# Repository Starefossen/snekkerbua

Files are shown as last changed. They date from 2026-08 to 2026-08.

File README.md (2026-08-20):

# snekkerbua



*der Hans gjør ting han (ennå) ikke kan*

Et verkstedrepo, én katalog per prosjekt. Alle prosjektene her er bygd på samme
måte: modellen er parametrisk og er den eneste kilden, manualen genereres ut av
solidene i stedet for å skrives ved siden av dem, og ingenting får finnes før
maskinen har sjekket det.

## Prosjekter

| | | |
|---|---|---|
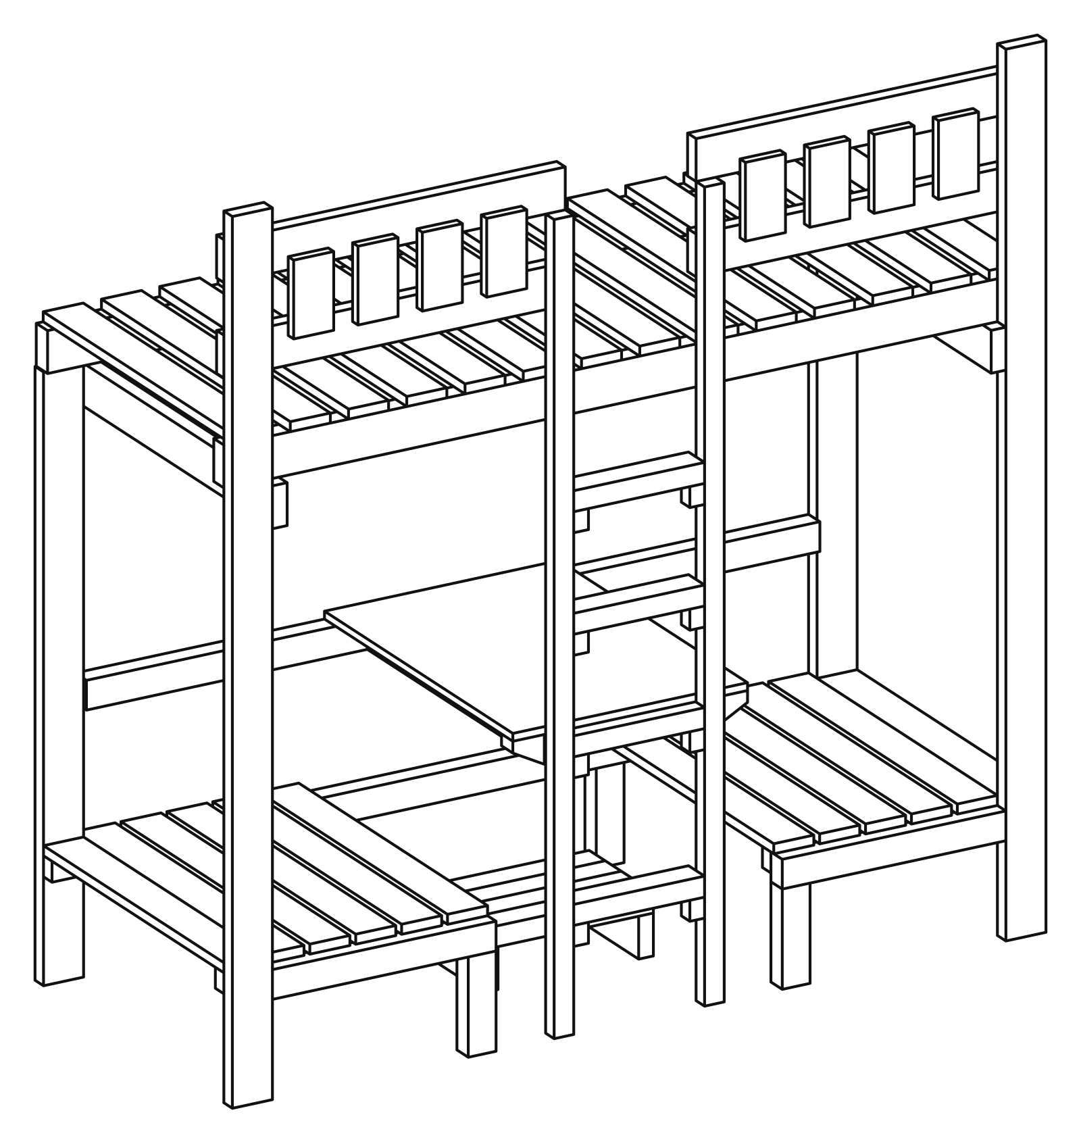
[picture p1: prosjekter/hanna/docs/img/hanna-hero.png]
HANNA
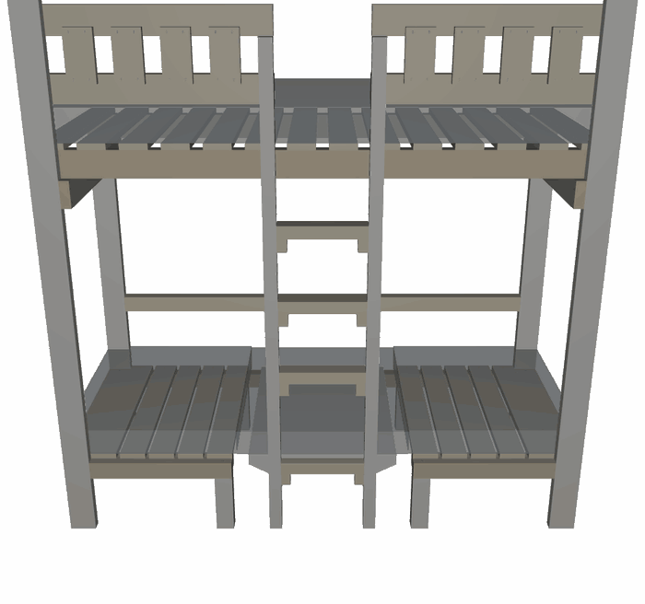
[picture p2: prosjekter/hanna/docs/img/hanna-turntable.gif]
Én omdreining
|  | **[HANNA](prosjekter/hanna/)** — en loftseng med sofa, bord og ekstraseng under, bygd for én nisje på 199 cm. 72 trestykker, 172 festemidler modellert som solider, og en trykkeklar monteringsmanual kompilert av modellen. |  |

## Felles

* **[PRAKSIS.md](PRAKSIS.md)** — reglene som gjelder på tvers av prosjektene.
* **[UTSTYR.md](UTSTYR.md)** — verktøyparken og innkjøpsplanen. Ett verksted, én
  beholdning, uansett hvor mange prosjekter som står i det.

Kortversjonen av PRAKSIS:

* **Én kilde.** Hvert tall i dokumentasjonen *kommer fra* modellen — ikke «er
  kopiert fra». Må to filer være enige om et tall, er tallet på feil sted.
* **En assert er et forhold**, utledet av fysikk eller en standard, aldri en
  gjentakelse av en konstant — og den sier hvor man retter det når den ryker.
* **Regler, ikke tilfeller.** Hvordan en ting behandles er en egenskap ved
  tingen, definert ett sted. Ingen `if` på et navn, ingen bryter noen må huske å
  skru på.
* **Et tegnet valg måles, det argumenteres ikke.** Prøven klippes ut av den
  ferdige siden, og en snubletråd-assert måler blekket etterpå.
* **Alt utledet er sjekket inn**, så `git diff --stat` etter et bygg *er*
  konsekvensanalysen.
* **Determinismen er en assert, ikke en forventning.** `mise run check` kjører
  hele kjeden to ganger og krever byte-identisk resultat.

## Kom i gang

Krever [`mise`](https://mise.jdx.dev/). Det er én oppgavefil, `mise.toml`, her på
rota, og hver oppgave kjører med sitt eget prosjekt som arbeidskatalog — så en
kommando er den samme kommandoen uansett hvor i treet du skriver den:

```bash
mise run build      # modellen + hver generert tabell og dokument
mise run montering  # tegn strektegningene på nytt
mise run check      # kjør hele kjeden to ganger, krev byte-identisk resultat
mise run pdf        # den trykkeklare manualen
```

Hele runden for HANNA er `mise run build && montering && check && pdf && usdz &&
film-check`. Forutsetningene for hvert prosjekt og resten av oppgavene står i
prosjektets egen README.

## Sjekk selv

Ikke ta badgen på ordet — tre kommandoer, fra ingenting:

```bash
git clone https://github.com/Starefossen/snekkerbua.git && cd snekkerbua
mise trust && mise run install   # python 3.11 + requirements.txt
mise run build && mise run montering && mise run check
```

`check` bygger hele kjeden to ganger og sammenligner SHA-256 av hver innsjekket,
utledet fil — tabellene, `docs/MONTERING.md`, hver eneste tegning, `parts.tsv`.
*Byte-identisk* betyr nøyaktig det: ikke «ser like ut», ikke «samme tall», de
samme bytene. Kan en kjøring gi to svar på det samme spørsmålet, er en diff på
tegningene ikke bevis på noe som helst, og resten av dette repoet er en
fortelling i stedet for et bevis. Den samme porten kjører på hver push —
[`.github/workflows/check.yml`](.github/workflows/check.yml). Å pushe en
`<prosjekt>-v*`-tag kjører i tillegg
[`release.yml`](.github/workflows/release.yml), som bygger
manualen og 3D-modellene på macOS (`.usdz`-kjeden går bare med Xcode) og legger
dem ved releasen.

Du trenger også `rsvg-convert` til PNG-ene (`brew install librsvg`, eller
`apt install librsvg2-bin`); workflow-fila er den nøyaktige lista. `mise run
pdf` vil ha to til: en Chrome å skrive ut med og poppler til å lese resultatet
tilbake med.

`git log --oneline` er designdagboka — hver commit er én beslutning, med
begrunnelsen i brødteksten.

## In English

**snekkerbua** is a workshop repo — one directory per project, each of them a
piece of furniture built from a parametric model. The model is the only source
of truth: every drawing, every table and every page of the printed assembly
manual is generated from the solids and machine-checked before it is allowed to
exist. The documentation is written in Norwegian, because that is the language
of whoever is standing at the saw. The proofs, on the other hand, run in CI:
`mise run check` builds the whole chain twice and demands byte-identical output,
and the badge at the top of this page is that gate.

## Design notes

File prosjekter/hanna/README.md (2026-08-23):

# HANNA — loftsengen der manualen kompileres, ikke skrives



*Det første prosjektet i [snekkerbua](../../README.md). Felles praksis:
[PRAKSIS.md](../../PRAKSIS.md) · verkstedets utstyr:
[UTSTYR.md](../../UTSTYR.md).*

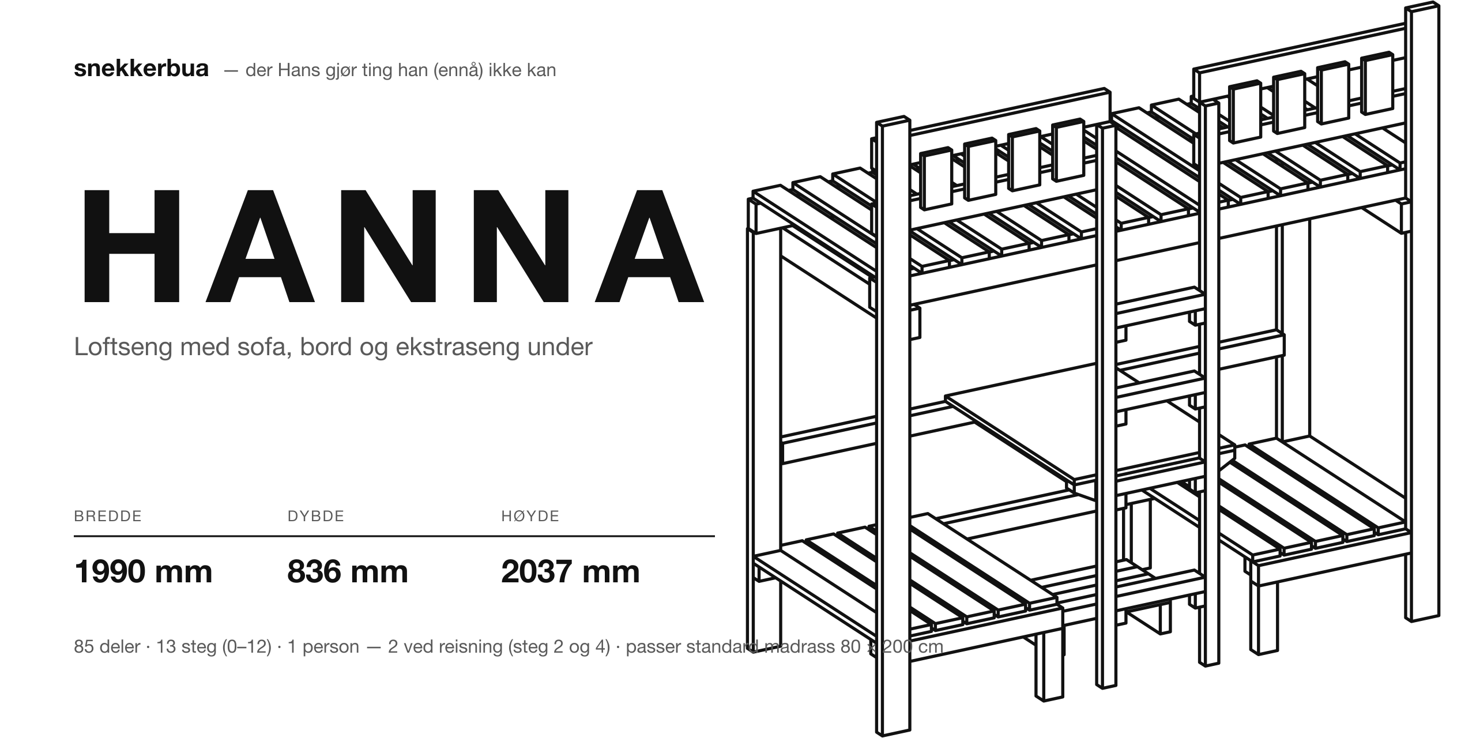
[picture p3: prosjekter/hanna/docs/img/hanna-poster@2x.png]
HANNA — loftseng med sofa, bord og ekstraseng under


Den ferdige sengen, én omdreining

*48 rammer av solidene, tatt opp med `usdrecord` og satt sammen av
`tools/render_animasjon.py`. Deterministisk: rammenummeret driver kameraet, så
samme modell gir samme bytes.*

En parametrisk loftseng i [build123d](https://github.com/gumyr/build123d) /
OpenCascade, bygd for én nisje på 199 cm mellom to vegger. Modellen er den
eneste kilden: **hver tegning, hver tabell og alle 32 sidene i byggeheftet og
alle 62 i referanseheftet genereres av solidene og maskinsjekkes før de får
finnes.** Ikke ett mål er skrevet av. Unntaket er fire skjemaark i `docs/schematics/`,
som er tegnet for hånd — der et tall på et slikt ark er i strid med en
generert tabell, er det tabellen som gjelder.

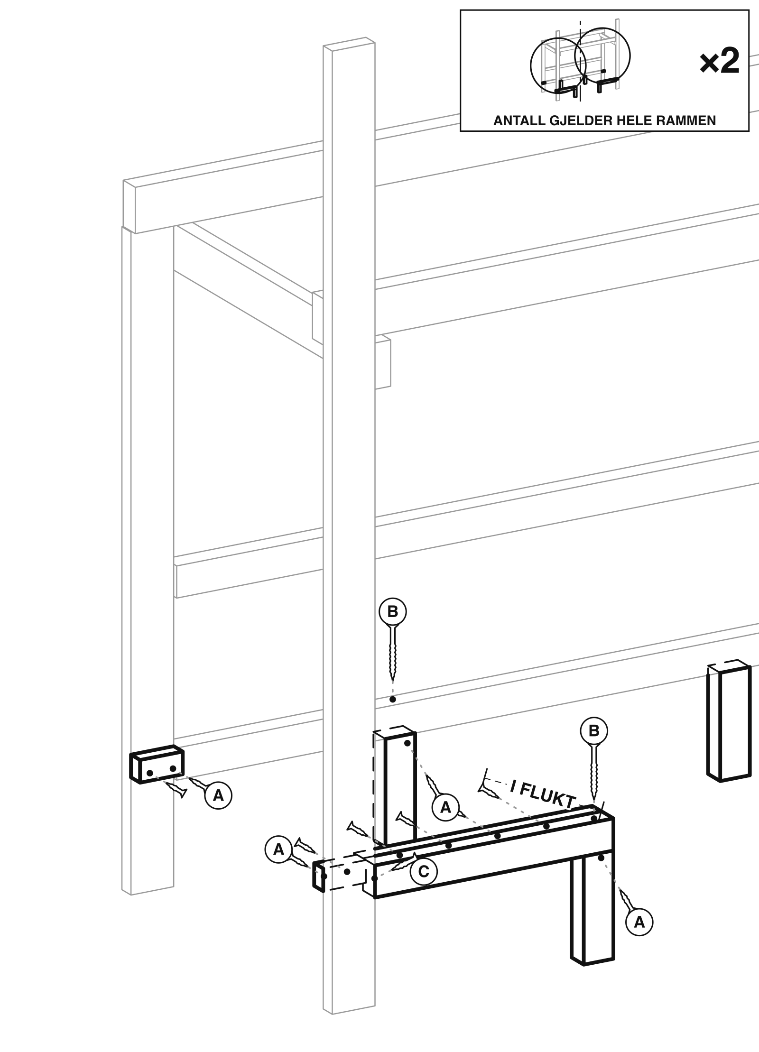
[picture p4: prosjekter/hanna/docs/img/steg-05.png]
Steg 5 i den genererte monteringsmanualen


*Steg 5, tegnet av `tools/render_lineart.py`. Sengen er en
skjult-linje-projeksjon av de virkelige B-rep-solidene. Hver skrue er en
modellert kropp, eksplodert langs sin egen drivakse, i sin sanne lengde.
Bokstavene, fyllkoden, antallene i beslaglegenden under bildet og halvsnittet
er alle utledet — og en assert som feller bygget måler det ferdige blekket og beviser at
hvert merke står på det festemiddelet det navngir.*

---

## Nøkkeltall

| | |
|---|---|
| **Ytre mål** | 1990 × 836 × 2037 mm — fyller nisjen fra vegg til vegg på 1990 mm, i et rom med 2450 mm takhøyde, og gir 1500 mm fri høyde under køya. Gjennomgående deler kappes 1984 mm, for et bord på 1990 mm lar seg ikke svinge inn i en åpning på 1990 mm |
| **Trevirke** | **85 stykker** i **5 dimensjoner** pluss én 18 mm kryssfinerplate — 55,07 løpemeter. Fordelingen: 23×98 34 stk. · 48×68 20 stk. · 36×48 16 stk. · 36×98 12 stk. · 48×98 2 stk. · plata 1 stk. 24 av de 85 stykkene er ett og samme stykke: spilen, 23×98 × 800 mm, kappet i én innstilling. Tallene telles av modellen og står nederst i [kapplista](docs/generated/kappliste.md) — `TOTAL 85 pcs 55.07 m in 5 timber profiles + 1 sheet` er det modellen skriver ut mens den bygger |
| **Stål** | **203 festemidler fordelt på 26 ledd**, **194 av dem modellert som solide kropper** — hode, forsenking, skaft og spiss, hver med sin egen drivvektor. De 9 som mangler er de to veggfestene, J14 og J12-V: de går rett inn i veggen og har ingen andre del å ende i, så de er plassert, men ikke modellert. **Ikke ett eneste hode står i en romvendt flate**, og det er en assert. Begge tallene skriver modellen ut selv — `203 festemidler plassert i 26 ledd` og `194 festemidler modellert som kropper` |
| **Kontroller** | **520 asserter i modellen** og 237 til i verktøyene, alle sammen stopper bygget — tallene er talt, ikke anslått, og de telles som `ast.Assert`-noder i syntakstreet, ikke med grep: en grep på linjer som begynner med ordet «assert» tar med brødtekst som gjør det samme, og gir 527 her. Metoden er `python -c "import ast,sys;print(sum(isinstance(n,ast.Assert) for n in ast.walk(ast.parse(open(sys.argv[1]).read()))))" generate_loftbed.py`, og den samme summen over `tools/*.py` (24 filer) — men ingen runde arver dem lenger: `tools/check_tall.py` teller dem på nytt i porten og feller bygget hvis denne tabellen sier noe annet enn det den finner. Skrueretningene er utledet av fysikk (7 av de 24 radene i [skrueretningene](docs/generated/skrueretninger.md) er tvunget av tykkelsene alene), og hver av dem har en plasseringslinje som sier hvor på delen hullet står — 25 linjer over 24 skrueretninger og alle 194 festemidlene, en bijeksjon som asserteres på det ferdige blekket. De to siste radene er veggfestene: de får hver sin egen plasseringslinje over 9 fester, satt etter stender og ikke etter mål, og telles derfor for seg; antall skruer må få plass på flaten de står på; hver del må røre resten av sengen og kollidere med ingenting |
| **Determinisme** | `mise run check` kjører hele kjeden to ganger og krever **142 byte-identiske artefakter** — de tre filmene inkludert, pluss et hash-stempel som feller porten hvis en film er eldre enn modellen den viser. 142 er ikke et anslag: det er `git ls-files` over nøyaktig de stiene `snap()` i `mise.toml` hasjer. Determinismen er en assert, ikke en forventning |
| **Ut av det** | **To trykkeklare PDF-er** med én kommando — et byggehefte på **32 sider** og et referansehefte på **62**, `pdfinfo docs/hanna.pdf` og `pdfinfo docs/hanna-referanse.pdf` sier hvor mange det ble. Byggeheftet er det som tas med til benken; referanseheftet blir stående i hylla. Pluss en ren billedmanual, en skrevet byggeveiledning, sju skjemategninger, to boresjablonger i 1:1, to bruksark og eksport til STEP / STL / GLB / USDZ |
| **Standarder** | Klaringer, rekkverkshøyder og vinduet for madrasstykkelse kommer av EN 747; kantavstander og skrueavstander av Eurokode 5 |
| **Menneskene** | **Fire referansekropper** — et barn på **1200 mm** bygget av 14 primitiver etter [AnthroKids](https://math.nist.gov/~SRessler/anthrokids/), to som sover og to som sitter, som ekte solider i modellen. De kappes ikke og bærer ingenting, men de **måler**: 426 mm over hodet på den som sitter rett opp, 902 mm over ansiktet til den som ligger nede — og de er grunnen til at bordplaten ble en pult: på 542 gikk et lår under den, men ikke et kne, og på 682 sitter begge barna med knærne inn under |

Sengens *funksjon* — en loftplate over en benk/bord/ekstraseng som stilles om
ved å flytte én plate mellom to høyder — er hentet fra en omstillbar loftseng
fra Hoppekids. Konstruksjonen, målene, hvert eneste ledd og all dokumentasjonen
her er egen.

---

## Sånn henger det sammen

```
generate_loftbed.py           modellen: mål, deler, festemidler, asserter
  ├─ tools/gen_doc_tables.py  → docs/generated/*.md, docs/MONTERING.md, byggesteg.json
  ├─ tools/render_lineart.py  → docs/img/steg-NN.svg/.png   (+ check_coverage)
  │    ├─ tools/render_cutpage.py   steg 0, kappeplanen
  │    ├─ tools/render_panel.py     steg 10, den løse platen
  │    ├─ tools/render_maalfigur.py forsteget, målefiguren av nisja
  │    └─ tools/render_maaltegning.py side 2, senga med sine seks mål
  ├─ tools/render_setedetalj.py → docs/schematics/setedetalj.svg
  ├─ tools/render_endelevation.py → docs/schematics/end-elevation.svg
  ├─ tools/render_spikerslag.py → docs/schematics/spikerslag.svg
  ├─ tools/render_boresjablong.py → docs/schematics/boresjablong-*.svg (1:1)
  ├─ tools/gen_figurhode.py   → figurikonenes hoder + landemerkene i PRAKSIS §4
  ├─ tools/gen_glyphs.py      → skrueikoner og piktogrammer
  ├─ tools/render_animasjon.py → docs/img/hanna-*.gif  (de tre filmene)
  ├─ tools/check_tall.py      → skriver ingenting: måler README-ens talte tall
  │                             og sveiper håndprosaens tall mot modellen
  ├─ tools/falsifiser.py      → skriver ingenting: feilinjiserer vokterne og
  │                             krever at hver enkelt feller
  └─ tools/build_pdf.py       → docs/hanna.pdf
       └─ tools/render_pdf_matrix.py → docs/img/hanna-manual-sider.png
```

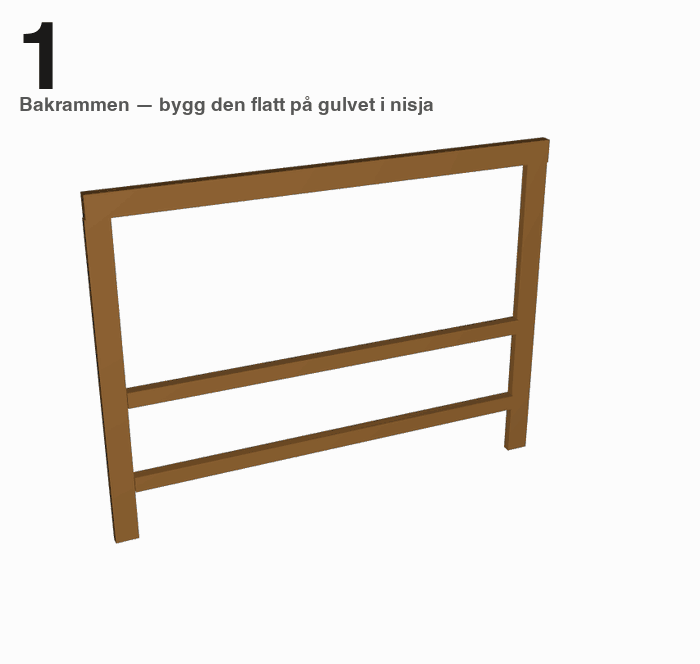
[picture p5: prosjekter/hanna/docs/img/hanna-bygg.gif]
Sengen bygger seg selv, steg 1–12


*De samme byggestegene manualen er paginert av, lest rett ut av
`docs/generated/byggesteg.json`: delene i hvert steg flyr inn langs den
retningen stegteksten sier du skal føre dem, skruene kommer når treet har
landet, og tallet i hjørnet er nummeret på den trykte siden. Ingenting her er en
andre beskrivelse av byggingen — det er byggebeskrivelsen, animert.*

**Én kilde.** Ethvert tall som står i dokumentasjonen *kommer fra* modellen —
ikke «er kopiert fra». Verktøyene importerer `generate_loftbed.py`, leser
modulglobalene og skriver ut. Ingen av dem definerer geometri, og ingen av dem
utleder noe modellen allerede vet. Den ene håndskrevne teksten,
`docs/ASSEMBLY.md`, har lov til å navngi deler og sitere leddnumre, men den skal
aldri gjenta et mål som et generert fragment allerede bærer — den lenker til
fragmentet i stedet. Regelen bak det: **hvis to filer må være enige om et tall,
er tallet på feil sted.**

**Tegningene er projeksjoner, ikke illustrasjoner.** `render_lineart.py` kjører
de virkelige solidene gjennom OpenCascades skjult-linje-fjerning — ingen nett —
og setter sammen én side per byggesteg: det som allerede står, i tynt grått, det
du fester nå, i tykk svart, og den skjulte strekningen av en ny del stiplet. Det
er konvensjonen en ren billedmanual bruker, den slags som ligger i flatpakken,
og den brukes her fordi modellen kan innfri den helt.

**En layoutmotor på regler, ikke på innstilte koordinater.** `tools/layout.py`
vet ingenting om senger. Den svarer på de to spørsmålene enhver påskrift stiller
— *hvor stor* og *hvor er det plass* — av regler, ikke av tall noen syntes så
bra ut. Hver strekbredde, radius, marg og punktstørrelse på en stegside er et
multiplum av ett mål, `penn = bbox-diagonalen / 400`, så hele pennsettet følger
det som tegnes. Hvor et merke havner er et poengsatt søk i et opptattfelt, der
kontakt med kroppen merket navngir er priset over hvilken som helst mengde hvitt
papir.

**Manualen kan ikke lyve.** Assertene sier nesten aldri at et tall er det
tallet — de er forhold, utledet av noe utenfor tegningen, og de sier hvor man
retter det når de ryker. Seks familier:

* **Skruelengde.** En gjennomgående skrue må gå klar av delen den drives fra og
  ende inne i den andre: `t(fra) < lengde < t(fra) + t(inn i)`. Der bare én
  retning holder målene, er retningen *utledet*, og leddtabellen får bare være
  enig.
* **Passer på flaten.** En rad med `n` skruer trenger `(n-1)·4d + 2·3d` mm
  virkelig kontaktflate. Da denne ble slått på, strøk den fire skruetall som
  hadde stått uimotsagt.
* **Kompletthet.** Hver del i nøyaktig ett steg; hvert ledd til stede så mange
  ganger som tabellen sier; handlelista lik de festemidlene som faktisk er
  plassert; og hver stegside må *tegne* minst ett feste av hver type den lister
  opp, med tegnet antall lik trykt antall. Den siste fanger tause tegninger — en
  del som står i tabellen og aldri blir vist festet.
* **Plasseringsmålene på stegarkene.** Hvert steg skylder de få målene som
  plasserer treet det legger til — avstanden fra noe som allerede står til
  kanten av delen, utledet av kroppene og leddene og aldri satt for hånd. Hver
  pil måles tilbake ut av det ferdige `<path>`-et, gjennom kameraet, mot
  modellens eget tall; og en bijeksjon holder «tegnet på arket» mot «skyldt av
  steget», så et mål ikke kan forsvinne stille. Høyder måles nedover, aldri fra
  en fot og aldri fra gulvet — X6 regel 2, denne gangen på tegningen.
* **Orientering.** Et beslag som er skrudd fast i tre er ikke nødvendigvis
  riktig vei. Et beslag som *bærer* noe må ha den vannrette fliken skrudd rett
  opp, i undersiden av det den bærer.
* **Avstiving.** Hva holder kroppen et steg nettopp laget, i det byggmesteren
  slipper den? Målt på festene: tre fester som *ikke* ligger på én linje låser
  en stiv kropp; ligger de på én, kan kroppen dreie om den, og om det betyr
  noe er en arm mot festenes egen rekkevidde. En kropp som ennå er et hengsel
  får et avstivingspunkt i steget sitt — enten «monter denne permanente delen
  straks» (utledet: en senere del som allerede kan skrus både til kroppen og
  til noe som står) eller «sett en midlertidig lekt hit». Regelen kom av
  byggherrens rapport etter at senga var bygget, og en assert holder den til
  de to kroppene han navnga.

**Og assertene prøves selv.** En assert som aldri har feilet er ikke en bevist
assert, den er en uprøvd en. `tools/falsifiser.py` tar de asserene som VOKTER —
de som måler ferdig blekk eller plasserte kropper på tvers av filer, der
«bestått» og «hadde ingenting å si» ser like ut — kjører dem først rene på
dagens innhold, og perturberer så én ting om gangen i minnet: bærer bakrammen
inn gjennom en åpning like bred som seg selv, tar et ledd ut av steg 0s
utsettelsesliste, gir et veggfeste et X-mål som fasit, lar et stegark slutte
stille å tegne et plasseringsmål det skylder, gir en løs kropp et feste ute i
sitt eget frie hjørne så avstivingsregelen slutter å fyre, lar README
gjenfortelle et tall som har flyttet seg. Hver eneste feilinjisering må felle sin assert.
Ingen av dem rører en fil på disk, og porten kjører dem.

Og siden alt utledet er sjekket inn — nettopp for at `git diff --stat` etter et
bygg *skal være* konsekvensanalysen — må kjeden selv være reproduserbar.
`mise run check` kjører den to ganger og sammenligner sjekksummer. Ryker den, er
det aldri en modellendring: det er en usortert `dict`, et tidsstempel, en
`id()`-sortering eller en flyttallssum som avhenger av rekkefølgen.

Den samme porten kjører på hver push til `main` — badgen øverst er
[`.github/workflows/check.yml`](../../.github/workflows/check.yml), som er
`build`, `montering` og `check` på en maskin som starter med ingenting. Vil du
kjøre den selv: **[Sjekk selv](../../README.md#sjekk-selv)**.

---

## Kom i gang

Krever [`mise`](https://mise.jdx.dev/). Resten er
`pip install -r requirements.txt` (build123d, markdown) pluss `rsvg-convert` til
PNG-ene. PDF-en vil i tillegg ha en headless Chrome å skrive ut med og poppler
til å lese resultatet tilbake med — sidetallene i innholdsfortegnelsen slås opp
i den ferdige PDF-en, de gjettes ikke: `brew install librsvg poppler` (eller
`apt install librsvg2-bin poppler-utils`).

Oppgavefila er `mise.toml` på rota av repoet, og hver oppgave kjører allerede i
denne katalogen, så disse virker uendret uansett hvor i treet du står:

```bash
mise run build      # modellen + alle genererte tabeller + docs/MONTERING.md
mise run montering  # tegn strektegningene i docs/img/ på nytt
mise run check      # kjør hele kjeden to ganger, krev byte-identisk resultat
mise run pdf        # docs/hanna.pdf, 32 sider + docs/hanna-referanse.pdf, 62 sider
```

| Oppgave | Hva den gjør |
|---|---|
| `build` | Bygger og validerer modellen, eksporterer den, skriver hvert fragment i `docs/generated/` og `docs/MONTERING.md` |
| `build-full` | Det samme pluss det tunge: `.glb` og skjult-linje-projeksjonene av hele modellen |
| `montering` | Tegner forsiden og én strektegning per byggesteg til `docs/img/` |
| `setedetalj` | Tegner detaljarket for skråskruesetene til `docs/schematics/setedetalj.svg` |
| `endelevation` | Tegner kortsnittet (sengen sett fra enden) til `docs/schematics/end-elevation.svg` |
| `spikerslag` | Tegner bakveggen som oppriss med sonene som skal ha spikerslag til `docs/schematics/spikerslag.svg` |
| `boresjablong` | Tegner de to 1:1-boresjablongene til `docs/schematics/boresjablong-*.svg` — arkene som skrives ut i full størrelse, klippes fra hverandre og legges på treet |
| `figurhode` | Regner hodet på konturfiguren inn i de fire figurikonene og skriver landemerketabellene i PRAKSIS §4 |
| `check` | Determinismeasserten: to fulle kjøringer, 142 artefakter, byte-identisk eller feil — og etterpå `check_tall` (README-ens talte tall + tallsveipet over håndprosaen) og `falsifiser` (feilinjisering av vokterne) |
| `pdf` | Setter sammen `docs/hanna.pdf` (byggeheftet) og `docs/hanna-referanse.pdf` av de innsjekkede dokumentene (trenger ikke build123d) |
| `schematics` | Rendrer `docs/schematics/*.svg` til PNG for korrektur |
| `usdz` | Konverterer nettene til `.usdz` for Quick Look / Xcode / AR, ett materiale per fargegruppe |
| `render`, `render-validate` | Skyggelagte forhåndsvisninger og de fem designvalideringsbildene (macOS `usdrecord`) |
| `montering-skyggelagt` | Skyggelagte referansebilder av de samme byggestegene |
| `view`, `view-usdz` | Åpner modellen i FreeCAD / Quick Look |

---

## Kart over prosjektet

Alt under ligger i `prosjekter/hanna/`, og alle stier er relative til den.

| Sti | |
|---|---|
| `generate_loftbed.py` | Modellen. Mål, leddtabellen, festemidlene som solider, og assertene |
| `tools/` | Alt som leser modellen: dokumenttabeller, strektegninger, kappeside, plateside, ikoner, PDF, USD-hjelpere |
| `docs/generated/` | Maskinskrevet, aldri redigert for hånd: kappliste, innkjøpsliste, nøkkelmål, beslagliste, skrueretninger, stegtekst, `byggesteg.json` |
| `docs/img/`, `docs/schematics/` | De innsjekkede tegningene — så manualen kan leses og skrives ut på en maskin uten noe av denne verktøykjeden |
| `docs/hanna.pdf` | Byggeheftet på 32 sider — stegsidene og det som trengs ved benken. Bevisst utenfor git; verktøyet ligger i repoet, og fila er én `mise run pdf` unna |
| `docs/hanna-referanse.pdf` | Referanseheftet på 62 sider — begrunnelsene, tallene og de øvrige tegningene. Samme sak: bygges, ikke sjekkes inn |
| `parts.tsv` | Innsjekket regresjonsavtrykk: navn, fargegruppe og omskrevet boks for hver del, i begge stillinger. En diff på den er diffen på modellen |
| `v1/` | Den første køyesengrammen for nisjen, beholdt som historikk |

---

## Byggedokumentene

Dette er det den som står ved sagen faktisk leser.

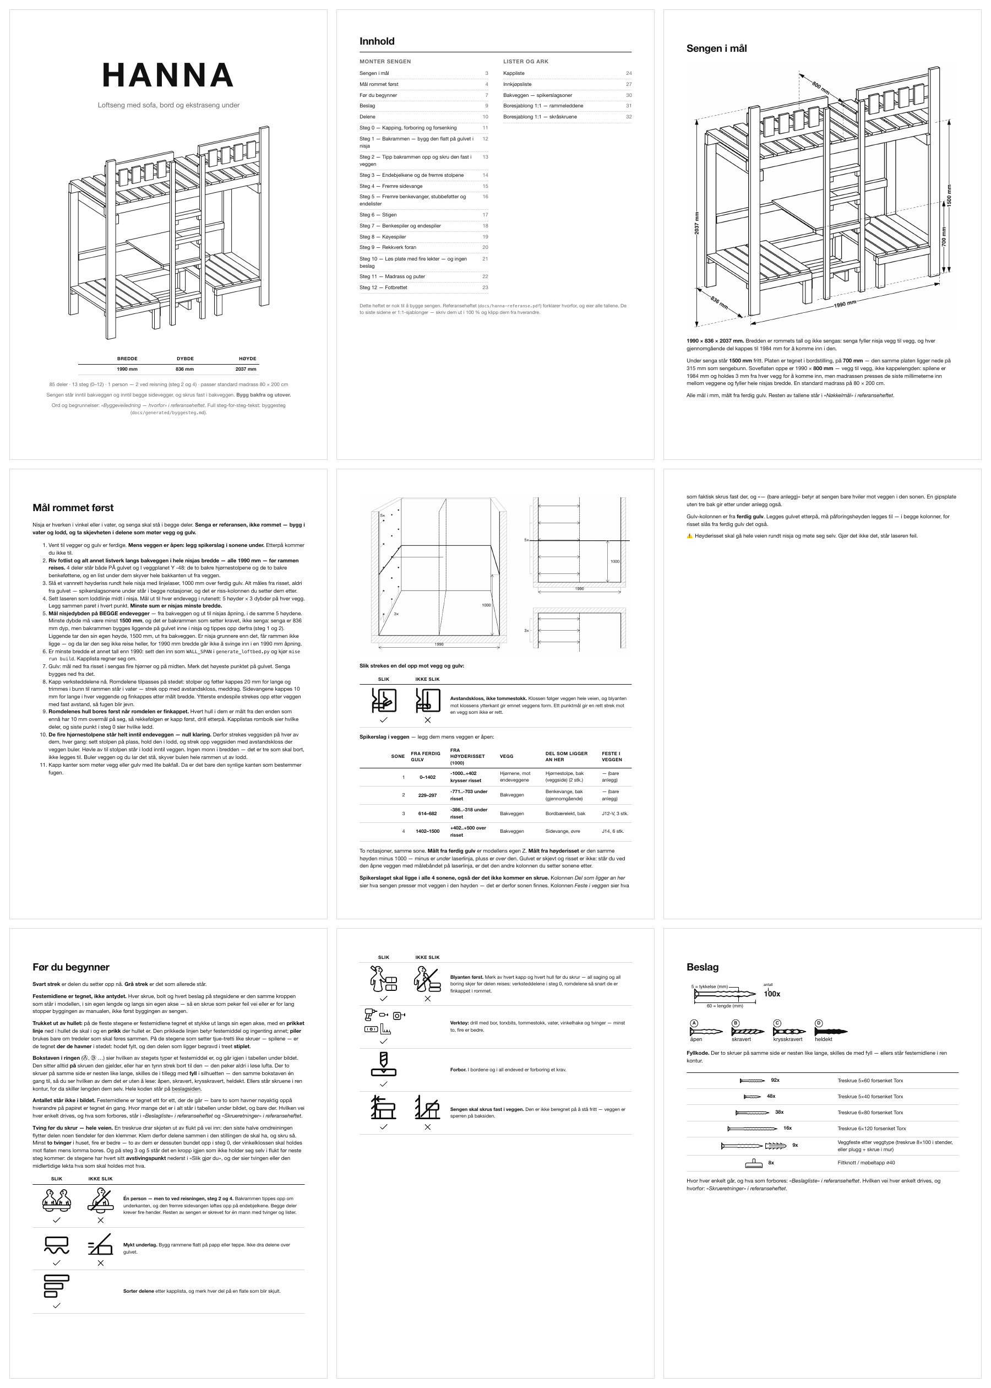
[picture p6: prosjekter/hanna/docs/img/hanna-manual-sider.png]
De ni første sidene i byggeheftet, tre og tre


*De ni første av byggeheftets 32 sider, lest rett tilbake ut av `docs/hanna.pdf`
av `tools/render_pdf_matrix.py`: forsiden, innholdet, senga med sine seks mål,
de tre sidene om å måle rommet, de to sidene med konvensjoner og sikkerhet, og
beslagsiden. Hver eneste side på det arket er kompilert —
ingenting på det er satt opp for hånd. Den ferdige PDF-en henger ved
[releasen `hanna-v1.0`](https://github.com/Starefossen/snekkerbua/releases/tag/hanna-v1.0)
om du heller vil lese den enn å bygge den.*

* **[docs/MONTERING.md](docs/MONTERING.md)** — billedmanualen. Tretten steg (0–12),
  én tegning per steg, nesten ingen ord. Generert.
* **[docs/ASSEMBLY.md](docs/ASSEMBLY.md)** — begrunnelsene: verktøy, trevirke,
  hvert ledd J1…J18, byggerekkefølgen og hvorfor den må være slik, madrass og
  puter, sikkerhet, og tillegget om lastveiene. Den ene håndskrevne fila.
* **[docs/generated/](docs/generated/)** — kappliste, innkjøpsliste med
  kappeplan bord for bord, nøkkelmål, beslagliste og skrueretninger.
* `docs/hanna.pdf` — stegsidene og resten av byggeheftet, satt opp for trykk,
  og `docs/hanna-referanse.pdf` — begrunnelsene og tallene. Ikke innsjekket;
  kjør `mise run pdf`, så kommer de, identiske, ut av de innsjekkede
  dokumentene.

## For den som skal endre modellen

To filer, ingen av dem en del av den trykte manualen.

* **[../../PRAKSIS.md](../../PRAKSIS.md)** — verkstedets felles praksis:
  én-kilde-regelen, hva som gjør en assert verdt å skrive, regler framfor
  tilfeller, tegnekonvensjonene som holder på tvers av prosjektene, og hvorfor
  determinismen er en assert.
* **[docs/PRAKSIS.md](docs/PRAKSIS.md)** — HANNAs egen: kjeden ut av
  `generate_loftbed.py`, de fem assertfamiliene og standardene de kommer av,
  boksinvarianten og dens ene kileformede unntak, hvor grensen mellom stål og
  tre går, og hver eneste konvensjon i billedspråket i denne manualen —
  fyllkoder, merkeregler, kjeden i et beslaghjørne, ikonspesifikasjonen — med
  grunnen bak hver av dem.

## Grenser

Dette er ett produkt, ikke et møbelrammeverk. Alt er akseparallelle bokser med
ett unntak: alle kutt er 90° «på to nær», som [kapplista](docs/generated/kappliste.md)
sier det — de to kilelektene under platens forkant sages i ett rett snitt på
langs, fra full 68 mm ved roten ned til 27 mm ved tuppen, altså 28,0°. Ellers
finnes verken gjæring eller kurve i sengen, og tegnemotoren går ut fra
rektangulære solider i en ortografisk projeksjon. Modellen er parametrisk
i den forstand at målene er konstanter som holdes sammen av asserter — endrer du
nisjebredden eller hoveddimensjonen på virket, sier kjeden tydelig fra om hva
som ikke lenger går opp — men den er ingen konfigurator, og sengen er laget for
én bestemt veggside og lar seg ikke snu.

## In English

**HANNA** is a parametric loft bed — a bed platform over a bench, table and
spare bed, built for one 199 cm alcove between two walls — modelled in build123d
/ OpenCascade. The model is the only source of truth: every drawing, every
table, all 32 pages of the printed build booklet and all 62 of its reference
companion are generated from the solids and machine-checked before they are
allowed to exist, and no number is hand-transcribed. Four schematic sheets in `docs/schematics/` are the one
exception: they are drawn by hand, and where one of them disagrees with a
generated table, the table wins. The documentation is in Norwegian, because
that is what someone standing at the saw actually reads. The proofs run in CI:
`mise run check` builds the whole chain twice and demands 142 byte-identical
artefacts, and the badge at the top of this page is that gate.

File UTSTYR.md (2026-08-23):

# Utstyr — verktøypark og kjøpsplan

Levende oversikt over hva verkstedet har og hva som står for tur. Verktøyparken
er én, uansett hvor mange prosjekter som står i bua, så denne fila ligger på
rota og er felles for alle. Oppdateres ved kjøp.

## Batterisystem

**Ryobi ONE+ 18V** — batterier og lader i hus.

**Kjøpsstrategi (besluttet aug. 2026):** hold deg til ONE+ så langt det er
mulig, og velg **børsteløs motor (HP-serien)** der den finnes. Unntak
aksepteres kun der (a) klassen ikke finnes som HP og lasten er lett/
intermitterende (multiverktøy-logikken), eller (b) ONE+ mangler verktøyklassen
helt. Verifiser alltid at modellnummeret faktisk er HP/børsteløs ved kjøp —
Ryobi selger ofte begge varianter side om side.

## Eid utstyr

### Kapp-/gjærsag — Ryobi R18MS216-0 (ONE+)

| Egenskap | Verdi | Betyr i praksis |
|---|---|---|
| Blad | 216 mm, 48 tenner karbid | Fine snitt i høvlet virke |
| Snittdybde 90°/45° | 70 / 48 mm | Dekker alle HANNA-profilene (36×98, 48×98 osv.) på høykant/flask |
| Glideskinne | Teleskopisk | Brede emner — **maks snittbredde er udokumentert: mål og før inn her** |
| Gjæring/vinkel | H/V 50°/47°, laser, LED | HANNA er 90° på alt unntatt to navngitte kutt: bladet vippes **25°** (vinkelkloss J8-B) og **30°** (vinkelkloss J10) når sålen kappes av under det ferdigborede ⌀18-hullet. Det tredje ikke-90°-kuttet i senga — kilelektenes **28,0°** skråkapp, 68 → 27 mm over 77 mm — er *ikke* en kappsagjobb: håndsag eller båndsag, med limflaten urørt |
| Ekstra | Sponpose, tvinge, sideforlengere, bærbar | |

**Dekker:** all kapping av konstruksjonsvirke og lister. **Dekker ikke:**
platekutt, kløyving/langsgående kutt (→ se kjøpsplan).

### Bor-/skrutrekker med slag — Ryobi ONE+ HP RPD18C1-0

| Egenskap | Verdi | Betyr i praksis |
|---|---|---|
| Dreiemoment | 60 Nm, 24-trinns kobling | Driver 6 mm skruer i heltre uten å mukke (HANNAs rammeskruer) |
| Chuck | 13 mm metall | Tar forstnerbor og store trebor (maks 38 mm i tre) |
| Slagfunksjon | 0–27 200 slag/min, 13 mm i mur | **Veggfeste i mur/betong dekket** — plugg + skrue (HANNA J14 og J12-V) |
| Motor | Børsteløs, 2 gir (450/1700 o/min) | Lavt gir til store bor og skruing med følelse |
| Bor HANNA krever | ⌀12 kontrabor · ⌀8 · brad-point ⌀6 og ⌀3,5 · forboring ⌀3 / ⌀3,5 / ⌀4 / ⌀6 · forstner ⌀18 / ⌀40 | **⌀12** tar de 16 kontraborene under platen: 12 rette à 41 mm i de to avstivningslektene (J13a), 4 i de skråkappede kilene (J13b) som grunner ut mot tuppen. **⌀8** er gjennomgangshullet for veggfestene, forsenket for hodet — to ledd i to høyder: J14 gjennom den bakre sidevangen og J12-V gjennom bordbærelekta. **Brad-point ⌀6** (J8-B) og **⌀3,5** (J10) settes i den flate bunnen av vinkelklossens ⌀18-lomme og retter seg selv inn i skruens vinkel — en vanlig spiralbor med senterspiss vandrer der |

**Dekker:** boring tre/stål/mur, all skruing, forboring/forsenking.

### Overfres — Ryobi ONE+ HP RTR18C-0 (kjøpt aug. 2026)

| Egenskap | Verdi | Betyr i praksis |
|---|---|---|
| Klasse | Kantfres (trimfres), uten innstikk | Kant-entré-jobber: avrunding, flush-trim, noter fra kanten |
| Tange | 6 / 6,35 mm | Suppler med **8–10 mm rettfres på 6 mm skaft** ved behov — 12 mm på 6 mm skaft er mangelvare |
| Motor | Børsteløs (HP) | |

**Dekker:** avrundede kanter (barnesikkert + pent), flush-lommer for beslag,
flush-trim. **Dekker ikke:** innstikk midt på flaten (ingen dykk-funksjon) —
runde sete-forsenkninger tas fortsatt med **forstnerbor i drillen**, og
skråskruene bores NED I hullet i de to hjemmelagde vinkelklossene
(se kapplista) — én kloss per vinkel, og hver av dem trenger to tvinger
(som er ett av mange bruk: se håndverktøylista under).

### Skinnesag — Ryobi ONE+ HP RPLS18X-0 (kjøpt aug. 2026)

| Egenskap | Verdi | Betyr i praksis |
|---|---|---|
| Klasse | Dykksag med skinne, børsteløs (HP) | Platekutt (HANNA-platen!) og kløyving/langsgående kutt |
| Skinner | 2 × 70 cm inkludert | Skjøtes for lange kutt; rette snitt uten oppflising |

**Dekker:** kapasitetsgapet kappsaga ikke tok — plater og langsgående kutt.
⚠️ Husk: RAK03SR-«skinnen» er en klemlist for andre sager, ikke til denne.

### Multiverktøy — Ryobi ONE+ HP RMT18X-0 (kjøpt aug. 2026)

**Dekker:** flush-kutt av lister (HANNA står i nisje med gulvlister),
justering på plass, detaljsliping i kroker.

### Fresestål — Ryobi 5-pakk (6,35 mm skaft)

Til overfresen. **Før inn innholdet ved anledning** (typisk rettfres,
flush-trim, avrunding, fas). Avrundingsstålet tar kantbrytningen på HANNA;
merknaden om **8–10 mm rettfres på 6 mm skaft** som suppleringskjøp står
til innholdet er verifisert mot behovet.

### Håndverktøy (fra HANNA-byggelista, antatt i hus)

Vater, vinkelhake, tommestokk/målebånd, **skrutvinger — minst 2, helst 4**,
sag (hånd), Torx-bits, blyant/syl, skrustikke.

⚠️ **Tvingene er standardverktøy, ikke jiggutstyr.** De stod her lenge som «×2»
fordi vinkelklossen til skråskruene trenger to av dem. Det er ett bruk av
mange: en treskrue drar skjøten ut av flukt på vei inn, så delene klemmes
sammen i riktig stilling *før* skruen går i — hver gang, ikke bare i jiggen.
Og før sengen har fått forankring holder ikke alt seg selv i flukt: HANNA har
byggesteg der en kropp henger i ett feste til neste steg binder den, og der er
tvingen eller den midlertidige lekta det som holder fluktet (se
`prosjekter/hanna/docs/PRAKSIS.md` §2, «Avstiving»). To tvinger er minimum; med fire slipper du
å velge mellom å holde og å skru.

## Kjøpsplan — prioritert

Rangert etter hva som låser opp mest per krone, gitt eksisterende park:

| # | Verktøy | Hvorfor / hva det låser opp | Merknad (ONE+/HP-status) |
|---|---|---|---|
| 1 | **Eksentersliper — ONE+ HP-variant** | Finish-kvalitet på alt; HANNA: 72 deler skal slipes før maling | Kjøp før malejobben. HP børsteløs-utgave finnes i sortimentet — verifiser modellnr. (ikke ta brushed R18ROS hvis HP står ved siden av) |
| 2 | **Linjelaser, selvnivellerende — 360° horisontal + vertikal** | Høyderiss rundt nisja og loddlinje midt i den. Uten den kan ikke romdelene i HANNA kappes: nisjas minste bredde og gulvets høyeste punkt måles fra risset, ikke fra gulvet | **Lånt eksemplar dekker behovet inntil videre — ikke kjøpt.** Anbefaling når den skal kjøpes: **Bosch UniversalLevel 360 Premium Set**, ~1 730 kr, ±0,4 mm/m, 360° horisontal linje **og** vertikal linje, stativ inkludert. Budsjett: **Jula Meec 360°**, 999 kr. ⚠️ **Unngå Bosch PLL 360-1** — den mangler vertikal linje, og loddlinja midt i nisja er halve jobben. Batteriuavhengig. **Trengs FØR kapp av romdelene** |
| 3 | **Flere tvinger** (4+ F-tvinger, 2 hurtigtvinger) | Ikke «tredje hånd» ved anledning, men standardverktøy ved **hver** skruing: skruen flytter delen ut av flukt på vei inn. I tillegg holder de kroppene som ennå ikke har forankring — se avstivingspunktene i byggeheftet | Batteriuavhengig; billigst per nytte på lista |
| 4 | **Forstnerbor-sett** | Flatbunnede hull: HANNA trenger ⌀18 (skråskrue-setene) og ⌀40 (filtknottene) | Drives av drillen (13 mm chuck ✓). **Trengs til HANNA-byggingen** |
| 5 | **Japansk sag (ryoba) + stemjern-sett** | Rene hakk og presisjon for hånd; billigste vei til skjult treskjøt | Batteriuavhengig, ~200–400 kr |
| 6 | Blokkhøvel | Finjustering av skribede føtter og kanter som møter vegg — de siste millimeterne etter finkapp | Valgfri: båndsliper eller pussekloss duger. Batteriuavhengig |
| 7 | Dyvel-jig, lommehullsjig | Skjulte skjøter i fremtidige synlige møbler | Ved behov |

**Avmeldt etter strategivalget:** R18CS-0 (brushed sirkelsag, skinneinkompatibel),
RCK183G-0-pakken (inneholder brushed sirkelsag + stikksag vi ikke trenger ennå),
stikksag generelt (venter på et prosjekt med kurver — velg da HP-variant om den finnes).

**Avmeldt bevisst — laseravstandsmåler.** Den måler punkt til punkt og lyver
gjerne en centimeter på en skjev endevegg. Jobben i HANNA er ikke å lese ett
tall, men å legge et **plan**: høyderisset rundt hele nisja og loddlinja midt
i den. Laserplan + tommestokk måler denne jobben bedre enn en avstandsmåler
gjør, og nisjebredden leses uansett som en sum av to mål ut fra loddlinja.

## Forbruk/småting å ha liggende

Treskruer forsenket Torx i spennet 5×40–6×120 (HANNA-lista gir startlager),
forborings-/forsenkerbits, slipepapir K80–K180, trelim, neodymmagneter ⌀10–15
(anti-skrangle), filtknotter.

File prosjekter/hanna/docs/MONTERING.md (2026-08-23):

<!-- GENERERT AV tools/gen_doc_tables.py under `mise run build`.
     IKKE REDIGER FOR HÅND. Strektegningene lages av
     `mise run montering` (tools/render_lineart.py). -->

# HANNA

## Loftseng med sofa, bord og ekstraseng under

HANNA

| Bredde | Dybde | Høyde |
|---:|---:|---:|
| **1990 mm** | **836 mm** | **2037 mm** |

85 deler · 13 steg (0–12) · 1 person — 2 ved reisning (steg 2 og 4) · passer standard madrass 80 × 200 cm

Sengen står inntil bakveggen og inntil begge sidevegger, og skrus fast i bakveggen. **Bygg bakfra og utover.**

Ord og begrunnelser: [ASSEMBLY.md](ASSEMBLY.md). Full steg-for-steg-tekst: [byggesteg](generated/byggesteg.md).

---

# Sengen i mål

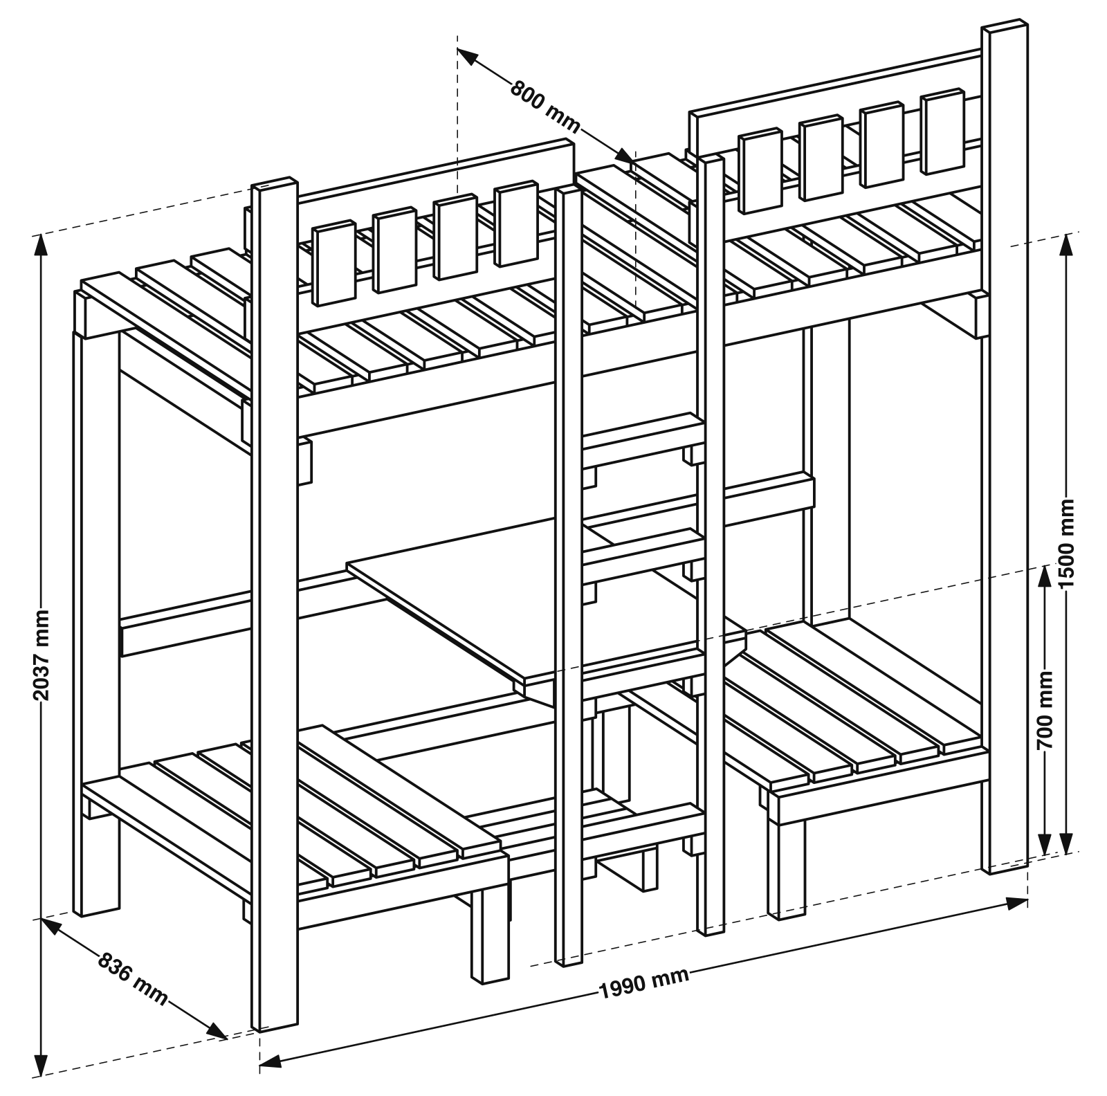
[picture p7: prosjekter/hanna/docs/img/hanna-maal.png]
Senga i bordstilling, sett på skrå, med seks mål: 1990 mm bredde, 836 mm dybde, 2037 mm høyde, 1500 mm fri høyde under, 700 mm pulthøyde og 800 mm soveflate på tvers


**1990 × 836 × 2037 mm.** Bredden er rommets tall og ikke sengas: senga fyller nisja vegg til vegg, og hver gjennomgående del kappes til 1984 mm for å komme inn i den.

Under senga står **1500 mm** fritt. Platen er tegnet i bordstilling, på **700 mm** — den samme platen ligger nede på 315 mm som sengebunn. Soveflaten oppe er 1990 × **800 mm** — vegg til vegg, ikke kappelengden: spilene er 1984 mm og holdes 3 mm fra hver vegg for å komme inn, men madrassen presses de siste millimeterne inn mellom veggene og fyller hele nisjas bredde. En standard madrass på 80 × 200 cm.

Alle mål i mm, målt fra ferdig gulv. Resten av tallene står i [nøkkelmål](generated/nokkelmal.md).

---

# Mål rommet først

Nisja er hverken i vinkel eller i vater, og senga skal stå i begge deler. **Senga er referansen, ikke rommet — bygg i vater og lodd, og ta skjevheten i delene som møter vegg og gulv.**

1. Vent til vegger og gulv er ferdige. **Mens veggen er åpen: legg spikerslag i sonene under.** Etterpå kommer du ikke til.
2. **Riv fotlist og alt annet listverk langs bakveggen i hele nisjas bredde — alle 1990 mm — før rammen reises.** 4 deler står både PÅ gulvet og I veggplanet Y -48: de to bakre hjørnestolpene og de to bakre benkeføttene, og en list under dem skyver hele bakkanten ut fra veggen.
3. Slå et vannrett høyderiss rundt hele nisja med linjelaser, 1000 mm over ferdig gulv. Alt måles fra risset, aldri fra gulvet — spikerslagsonene under står i begge notasjoner, og det er riss-kolonnen du setter dem etter.
4. Sett laseren som loddlinje midt i nisja. Mål ut til hver endevegg i rutenett: 5 høyder × 3 dybder på hver vegg. Legg sammen paret i hvert punkt. **Minste sum er nisjas minste bredde.**
5. **Mål nisjedybden på BEGGE endevegger** — fra bakveggen og ut til nisjas åpning, i de samme 5 høydene. Minste dybde må være minst **1500 mm**, og det er bakrammen som setter kravet, ikke senga: senga er 836 mm dyp, men bakrammen bygges liggende på gulvet inne i nisja og tippes opp derfra (steg 1 og 2). Liggende tar den sin egen høyde, 1500 mm, ut fra bakveggen. Er nisja grunnere enn det, får rammen ikke ligge — og da lar den seg ikke reise heller, for 1990 mm bredde går ikke å svinge inn i en 1990 mm åpning.
6. Er minste bredde et annet tall enn 1990: sett den inn som `WALL_SPAN` i `generate_loftbed.py` og kjør `mise run build`. Kapplista regner seg om.
7. Gulv: mål ned fra risset i sengas fire hjørner og på midten. Merk det høyeste punktet på gulvet. Senga bygges ned fra det.
8. Kapp verksteddelene nå. Romdelene tilpasses på stedet: stolper og føtter kappes 20 mm for lange og trimmes i bunn til rammen står i vater — strek opp med avstandskloss, meddrag. Sidevangene kappes 10 mm for lange i hver veggende og finkappes etter målt bredde. Ytterste endespile strekes opp etter veggen med fast avstand, så fugen blir jevn.
9. **Romdelenes hull bores først når romdelen er finkappet.** Hvert hull i dem er målt fra den enden som ennå har 10 mm overmål på seg, så rekkefølgen er kapp først, drill etterpå. Kapplistas rombolk sier hvilke deler, og siste punkt i steg 0 sier hvilke ledd.
10. **De fire hjørnestolpene står helt inntil endeveggen — null klaring.** Derfor strekes veggsiden på hver av dem, hver gang: sett stolpen på plass, hold den i lodd, og strek opp veggsiden med avstandskloss der veggen buler. Høvle av til stolpen står i lodd inntil veggen. Ingen monn i bredden — det er tre som skal bort, ikke legges til. Buler veggen og du lar det stå, skyver bulen hele rammen ut av lodd.
11. Kapp kanter som møter vegg eller gulv med lite bakfall. Da er det bare den synlige kanten som bestemmer fugen.

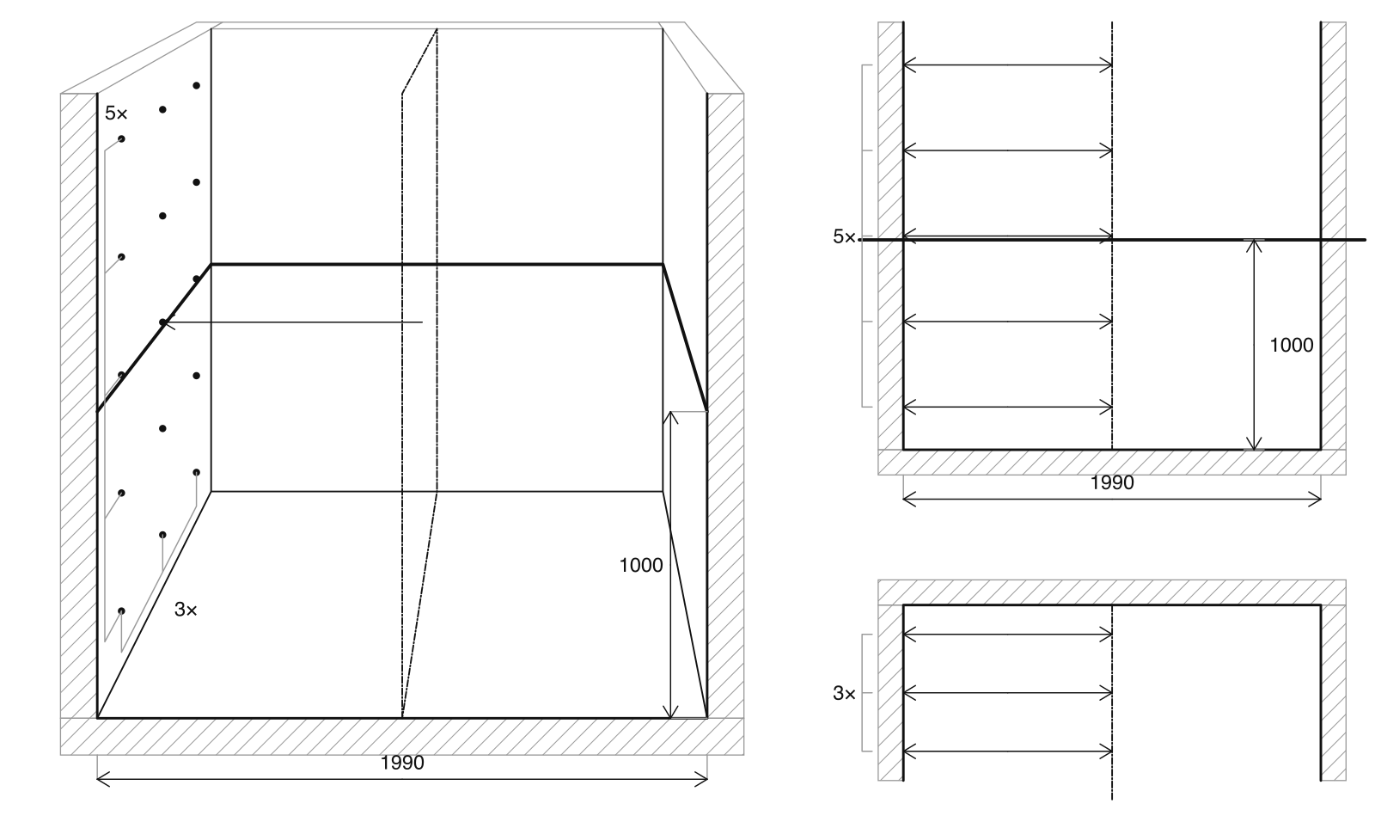
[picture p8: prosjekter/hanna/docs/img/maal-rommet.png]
Nisja som rom, med oppriss og plan ved siden av: høyderisset 1000 mm over ferdig gulv går som en ring rundt alle tre veggene, loddplanet står midt i nisja, og hver endevegg måles i 5 høyder × 3 dybder


**Slik strekes en del opp mot vegg og gulv:**

| Slik | Ikke slik | |
|:---:|:---:|---|
| meddrag-ja ja | punktmaal-nei nei | **Avstandskloss, ikke tommestokk.** Klossen følger veggen hele veien, og blyanten mot klossens ytterkant gir emnet veggens form. Ett punktmål gir en rett strek mot en vegg som ikke er rett. |

**Spikerslag i veggen** — legg dem mens veggen er åpen:

| Sone | Fra ferdig gulv | Fra høyderisset (1000) | Vegg | Del som ligger an her | Feste i veggen |
|---:|---|---|---|---|---|
| 1 | **0–1402** | **-1000..+402 krysser risset** | Hjørnene, mot endeveggene | Hjørnestolpe, bak (veggside) (2 stk.) | — (bare anlegg) |
| 2 | **229–297** | **-771..-703 under risset** | Bakveggen | Benkevange, bak (gjennomgående) | — (bare anlegg) |
| 3 | **614–682** | **-386..-318 under risset** | Bakveggen | Bordbærelekt, bak | J12-V, 3 stk. |
| 4 | **1402–1500** | **+402..+500 over risset** | Bakveggen | Sidevange, øvre | J14, 6 stk. |

To notasjoner, samme sone. **Målt fra ferdig gulv** er modellens egen Z. **Målt fra høyderisset** er den samme høyden minus 1000 — minus er *under* laserlinja, pluss er *over* den. Gulvet er skjevt og risset er ikke: står du ved den åpne veggen med målebåndet på laserlinja, er det den andre kolonnen du setter sonene etter.

**Spikerslaget skal ligge i alle 4 sonene, også der det ikke kommer en skrue.** Kolonnen *Del som ligger an her* sier hva sengen presser mot veggen i den høyden — det er derfor sonen finnes. Kolonnen *Feste i veggen* sier hva som faktisk skrus fast der, og «— (bare anlegg)» betyr at sengen bare hviler mot veggen i den sonen. En gipsplate uten tre bak gir etter under anlegg også.

Gulv-kolonnen er fra **ferdig gulv**. Legges gulvet etterpå, må påforingshøyden legges til — i begge kolonner, for risset slås fra ferdig gulv det også.

⚠️ Høyderisset skal gå hele veien rundt nisja og møte seg selv. Gjør det ikke det, står laseren feil.

---

# Før du begynner

**Svart strek** er delen du setter opp nå. **Grå strek** er det som allerede står.

**Festemidlene er tegnet, ikke antydet.** Hver skrue, bolt og hvert beslag på stegsidene er den samme kroppen som står i modellen, i sin egen lengde og langs sin egen akse — så en skrue som peker feil vei eller er for lang stopper byggingen av manualen, ikke først byggingen av sengen.

**Trukket ut av hullet:** på de fleste stegene er festemidlene tegnet et stykke ut langs sin egen akse, med en **prikket linje** ned i hullet de skal i og en **prikk** der hullet er. Den prikkede linjen betyr festemiddel og ingenting annet; **piler** brukes bare om tredeler som skal føres sammen. På de stegene som setter tjue-tretti like skruer — spilene — er de tegnet **der de havner** i stedet: hodet fylt, og den delen som ligger begravd i treet **stiplet**.

**Bokstaven i ringen** (Ⓐ, Ⓑ …) sier hvilken av stegets typer et festemiddel er, og går igjen i tabellen under bildet. Den sitter alltid **på** skruen den gjelder, eller har en tynn strek bort til den — den peker aldri i løse lufta. Der to skruer på samme side er nesten like lange, skilles de i tillegg med **fyll** i silhuetten — den samme bokstaven én gang til, så du ser hvilken av dem det er uten å lese: åpen, skravert, krysskravert, heldekt. Ellers står skruene i ren kontur, for da skiller lengden dem selv. Hele koden står på [beslagsiden](#beslag).

**Antallet står ikke i bildet.** Festemidlene er tegnet ett for ett, der de går — bare to som havner nøyaktig oppå hverandre på papiret er tegnet én gang. Hvor mange det er i alt står i tabellen under bildet, og bare der. Hvilken vei hver enkelt drives, og hva som forbores, står i [beslaglista](generated/beslagliste.md) og [skrueretningene](generated/skrueretninger.md).

**Tving før du skrur — hele veien.** En treskrue drar skjøten ut av flukt på vei inn: den siste halve omdreiningen flytter delen noen tiendeler før den klemmer. Klem derfor delene sammen i den stillingen de skal ha, og skru så. Minst **to tvinger** i huset, fire er bedre — to av dem er dessuten bundet opp i steg 0, der vinkelklossen skal holdes mot flaten mens lomma bores. Og på steg 3 og 5 står det en kropp igjen som ikke holder seg selv i flukt før neste steg kommer: de stegene har hvert sitt **avstivingspunkt** nederst i «Slik gjør du», og der sier tvingen eller den midlertidige lekta hva som skal holdes mot hva.

| Slik | Ikke slik | |
|:---:|:---:|---|
| to-personer ja | en-person-nei nei | **Én person — men to ved reisningen, steg 2 og 4.** Bakrammen tippes opp om underkanten, og den fremre sidevangen løftes opp på endebjelkene. Begge deler krever fire hender. Resten av sengen er skrevet for én mann med tvinger og lister. |
| underlag ja | dra-nei nei | **Mykt underlag.** Bygg rammene flatt på papp eller teppe. Ikke dra delene over gulvet. |
| sorter ja |  | **Sorter delene** etter kapplista, og merk hver del på en flate som blir skjult. |
| blyant-foerst ja | skrutrekker-foerst-nei nei | **Blyanten først.** Merk av hvert kapp og hvert hull før du skrur — all saging og all boring skjer før delen reises: verksteddelene i steg 0, romdelene så snart de er finkappet i rommet. |
| verktoy ja |  | **Verktøy:** drill med bor, torxbits, tommestokk, vater, vinkelhake og tvinger — minst to, fire er bedre. |
| forbor ja |  | **Forbor.** I bordene og i all endeved er forboring et krav. |
| veggfeste-ja ja | fritt-staaende-nei nei | **Sengen skal skrus fast i veggen.** Den er ikke beregnet på å stå fritt — veggen er sperren på baksiden. |

---

# Beslag

5 = tykkelse i mm, 60 = lengde i mm, 100x = antall

Fyllkoden: A åpen, B skravert, C krysskravert, D heldekt

**Fyllkode.** Der to skruer på samme side er nesten like lange, skilles de med fyll — ellers står festemidlene i ren kontur.

| | |
|:---:|---|
| Treskrue 5×60 forsenket Torx **92x** | Treskrue 5×60 forsenket Torx |
| Treskrue 5×40 forsenket Torx **48x** | Treskrue 5×40 forsenket Torx |
| Treskrue 6×80 forsenket Torx **38x** | Treskrue 6×80 forsenket Torx |
| Treskrue 6×120 forsenket Torx **16x** | Treskrue 6×120 forsenket Torx |
| Veggfeste etter veggtype (treskrue 8×100 i stender, eller plugg + skrue i mur) **9x** | Veggfeste etter veggtype (treskrue 8×100 i stender, eller plugg + skrue i mur) |
| Filtknott / møbeltapp ⌀40 **8x** | Filtknott / møbeltapp ⌀40 |

Hvor hver enkelt går, og hva som forbores: [beslagliste](generated/beslagliste.md). Hvilken vei hver enkelt drives, og hvorfor: [skrueretninger](generated/skrueretninger.md).

---

# Delene

| Del | Dim. | Lengde | Ant. | Kapp |
|---|---|---:|---:|---|
| Løs plate | 18 mm plate, 574 bred | 798 | **1** | nå |
| Benkespile | 23×98 | 800 | **10** | nå |
| Køyespile | 23×98 | 800 | **14** | nå |
| Endespile | 23×98 | 764 | **2** | på stedet |
| Rekkverksavstiver | 23×98 | 180 | **8** | nå |
| Stigevange | 36×48 | 1871 | **2** | på stedet |
| Benkespileledd | 36×48 | 547 | **2** | nå |
| Endelist | 36×48 | 98 | **2** | på stedet |
| Endelist, fremre | 36×48 | 98 | **2** | på stedet |
| Stigekloss | 36×48 | 36 | **8** | nå |
| Hjørnestolpe, front | 36×98 | 2037 | **2** | på stedet |
| Hjørnestolpe, bak (veggside) | 36×98 | 1402 | **2** | på stedet |
| Endebjelke | 36×98 | 836 | **2** | nå |
| Rekkverksbord, front | 36×98 | 832 | **4** | på stedet |
| Fotbrettgavl | 36×98 | 272 | **2** | nå |
| Benkevange, bak (gjennomgående) | 48×68 | 1794 | **1** | nå |
| Bordbærelekt, bak | 48×68 | 1794 | **1** | nå |
| Avstivningslekt under plate | 48×68 | 750 | **2** | nå |
| Benkevange, front (bit) | 48×68 | 547 | **2** | nå |
| Fotbrettbord | 48×68 | 416 | **4** | nå |
| Rungetrinn | 48×68 | 320 | **4** | nå |
| Stubbefot | 48×68 | 229 | **4** | på stedet |
| Kilelekt under platens forkant (skråkappet) | 48×68 | 77 | **2** | nå |
| Sidevange, øvre | 48×98 | 1984 | **2** | på stedet |

**85 deler.** **Ant.** er antallet — det samme tallet som står som `4×` på stegsidene. **Dim.** og **Lengde** er i millimeter.

**Kapp:** «nå» er delene verkstedet gjør ferdig. «på stedet» er de 22 delene som møter en endevegg eller gulvet — de kappes med overmål og finkappes i rommet. Overmålet står i [kapplista](generated/kappliste.md).

Posisjoner: [kappliste](generated/kappliste.md). Hva du skal kjøpe: [innkjøpsliste](generated/innkjopsliste.md).

---

# 0

## Kapping, forboring og forsenking

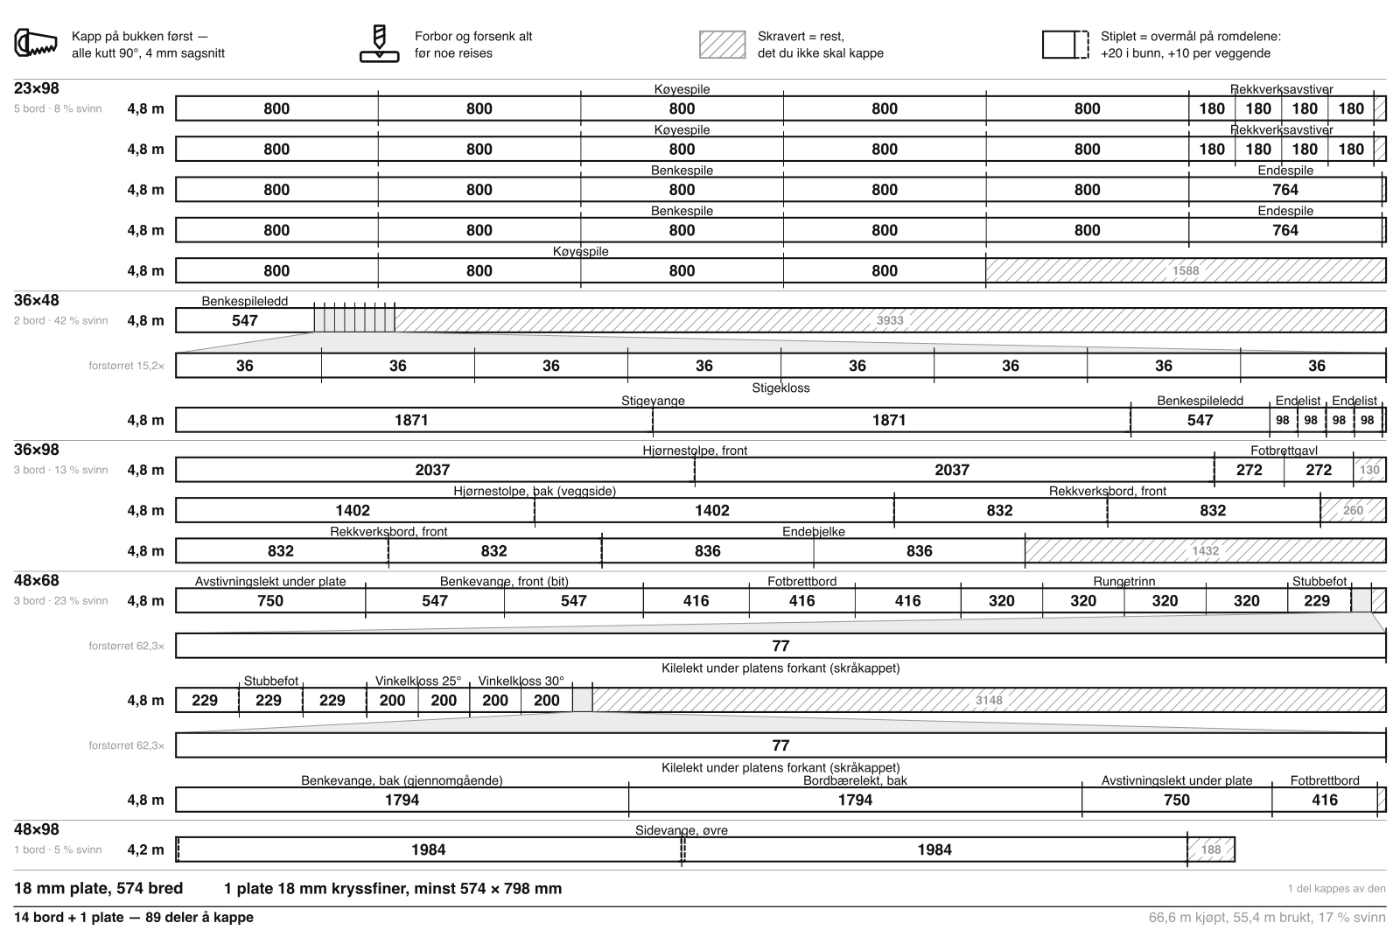
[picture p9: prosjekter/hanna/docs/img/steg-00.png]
Steg 0


| | |
|:---:|---|
| Filtknott / møbeltapp ⌀40 **8x** | Filtknott ⌀40 |

Ledd **J15** → [beslagliste](generated/beslagliste.md)

⚠️ Romdelene skal IKKE kappes ferdig nå, og hullene i dem skal ikke bores nå. Kapplista sier hvilke — de kappes med overmål, finkappes i rommet, og bores der.

[Steg 0 i ord](generated/byggesteg.md#steg-0--kapping-forboring-og-forsenking)

---

# 1

## Bakrammen — bygg den flatt på gulvet i nisja

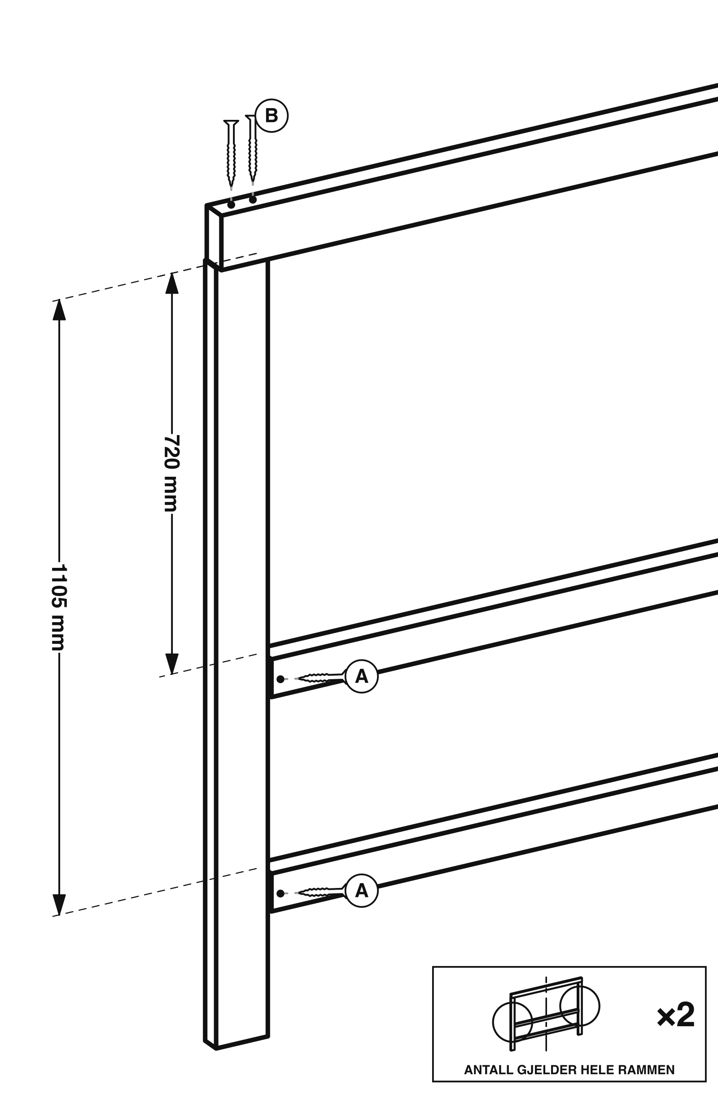
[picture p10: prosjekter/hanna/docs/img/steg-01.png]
Steg 1


| Ant. | Del | Dim. | Lengde |
|---:|---|---|---:|
| **1×** | Benkevange, bak (gjennomgående) | 48×68 | 1794 |
| **1×** | Bordbærelekt, bak | 48×68 | 1794 |
| **2×** | Hjørnestolpe, bak (veggside) | 36×98 | 1402 |
| **1×** | Sidevange, øvre | 48×98 | 1984 |

| | | |
|:---:|:---:|---|
| A | Treskrue 6×80 forsenket Torx **8x** | Treskrue 6×80 |
| B | Treskrue 6×120 forsenket Torx **4x** | Treskrue 6×120 |

Bokstavene viser hvor på tegningen hver type går.

Ledd **J2-B**, **J8-B**, **J12** → [beslagliste](generated/beslagliste.md)

⚠️ Mål diagonalene i rammen — de skal være like.

[Steg 1 i ord](generated/byggesteg.md#steg-1--bakrammen--bygg-den-flatt-på-gulvet-i-nisja)

---

# 2

## Tipp bakrammen opp og skru den fast i veggen

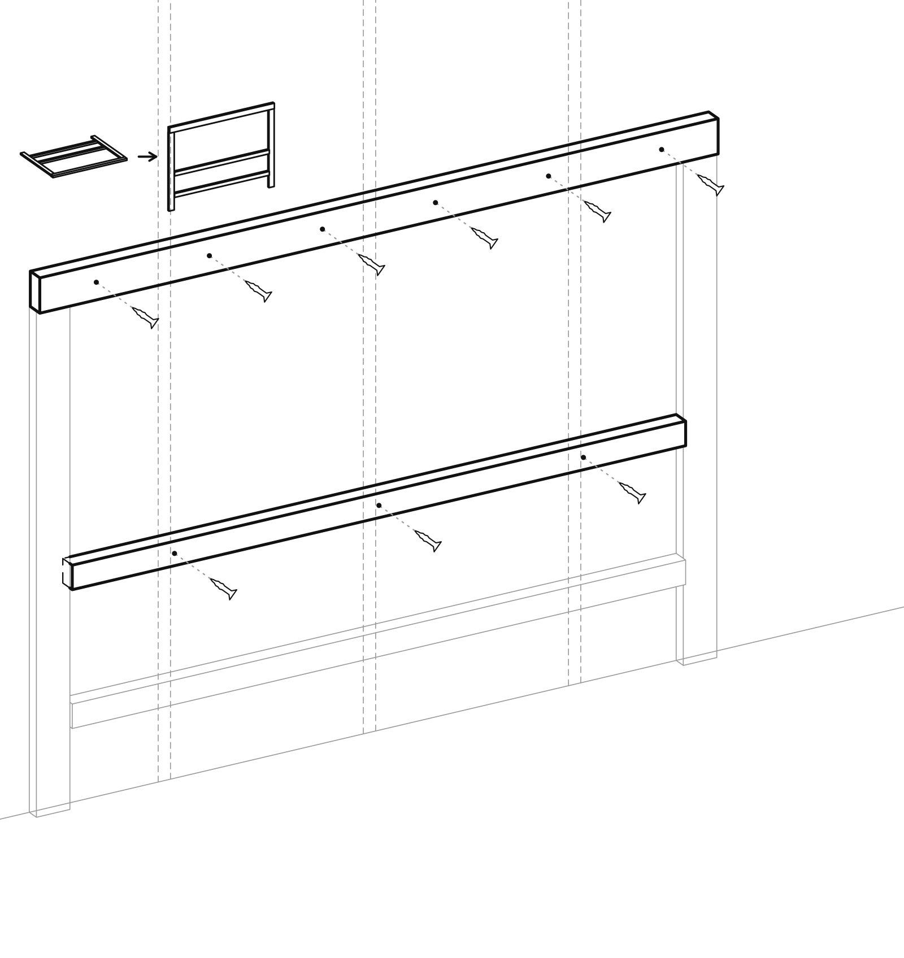
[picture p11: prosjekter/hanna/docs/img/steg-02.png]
Steg 2


| | |
|:---:|---|
| Veggfeste etter veggtype (treskrue 8×100 i stender, eller plugg + skrue i mur) **9x** | Veggfeste |

Ledd **J12-V**, **J14** → [beslagliste](generated/beslagliste.md)

⚠️ Vater langs sidevangen, og lodd på begge stolper.

[Steg 2 i ord](generated/byggesteg.md#steg-2--tipp-bakrammen-opp-og-skru-den-fast-i-veggen)

---

# 3

## Endebjelkene og de fremre stolpene

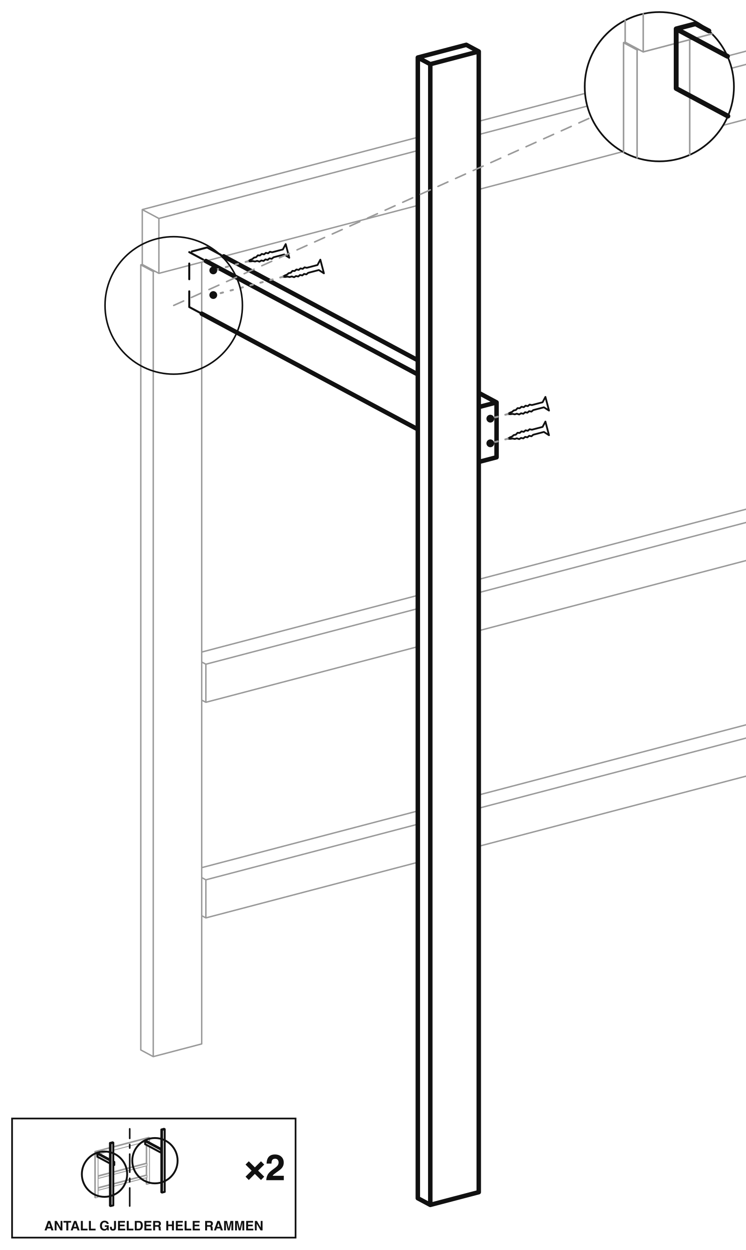
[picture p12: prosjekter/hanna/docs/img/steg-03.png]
Steg 3


| Ant. | Del | Dim. | Lengde |
|---:|---|---|---:|
| **2×** | Endebjelke | 36×98 | 836 |
| **2×** | Hjørnestolpe, front | 36×98 | 2037 |

| | |
|:---:|---|
| Treskrue 6×80 forsenket Torx **8x** | Treskrue 6×80 |

Ledd **J1** → [beslagliste](generated/beslagliste.md)

⚠️ Vater på begge endebjelker, og kontroller at de ligger i nøyaktig samme høyde.

🗜️ **Avstiving.** Endebjelke og hjørnestolpe, front henger i ett feste og kan dreie langs veggen, inn mot endeveggen og ut igjen — sett en midlertidig lekt fra det frie hjørnet bort til hjørnestolpe, bak (veggside), og bruk tvinger mens du skrur.

[Steg 3 i ord](generated/byggesteg.md#steg-3--endebjelkene-og-de-fremre-stolpene)

---

# 4

## Fremre sidevange

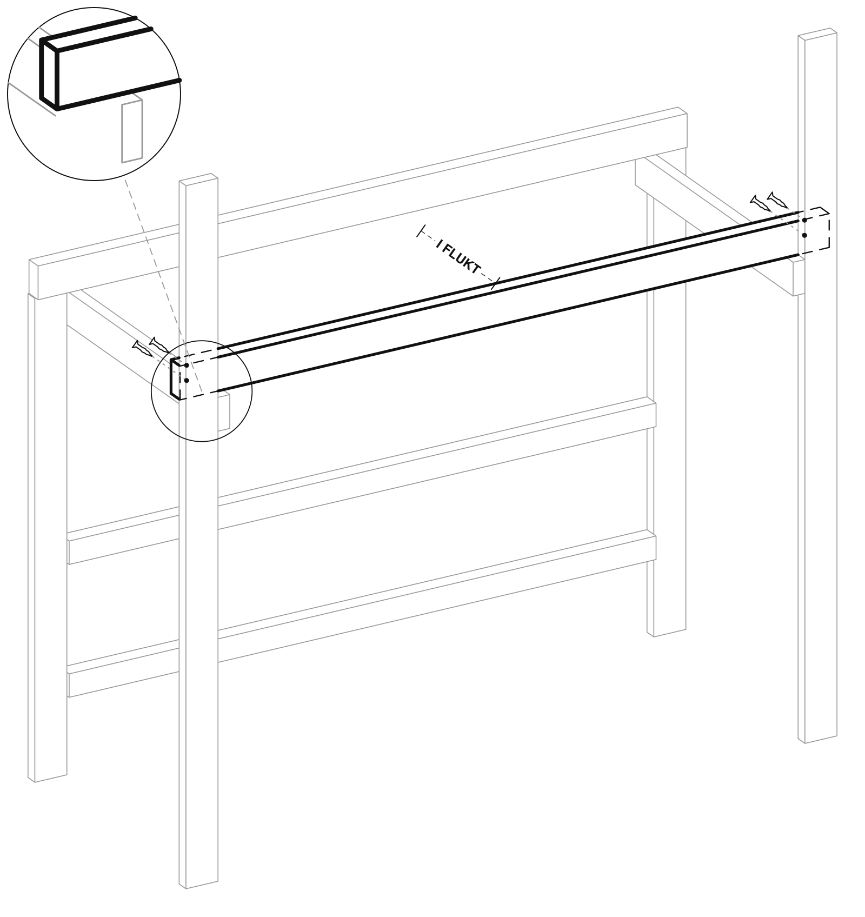
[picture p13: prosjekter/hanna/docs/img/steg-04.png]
Steg 4


| Ant. | Del | Dim. | Lengde |
|---:|---|---|---:|
| **1×** | Sidevange, øvre | 48×98 | 1984 |

| | |
|:---:|---|
| Treskrue 6×80 forsenket Torx **4x** | Treskrue 6×80 |

Ledd **J2** → [beslagliste](generated/beslagliste.md)

⚠️ Mål avstanden mellom de to sidevangene i begge ender og på midten. Den skal være lik overalt — det er madrassbredden, og madrassen er kappet nøyaktig etter den.

[Steg 4 i ord](generated/byggesteg.md#steg-4--fremre-sidevange)

---

# 5

## Fremre benkevanger, stubbeføtter og endelister

Steg 5

| Ant. | Del | Dim. | Lengde |
|---:|---|---|---:|
| **2×** | Benkespileledd | 36×48 | 547 |
| **2×** | Benkevange, front (bit) | 48×68 | 547 |
| **2×** | Endelist | 36×48 | 98 |
| **2×** | Endelist, fremre | 36×48 | 98 |
| **4×** | Stubbefot | 48×68 | 229 |

| | | |
|:---:|:---:|---|
| A | Treskrue 5×60 forsenket Torx **20x** | Treskrue 5×60 |
| B | Treskrue 6×120 forsenket Torx **4x** | Treskrue 6×120 |
| C | Treskrue 6×80 forsenket Torx **4x** | Treskrue 6×80 |

Bokstavene viser hvor på tegningen hver type går.

Ledd **J8**, **J10**, **J19**, **J20**, **J17** → [beslagliste](generated/beslagliste.md)

⚠️ Ingenting skal krysse gulvet mellom de to benkene.

🗜️ **Avstiving.** Benkespileledd, benkevange, front (bit) og stubbefot henger i ett feste og kan dreie inn mot bakveggen og ut i rommet — monter én benkespile med det samme, og bruk tvinger mens du skrur.

🗜️ **Avstiving.** Stubbefot henger i ett feste og kan dreie inn mot bakveggen og ut i rommet — sett en midlertidig lekt fra det frie hjørnet bort til benkevange, bak (gjennomgående), og bruk tvinger mens du skrur.

[Steg 5 i ord](generated/byggesteg.md#steg-5--fremre-benkevanger-stubbeføtter-og-endelister)

---

# 6

## Stigen

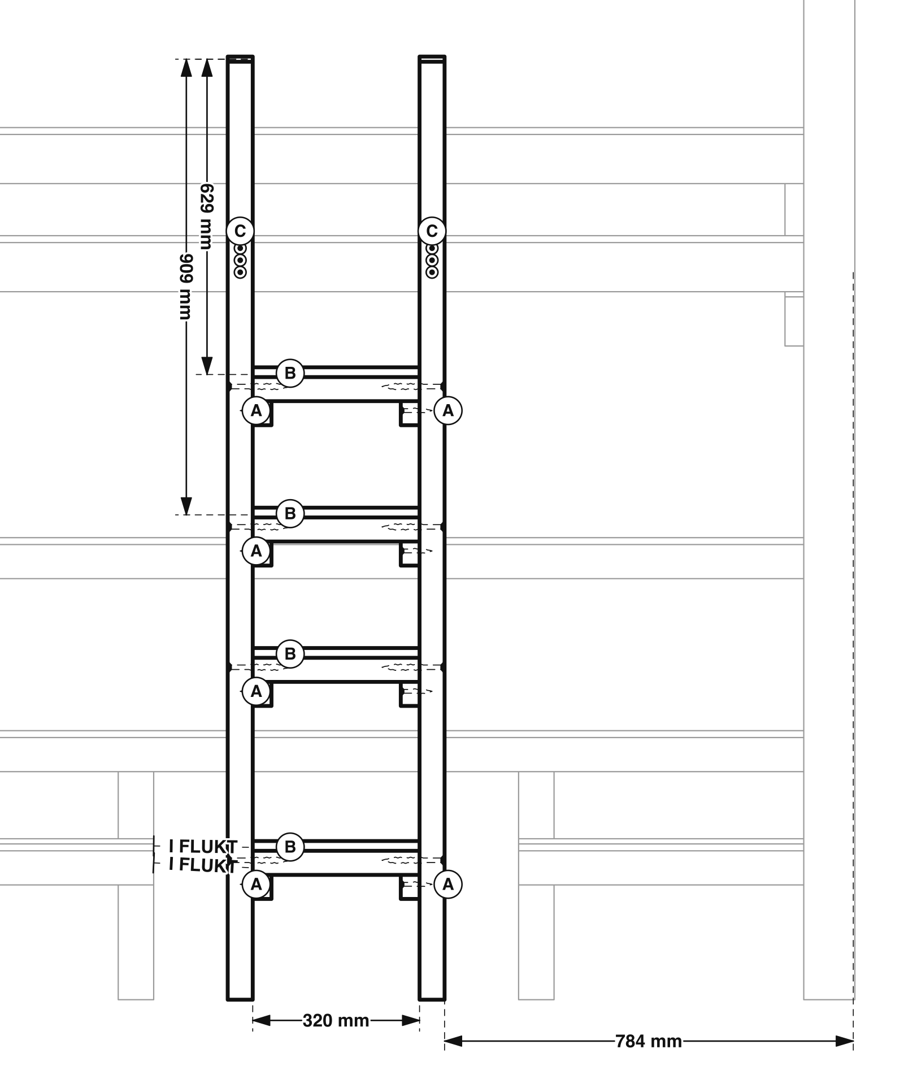
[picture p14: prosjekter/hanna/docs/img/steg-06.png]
Steg 6


| Ant. | Del | Dim. | Lengde |
|---:|---|---|---:|
| **4×** | Rungetrinn | 48×68 | 320 |
| **8×** | Stigekloss | 36×48 | 36 |
| **2×** | Stigevange | 36×48 | 1871 |

| | | |
|:---:|:---:|---|
| A | Treskrue 5×60 forsenket Torx **8x** | Treskrue 5×60 |
| B | Treskrue 6×120 forsenket Torx **8x** | Treskrue 6×120 |
| C | Treskrue 6×80 forsenket Torx **6x** | Treskrue 6×80 |

Bokstavene viser hvor på tegningen hver type går.

Ledd **J3**, **J4**, **J5** → [beslagliste](generated/beslagliste.md)

⚠️ Mål lysåpningen mellom stigevangene øverst og nederst — den skal være lik.

[Steg 6 i ord](generated/byggesteg.md#steg-6--stigen)

---

# 7

## Benkespiler og endespiler

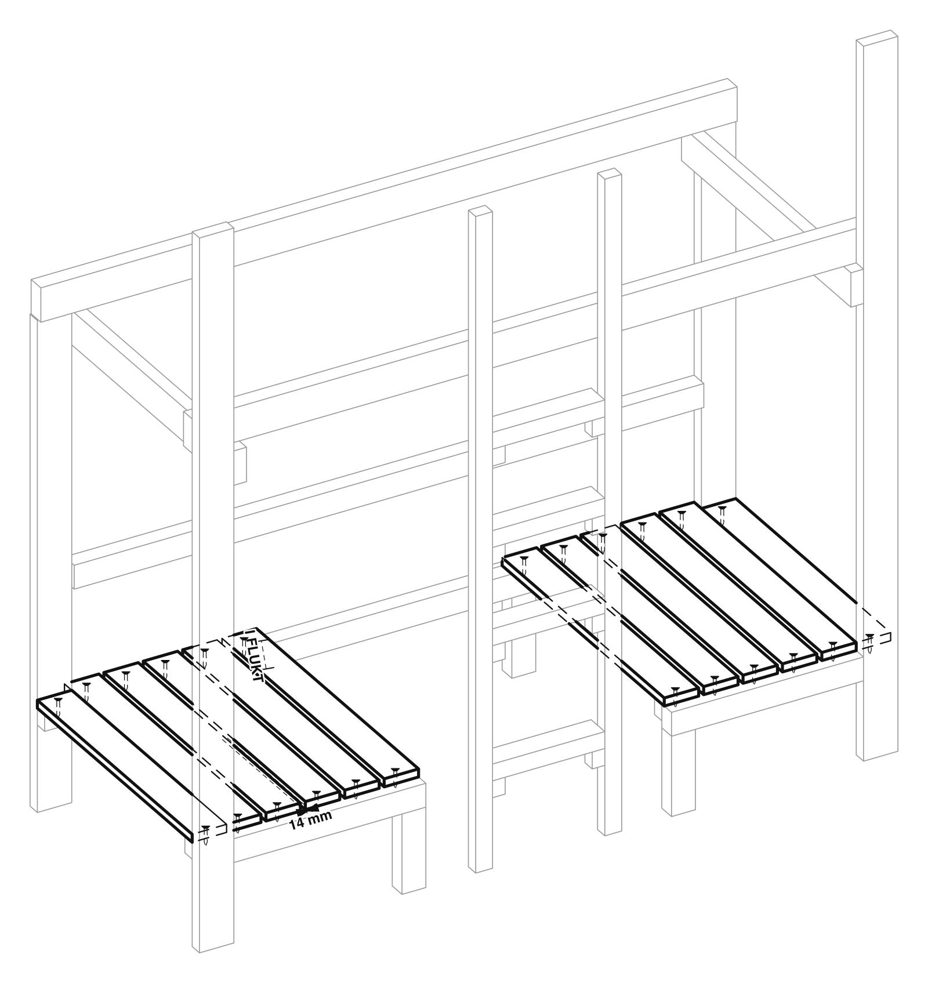
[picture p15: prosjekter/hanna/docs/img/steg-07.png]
Steg 7


| Ant. | Del | Dim. | Lengde |
|---:|---|---|---:|
| **10×** | Benkespile | 23×98 | 800 |
| **2×** | Endespile | 23×98 | 764 |

| | |
|:---:|---|
| Treskrue 5×60 forsenket Torx **24x** | Treskrue 5×60 |

Ledd **J11**, **J11-F**, **J11-E**, **J16** → [beslagliste](generated/beslagliste.md)

⚠️ Kjenn over hele benken med håndflaten: ingen skruehoder skal stikke opp.

[Steg 7 i ord](generated/byggesteg.md#steg-7--benkespiler-og-endespiler)

---

# 8

## Køyespiler

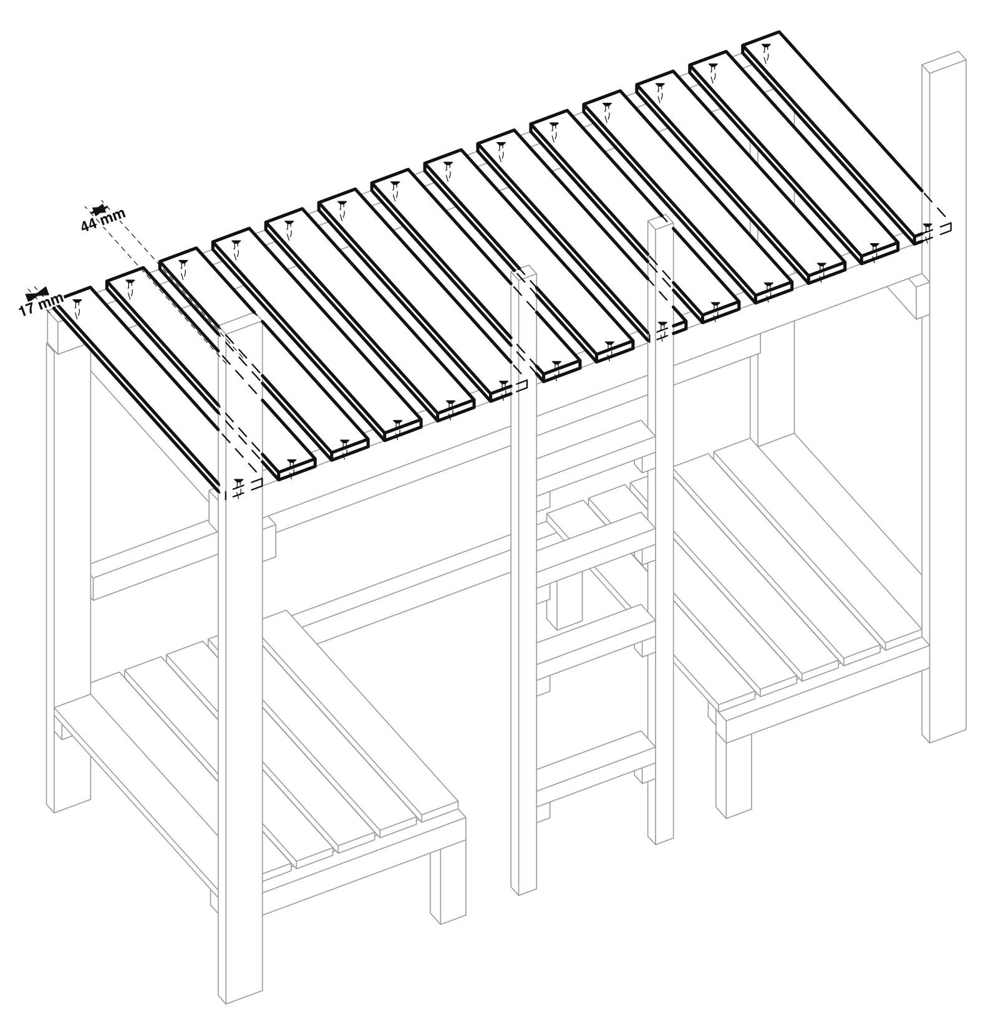
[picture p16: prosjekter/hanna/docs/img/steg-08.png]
Steg 8


| Ant. | Del | Dim. | Lengde |
|---:|---|---|---:|
| **14×** | Køyespile | 23×98 | 800 |

| | |
|:---:|---|
| Treskrue 5×60 forsenket Torx **28x** | Treskrue 5×60 |

Ledd **J6** → [beslagliste](generated/beslagliste.md)

⚠️ Alle spiler skal dekke hele bredden av begge vanger. Ligger en spile bare halvveis på vangen, flytt den.

[Steg 8 i ord](generated/byggesteg.md#steg-8--køyespiler)

---

# 9

## Rekkverk foran

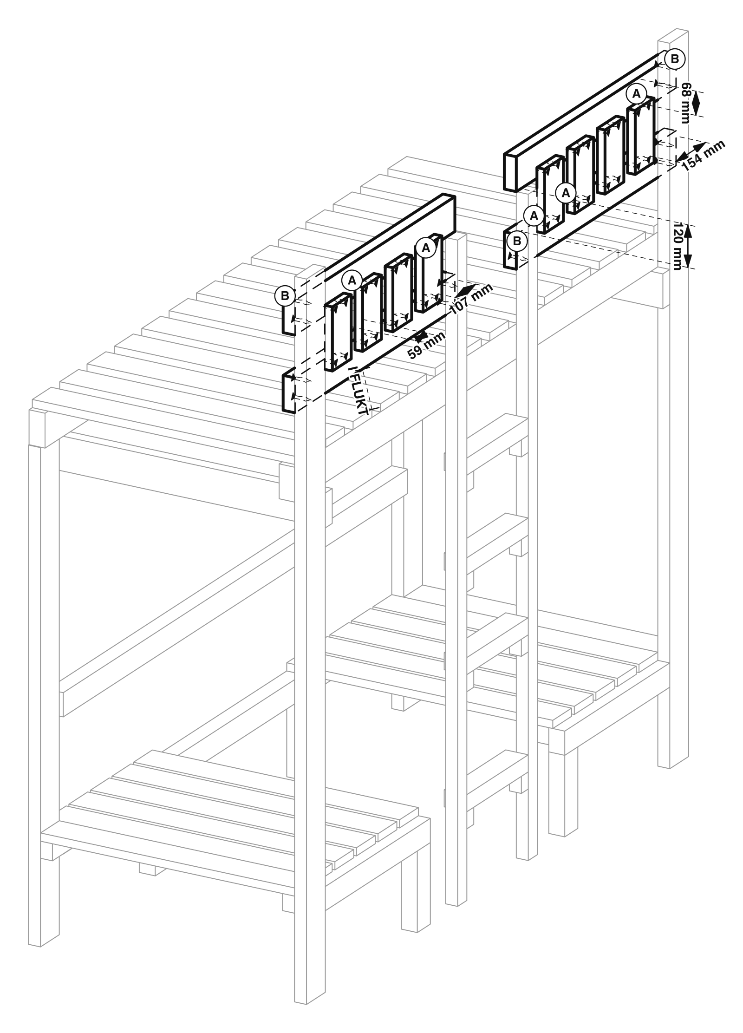
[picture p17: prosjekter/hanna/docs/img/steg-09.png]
Steg 9


| Ant. | Del | Dim. | Lengde |
|---:|---|---|---:|
| **8×** | Rekkverksavstiver | 23×98 | 180 |
| **4×** | Rekkverksbord, front | 36×98 | 832 |

| | | |
|:---:|:---:|---|
| A | Treskrue 5×40 forsenket Torx **32x** | Treskrue 5×40 |
| B | Treskrue 5×60 forsenket Torx **12x** | Treskrue 5×60 |

Bokstavene viser hvor på tegningen hver type går.

Ledd **J7**, **J21** → [beslagliste](generated/beslagliste.md)

⚠️ Mål åpningene over madrassoverflaten mot tallene i nøkkelmålene. De er sikkerhetskravet i denne sengen.

[Steg 9 i ord](generated/byggesteg.md#steg-9--rekkverk-foran)

---

# 10

## Løs plate med fire lekter — og ingen beslag

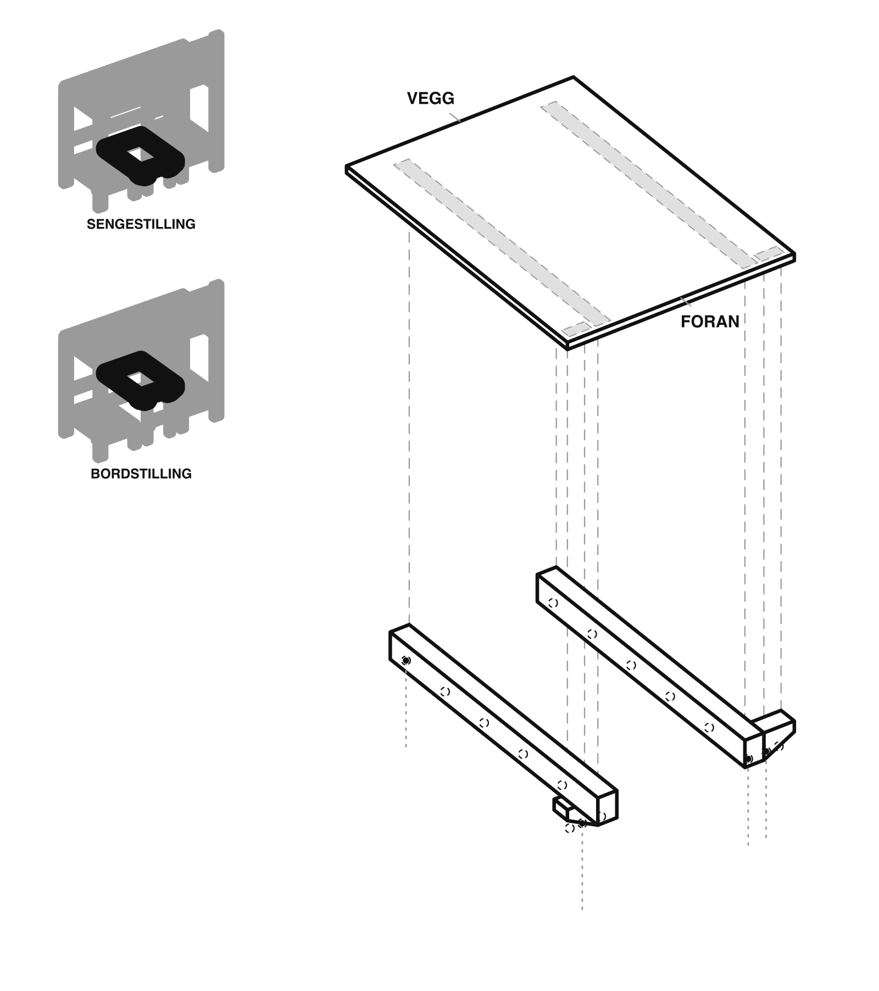
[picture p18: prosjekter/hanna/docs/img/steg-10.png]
Steg 10


| Ant. | Del | Dim. | Lengde |
|---:|---|---|---:|
| **2×** | Avstivningslekt under plate | 48×68 | 750 |
| **2×** | Kilelekt under platens forkant (skråkappet) | 48×68 | 77 |
| **1×** | Løs plate | 18 mm plate, 574 bred | 798 |

| | |
|:---:|---|
| Treskrue 5×40 forsenket Torx **16x** | Treskrue 5×40 |

Ledd **J13a**, **J13b** → [beslagliste](generated/beslagliste.md)

⚠️ Skyv platen sidelengs. Den skal bevege seg et par millimeter og så stoppe mot trinnenden — begge veier, i begge stillinger.

[Steg 10 i ord](generated/byggesteg.md#steg-10--løs-plate-med-fire-lekter--og-ingen-beslag)

---

# 11

## Madrass og puter

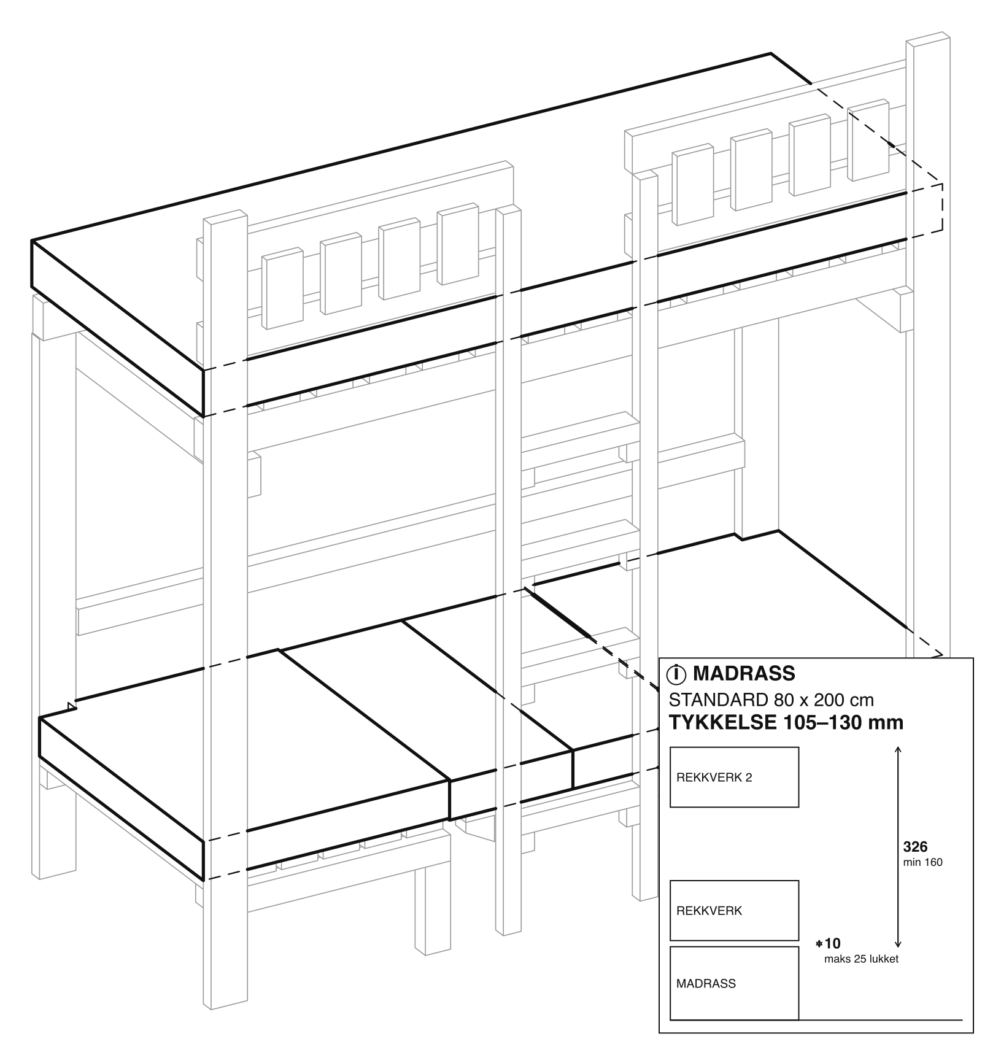
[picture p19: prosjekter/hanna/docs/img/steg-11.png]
Steg 11


| Ant. | Del | Dim. | Lengde |
|---:|---|---|---:|
| **2×** | Benkepute, skum **100 mm** (663 × 800 mm, hakk 98 × 36 i veggkanten) |  |  |
| **1×** | Madrass 80 × 200 cm, **120 mm tykk** (vindu 105–130 mm) |  |  |
| **2×** | Ryggpute, skum **100 mm** (332 × 800 mm) |  |  |

⚠️ Ettertrekk alle festemidler som kan ettertrekkes.

[Steg 11 i ord](generated/byggesteg.md#steg-11--madrass-og-puter)

---

# 12

## Fotbrettet

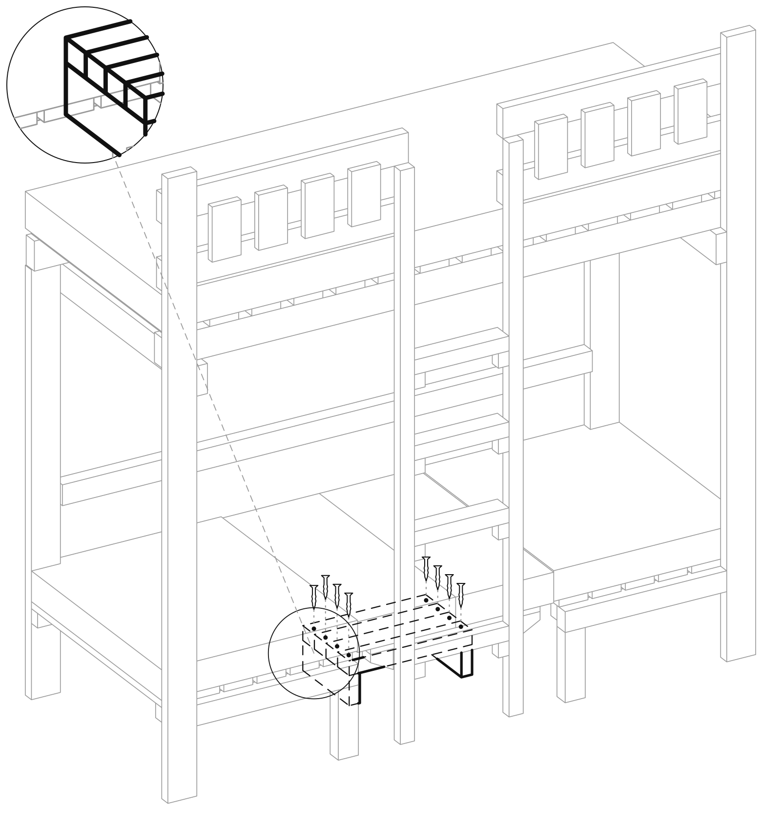
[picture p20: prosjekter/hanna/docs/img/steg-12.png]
Steg 12


| Ant. | Del | Dim. | Lengde |
|---:|---|---|---:|
| **4×** | Fotbrettbord | 48×68 | 416 |
| **2×** | Fotbrettgavl | 36×98 | 272 |

| | |
|:---:|---|
| Treskrue 6×80 forsenket Torx **8x** | Treskrue 6×80 |

Ledd **J18** → [beslagliste](generated/beslagliste.md)

⚠️ Mål dekkets overkant: 146 mm over gulvet.

[Steg 12 i ord](generated/byggesteg.md#steg-12--fotbrettet)

---

Tegningene i `docs/img/` er projisert ut av modellen og sjekket inn i git. De lages på nytt med `mise run montering`.

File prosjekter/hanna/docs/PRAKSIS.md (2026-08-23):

# PRAKSIS — hvordan HANNA er bygd

Dette er ikke en del av manualen. De to heftene — `docs/hanna.pdf` og
`docs/hanna-referanse.pdf` — settes sammen av en eksplisitt liste i
`tools/build_pdf.py` (`TARGETS`), og denne filen står ikke i noen av dem. Den er skrevet for den som skal endre modellen eller tegningene, og den
sier hvilke regler som gjelder og hvorfor de er som de er.

De **felles** reglene i snekkerbua — én kilde, assertfilosofien, regler framfor
tilfeller, de allmenne tegnekonvensjonene, filmene og determinismen — står i
[PRAKSIS.md](../../../PRAKSIS.md) på rota. Her står bare det som er HANNAs
eget: delene, leddene, invariantene denne modellen hviler på, og billedspråket
i denne manualen.

---

## 1. Kjeden

Fellesregelen står i [PRAKSIS §1](../../../PRAKSIS.md#1-én-kilde-og-bare-én).
Kilden her er `generate_loftbed.py`, og dette er veien ut av den:

    generate_loftbed.py          modellen: mål, deler, festemidler, asserter
      ├─ tools/gen_doc_tables.py leser modellen → docs/generated/*.md,
      │                          docs/MONTERING.md, byggesteg.json
      ├─ tools/render_lineart.py leser modellen → docs/img/steg-NN.svg/.png
      │    ├─ tools/render_cutpage.py   steg 0 (kappeplanen)
      │    ├─ tools/render_panel.py     steg 10 (den løse platen)
      │    ├─ tools/render_maalfigur.py forsteget (målefiguren av nisja)
      │    └─ tools/render_maaltegning.py side 2 (senga i mål)
      ├─ tools/render_setedetalj.py  → docs/schematics/setedetalj.svg
      ├─ tools/render_endelevation.py → docs/schematics/end-elevation.svg
      ├─ tools/render_spikerslag.py  → docs/schematics/spikerslag.svg
      ├─ tools/render_boresjablong.py → docs/schematics/boresjablong-*.svg
      ├─ tools/gen_figurhode.py  landemerkene → figurikonenes hoder og §4
      ├─ tools/gen_glyphs.py     ikoner og piktogrammer
      └─ tools/build_pdf.py      setter sammen docs/hanna.pdf (byggeheftet)
                                 og docs/hanna-referanse.pdf av det ferdige

`docs/ASSEMBLY.md` er den ene håndskrevne teksten. Den har lov til å navngi
deler og sitere J-numre, men den skal aldri gjenta et mål som et generert
fragment allerede bærer — den lenker til fragmentet i stedet.

**Hva som gikk galt før.** Leddtabellen fantes to steder: handelsnavn, antall
og forboring i `gen_doc_tables.py`, retning og medlemspar i
`render_lineart.py`. Ingenting bandt dem sammen bortsett fra en setning i hver.
Nå ligger hele `JOINTS` i modellen med maskinfelter, og begge verktøyene leser
den. Det er felles-PRAKSIS §1, funnet på den harde måten: **hvis to filer må
være enige om et tall, er tallet på feil sted.**

---

## 2. De fem assertfamiliene

Hva som gjør en assert verdt å skrive står i
[PRAKSIS §2](../../../PRAKSIS.md#2-assertfilosofien). Modellen har over hundre
av dem, og de faller i fem familier som følger av hva sengen er laget av: tre,
stål, en flate å skru i — og en rekkefølge de settes sammen i.

Inndataene er standardene. EC5 gir 3d kantavstand og 4d avstand mellom skruer;
EN 747 gir 75 mm åpning og 160 mm rekkverk over madrassen. Alt som følger av
dem er utregnet.

**Skruelengderegelen.** En gjennomgående treskrue må gå klar gjennom delen den
drives fra og ende inne i den andre:

    tykkelse(fra) < lengde < tykkelse(fra) + tykkelse(inn i)

For de fleste leddene i denne sengen er bare én av de to retningene mulig, og
da er retningen ikke en mening — den er utledet, og tabellen får bare være enig.
Der begge retninger holder målene, bestemmer tabellen, og
`docs/generated/skrueretninger.md` sier hvilke som er hvilke. Der ingen av dem
holder, er det ikke en rett gjennomskrue i det hele tatt, og `drive(...)` må si
det med `exempt=` og en grunn på norsk.

**Passer-på-flaten.** En rad med `n` skruer må ha
`(n-1) × 4d + 2 × 3d` millimeter av kontaktflaten å stå på. Dette er den mest
produktive asserten i filen, fordi antallet skruer i et ledd er akkurat den
typen tall som blir skrevet ned én gang og aldri kontrollert mot treet. Da den
ble slått på, strøk den fire tall som hadde stått uimotsagt: bæreklossene
(36 × 36 mm flate tar én 6 mm skrue, ikke to), stigeklossen, stigevangens
omlegg og beslagflikene. Bæreklossene er siden tatt helt ut av sengen — se
`ASSEMBLY.md` avsnitt 2 — men det var denne asserten som først målte flaten
deres, og det var det ene tallet, 1 skrue og ikke 2, som til slutt gjorde det
tydelig at klossen halverte stålet i stedet for å ta det bort.

Når et antall må ned, er svaret **ikke** å myke opp regelen. Svaret er å
skrive ned den reelle lastveien og regne på den — se den kombinerte
skjærveien i `ASSEMBLY.md` avsnitt 2.

**Kompletthet.** Ingen del får falle mellom to stoler:

* hver eneste tredel må stå i nøyaktig ett byggesteg (`resolve_steps`)
* hvert ledd må finnes så mange ganger i modellen som leddtabellen sier
* handlelista må være summen av de festemidlene som faktisk er plassert
* hver stegside må tegne minst ett feste av hver deletype den lister opp, og
  antallene på tegningen må stemme med antallene i tabellen (`check_coverage`)

Den siste er verdt å merke seg: den fanger ikke feil geometri, den fanger
**tause tegninger** — en kloss som står i deletabellen og aldri blir vist
festet noe sted.

**Orientering.** Et beslag som er skrudd fast i tre er ikke nødvendigvis
riktig vei. Vinkelbeslaget under bordbærelekta kan snus opp ned og fortsatt
treffe tre med begge flikene — det treffer bare oversiden av lekta i stedet for
undersiden, og lekta henger plutselig i to skruer i uttrekk i stedet for å stå
på stål. Derfor to asserter, ikke én:

* hver flik må ha tre bak seg i sin egen skrueretning, og
* et beslag som **bærer** noe (`bears=`) må ha den vannrette fliken skrudd rett
  opp, i undersiden av delen det bærer.

**Avstiving (X17).** De fire over spør om den ferdige sengen. Denne spør om
sengen *underveis*: hva holder kroppen et steg nettopp har laget, i det
byggmesteren slipper den? Kilden er byggherrens egen rapport etter at senga var
bygget (august 2026): «når bygget ikke har noen forankring ennå, trengs
midlertidige stivere for at nedre del av rammen skal holde seg i flukt».

Målt på den samme grafen X12 bygger — `step_units` sine kropper — og på
festene, ikke på et skjønn. Forankringsskyen er de festene *dette* steget
driver mellom kroppen og noe som allerede står (eller inn i veggen). Tre
fester som ikke ligger på én linje låser en stiv kropp; tre punkter à tre
translasjoner er ni bindinger mot seks frihetsgrader. Ligger de på **én**
linje, står det igjen én frihet, og om den betyr noe er en **arm**, målt mot
festenes egen rekkevidde:

> **ustabil ⟺ festene ligger på én linje, og kroppens ytterste hjørne står
> lenger fra den linjen enn festene står fra hverandre.**

Derfor går en benkespile fri — den er skrudd i hver sin ende, og ingen del av
den stikker nevneverdig utenfor linjen mellom de to skruene — mens en fremre
stolpe med endebjelke ikke gjør det: to skruer 44 mm fra hverandre, og et
hjørne 829 mm ute.
Gulvet regnes ikke som feste; det er ikke i vater, og det er derfor føttene
kappes til slutt (samme grunn som at et plasseringsmål ikke måles fra gulvet,
§ X15).

Det steget så *får* er utledet, ikke skrevet: finnes det en senere del som
allerede kan skrus både til kroppen og til noe som står, sier punktet at den
delen monteres straks — byggherrens eget steg 5-grep, «ett toppbord
umiddelbart» — og ellers at det må en midlertidig lekt til, med hvilken
stående del den skal nå bort til og hvor langt det er. To asserter holder det
på plass: en bijeksjon mellom «steg med ustabil kropp» og «steg med
avstivingspunkt», lest av det ferdige blekket, og en fasit-assert som krever
at regelen fortsatt fyrer på de to kroppene rapporten navngir. Blir kriteriet
løsere, er det den siste som sier fra.

### Unntaket: delen som ikke er en boks

Modellen har hatt én invariant siden første linje: **hver tredel er en
akseparallell boks.** Det er den som gjør `.extents` til hele sannheten om en
del, og det er den «alt treverk er bokser» i §3 hviler på. V4 bryter den
nøyaktig én gang: de to fremre kilelektene under platen — vingene, M5 — er
skråkappet, 68 mm dype ved roten og 27 ved spissen.

Det er trygt, og grunnen er at **paringsflatene fortsatt er rektangler**. Vingen
møter platen over hele sin 77 × 48 mm toppflate, og den møter ingenting annet.
Flaten som ble kappet, er undersiden, og den berører ingen del i noen av de to
stillingene. `contacts()`, `patch_window()` og `bearing_area()` ser derfor
nøyaktig det de så før.

Delens `.extents` er med vilje fortsatt hele den omskrevne boksen. Da er hver
eneste klarings-, sveip- og overlappassert som leser `extents` fremdeles sann —
og den er nå **konservativ**, fordi den virkelige kroppen ligger strengt
innenfor den boksen assertene rydder plass til.

Det som **ikke** er konservativt, er alt som leser VOLUM eller tegner
SILHUETT. Begge deler leser soliden, ikke boksen, og skal fortsette å gjøre det.

Regelen videre: **en del som ikke er en boks er tillatt bare når paringsflatene
forblir rektangulære og den omskrevne boksen er den konservative konvolutten.**
Alt annet går tilbake til bokser.

### Referansekroppen: den fjerde kategorien

Sengen er laget av **tre** (kappes, står i lista, skrus), av **stål** (kjøpes,
står i lista, drives) og av **skum** (kjøpes, står ikke i kapplista, legges
på). Referansekroppen er den fjerde: **den er grunnen til at de tre andre
finnes.** Madrassen har vært en referansekropp siden begynnelsen; V14 legger
til fire barn — to som ligger i sengestilling, to som sitter i bordstilling.

Kategorien har madrassens regel, ord for ord:

* egen fargegruppe (`figures`), egen farge i STEP/GLB/USDZ;
* **ute** av kapplista, kontaktsjekken, sammenhengssjekken og
  overlappssjekken — den bærer ingenting og røres av ingenting;
* **inne** i `parts.tsv` (en diff på den er diffen på modellen) og i
  eksportene.

Ett tillegg som madrassen ikke trenger: kroppen er heller **ikke** i
`display_parts()`. Den lista er *sengen* — filmene, stegtegningene og
platesveipets kollisjonsprøve er bygd på den, og en kropp i en kollisjonsprøve
som handler om tre, ville felt en film som handler om tre. `scene_parts()` er
`display_parts` + kroppene, og det er dét som eksporteres.

**Boksinvarianten holder, og første halvdel er gratis her.** For kilen måtte
det argumenteres at paringsflatene fortsatt er rektangler; en kropp har
**ingen paringsflate i det hele tatt**. Den skjøtes ikke, så `contacts()`,
`patch_window()` og `bearing_area()` blir aldri spurt om den. Igjen står den
konservative halvdelen: `.extents` er den omskrevne boksen, og alt som leser
den, rydder mer plass enn kroppen tar. Tallene som **publiseres**, måles
likevel på soliden og aldri på boksen — den omskrevne boksen rundt et barn i
skredderstilling er en kube på 700 mm og sier ingenting sant om rommet over
hodet.

**Antropometrien er offentlig:** AnthroKids, de digitaliserte
Snyder-studiene fra 1975/1977
([math.nist.gov/~SRessler/anthrokids/](https://math.nist.gov/~SRessler/anthrokids/)).
Hvert segment er en brøkdel av ståhøyden H = 1200 mm (50-persentil ~6–8 år,
alderen EN 747 åpner overkøya i), og modellen leser de fem nøkkelmålene —
sittehøyde 0,545 H, knehasehøyde 0,28 H, knehøyde sittende 0,30 H,
skulderbredde 0,21 H, hodehøyde H/6 — **tilbake ut av den ferdige soliden** i
en assert. En figur som ikke lenger er 1200 mm høy, er ikke et måleinstrument.

**Klaringene er trykt, ikke assertert.** De harde assertene i denne modellen
handler om tre som må passe. Det ene som *er* assertert om kroppene, er at
ingen av dem ligger inne i noe tre eller stål; skummet er unntatt med vilje —
en pute på 100 mm tar rumpa 12 mm inn og hodet 22 mm ned i soveflaten, og en
figur som svevde oppå skummet i stedet, ville vært tegningen som lyver.

---

## 3. Festemidlene som geometri

### Grensen

Festemidlene er **modellert**, men de er ikke deler. Grensen går her:

| Er med | Er ikke med |
|---|---|
| `FASTENERS` (egen liste) | `parts` |
| `display_parts()` | `mode_parts()` |
| egen fargegruppe i `.usdz` | `CUT_LIST`, `parts.tsv` |
| tegningene | overlapp- og sammenhengssjekken |

Grunnen er enkel: en skrue **overlapper med vilje** de to delene den binder
sammen, så den ville strøket på overlappsjekken øyeblikkelig. Og en skrue er
ikke noe man kapper, så den har ingenting i kapplista å gjøre. `parts.tsv` er
byte-identisk med og uten festemidler, og det er en test i seg selv.

### Formen

En skrue er hode, forsenking, skaft og spiss. **Ingen gjenger i SOLIDEN.** En
modellert gjenge koster tusen trekanter for null lesbarhet i en 3D-visning.
Gjengen finnes bare i strektegningen, som en tegnet bølge langs konturen — se
«Én skrue, ett billedspråk» i §4 — og den er en tegnekonvensjon, ikke geometri.
Beslagene er bøyde plater bygd av bokser.

Et vinkelbeslags **andre** flik er ikke en ny rad med data. Den faller ut av
den første: en rett vinkel gjør `run` om til den andre flikens skrueretning og
drivvektoren om til retningen den fliken går. Det er derfor
orienteringsasserten i det hele tatt lar seg skrive.

### Nettene

En skrue er den eneste krumme kroppen i modellen, og på standard 0,001 mm
avvik trianguleres én skrue til flere trekanter enn hele sengen. Stålgruppen
eksporteres derfor på 0,15 mm.

**Rekkefølgen er ikke likegyldig.** OCC bufrer en triangulering på formen og
bytter den bare ut når det blir bedt om en *finere*. Gruppe-eksporten må derfor
kjøre **før** enkeltmesh-eksporten, ellers blir toleransen stilltiende ignorert.
Alt treverk er bokser — med det ene unntaket i §2, de to kilene, som ikke er
bokser, men som er like plane — og en plan flate trianguleres til de samme to
trekantene uansett avvik, så treet blir byte-identisk uansett.

---

## 4. Billedspråket i denne manualen

De allmenne konvensjonene — prikket linje mot pil, eksplodert langs
innsettingsaksen, stiplet for skjult, svart mot grått, ett steg per side, og
den ene pennen — står i
[PRAKSIS §4](../../../PRAKSIS.md#4-tegnekonvensjoner-som-holder-på-tvers).
Denne manualen har tatt dem i bruk bevisst. Pennen er `tools/layout.py`
(`RATIOS`), `Theme` deler den ut, og tallet er sengens egen bbox-diagonal delt
på 400, så alle tolv sidene følger den.

Ett tillegg til eksplosjonsregelen er HANNAs eget: **et beslag har ingen egen
akse og følger sine egne skruer ut**, med samme sprang som dem — «Kjeden i et
beslaghjørne» nedenfor.

### Skala

Én frihet er tatt utover pennen, og det er den samme enhver beslagtegning tar:
**diameteren er overdrevet**, med faktor `SCREW_FATTEN` — som står i
`tools/layout.py` sammen med pennen, fordi det er én knapp for hvor stort et
festemiddel tegnes. En 6 mm skrue på en to meter bred side er tynnere enn
streken sengen selv er tegnet med. **Lengden er sann**, med et gulv på
`FORESHORTEN_FLOOR` mot ren forkortning: en skrue drevet inn i papiret skal se
kort ut, men den skal fortsatt se ut som en skrue.

**Burde gulvet vært høyere for KORTE skruer?** Det er den nærliggende
innvendingen — en brøk behandler en 5×40 og en 6×120 likt, og det som gjør en
silhuett til en SKRUE er ikke lengden i millimeter, men hvor mye lengre den er
enn hodet er bredt. Hodet krymper ikke når lengden gjør det. Så sidene ble
målt, hver tegnet kropp mot sitt eget tegnede hode:

| Hoder lang | Hvem |
|---|---|
| 1,81–1,82 | 5×40, J10 (steg 5) og J12 (steg 1) — de korteste i boka |
| 2,22 | 5×60, J7 (steg 9) — den korteste GULVET selv lager |
| 2,3–5,1 | alt annet |

Svaret er nei, og målingen er hvorfor. De stubbete kroppene er ikke gulvet i
det hele tatt: en 5×40 projiseres i denne vinkelen til 35,6 av sine 40 mm, godt
klar av 28,8, så gulvet rører den aldri og et høyere gulv når den ikke. Og det
ville ikke nådd langt om det gjorde: et gulv får aldri tegne en skrue LENGRE
enn den er, så alt en kort skrue kan hente er de 12 % opp til sine sanne 40 mm
— 1,81 hoder blir 2,05, og det er ingen som ser. Det som avgjør hvor stubbet en
40 mm skrue ser ut, er hodet, altså `SCREW_FATTEN`, og det tallet ble avgjort
på sin egen prøve.

Innvendingen fortjener derfor ikke en knapp til, men en **snubletråd**:
`STUB_ASPECT` = 1,75, og `assert_no_stubs()` måler blekket. Ingen tegnet kropp
får komme ut kortere enn 1,75 av sitt eget hode. Verdien ligger like under det
sidene måler i dag, så den dagen et nytt kamera, en kortere skrue eller et
bredere hode lager en ekte pil av en av dem, stopper bygget og et menneske ser
på den — i stedet for at manualen stille skaffer seg en pilspiss der det skulle
stått et festemiddel.

### Én skrue, ett billedspråk

**Silhuetten finnes ett sted: `gen_glyphs.screw_profile()`.** Katalogglyfen i
beslagtabellen, raden i stegets egen beslaglegende og skruen som tegnes inn i
selve stegtegningen er den samme konturen, lagt inn i hvert sitt
koordinatsystem — forsenket hode, kjerne, gjenge, spiss.

Det var ikke slik før, og det er den feilen dette avsnittet finnes for.
Stegsiden tegnet sin egen sju-punkts kapsel: en flens i den ene enden, en pigg
i den andre, ingenting imellom. Blåst opp 3,0 ganger leste den som en **pil** —
og pil er reservert for tredeler som skal føres på plass, så siden brukte
byggerens ene formkode til å si feil ting. Samtidig sto den ekte silhuetten
i legenden ti centimeter unna. To billedspråk for én ting er det en
monteringsanvisning ikke har råd til, for det er formen leseren kjenner delen
igjen på.

Med den ekte konturen bærer formen gjenkjenningen, og faktoren trenger bare
bære størrelsen: **`SCREW_FATTEN` er 2,0** (var 3,0). Hodet er
`HEAD_DIA_RATIO` = 1,95 nominelle diametre og kjernen 0,72, så en 6×120 er
23,4 mm over hodet og 8,6 mm over kjernen der den før var 34 og 18. Siden har
fått en tredjedel av blekket sitt tilbake. `W_SCREW` fulgte med ned, fra 0,60
til 0,40 penn: konturen er streken rundt et ti millimeter bredt objekt, ikke
rundt sengen, og på 0,60 var skruen en svart splint med ingen plass til
fyllkoden inni seg.

**Gjengen er en tekstur, og en tekstur følger rasteret** — nøyaktig samme regel
som fyllkoden har (`gen_glyphs.thread_pitch`). Stigningen er den groveste av

> **formkravet** 1,15 × d, og **oppløsningskravet** at én TANN — en halv
> periode — aldri blir under `THREAD_MIN_PX` = 4,5 piksler der siden faktisk
> rastres.

Blir det da færre enn `THREAD_MIN_PITCHES` = 2,5 hele omdreininger igjen på
den gjengede strekningen, tegnes ingen gjenge: konturen faller tilbake på sin
egen omhyllingskurve — samme hode, samme kjerne, samme spiss, uten bølgen. Det
er én nedgradering, ikke et annet billedspråk.

Beviset ble tegnet, ikke argumentert. De to stedene endringen ble bedømt på er
hjørnet på steg 1 og stubbefotklyngen på steg 5, klippet ut av de ferdige
sidene før og etter (`docs/preview/krop-steg1-*.png`,
`krop-steg5-*.png` — `docs/preview/` er gjennomgangsmateriale og er ikke
sjekket inn, se `.gitignore`). Skal formen endres igjen, klippes de to samme
utsnittene på nytt: det er der en pil ser ut som en pil.

To ting til er verdt å vite. **Stigningen regnes av SANN diameter, ikke tegnet.**
Licensen er bredde; en stigning er et mål langs skruen, og regnes den av den
feite bredden dobles den sammen med bredden mens lengden står — da får en 5×40
to omdreininger på siden der glyfen viser sju. **Og siden må kjenne rasteret
sitt før den tegner**: `Page.px_per_unit` settes i `render_step()` med én gang,
ikke først i `write()`, fordi gjengen velges mens skruen tegnes.

### Kjeden i et beslaghjørne (R9)

**Et beslag og skruene som holder det er én demontering, ikke tre.** R1 sier
hvilken vei et beslag går av — minus resultanten av drivvektorene til skruene
som holder det — og det er en opplysning om leddet, ikke om papiret. Men den
sa ingenting om hvor LANGT, og ingenting i det hele tatt om skruene som går
gjennom beslaget. De to taushetene er det J12-hjørnet på steg 1 var ulesbart
av: beslaget fløt så langt av setet som papiret tillot, skruene bakket ut av
det med hvert sitt sprang som ikke hadde noe med beslagets å gjøre, og de tre
prikkede linjene skar hverandre midt i et hjørne leseren ser på som ett stykke
arbeid.

Regelen er **ett sprang, `d`, for hele klyngen**:

    sete --d--> beslaget --d--> hver av beslagets egne skruer

Beslaget står `d` fra setet langs demonteringsretningen. Hver skrue som sitter
i beslaget fortsetter fra der BESLAGET havnet, langs sin egen drivakse — som
aldri bøyes — til avstanden fra tegnet spiss til hullet i det flyttede
beslaget også er `d`. To like sprang leses som én bevegelse utover; tre ulike
leses som tre uhell som tilfeldigvis peker samme vei.

Det som fortsatt er fritt er `d` selv, og friheten tilhører KLYNGEN. Finnes det
ikke plass, tas et lengre slag — av alle sammen, samtidig. En enslig skrue som
lander oppå en annen kropp køer seg én kroppslengde lenger ut langs sin egen
akse (R2); en skrue i en klynge får ikke, for en køet skrue er en skrue ute av
takt. Stubbefothjørnet på steg 5 — fire 5×40 og en vinkel — trenger det andre
slaget; J12s to greier seg med det første.

To asserter holder den, og begge måler blekket:

* **Takten** (`assert_chain_rhythm`). Hver prikket linje i klyngen leses der
  den landet, og de skal være like lange. Slarken er 2 % av spranget, fordi
  beslagets lenke er flytevektoren nøyaktig mens skruens leses av spissen på
  den tegnede silhuetten — samme tall kommet fram to veier.
* **Nøstingen** (`assert_chain_untangled`). Ingen skrues linje krysser
  beslagets egen lenke tilbake til setet, og ingen linje går tvers gjennom en
  kropp i sin egen klynge. Det første er selve påstanden kjeden gjør; det
  andre er at en prikket linje gjennom en silhuett leses som silhuettens egen
  vei.

**Det som IKKE er asserta, og hvorfor.** To SØSKENLINJER som møtes like ved
beslaget. J12 driver én 5×40 inn i stolpen og én opp i lekta, i rett vinkel,
gjennom to hull som ligger 17 mm fra hverandre på papiret — og dette kameraet
setter lektaskruens hull på andre siden av stolpeskruens egen akse. Da må de to
møtes, og de møtes i et punkt på den aksen som ingen takt kan flytte: kortes
spranget, flytter krysset seg fra den prikkede linjen over på den SOLIDE
kroppen, som er verre. Det er en opplysning om hvor leddet ses fra, ikke et
valg tegningen tok, og reglene her asserter bare det tegningen kan adlyde.

**Merket til et beslag står på randen, ikke oppå.** Et vinkelbeslag 40×40 og et
merke på 49 mm er omtrent like store, så et merke som oppfyller R6 ved å sitte
PÅ beslaget, oppfyller den ved å SKJULE det — og leseren sitter igjen med en
bokstav der delen skulle vært. Halen merket søker ut fra ligger derfor på
beslagets egen utoverkant, den siden som vender fra setet, så det første
kandidatpunktet er et merke som tangerer platen i stedet for et som dekker den.

Beviset ble tegnet, ikke argumentert, i de to samme utsnittene som formvalget
ble avgjort i: `docs/preview/krop-steg1-v3.png` og `krop-steg5-v3.png`.

### Merking og sammenslåing

* **Bokstav i ring** (Ⓐ, Ⓑ …) knytter et festemiddel på tegningen til en rad i
  tabellen under bildet. Rekkefølgen er «flest først, uavgjort brytes på navn»,
  og både `gen_doc_tables.py` og `render_lineart.py` regner den ut av de samme
  radene, så de kan ikke bli uenige.
* **Fyllkoden: bokstaven én gang til, som mønster.** Et hjørne med fire
  festemidler i tvang leseren til å finne og lese et 5 mm tegn for å se hvilken
  skrue som var hvilken. Hver bokstav har derfor sitt eget fyll, og skruens
  silhuett bærer det — på stegtegningen og i stegets egen festetabell under
  bildet:

  | | Fyll | Hvorfor der |
  |---|---|---|
  | Ⓐ | åpen | flest av — sekston heldekte skruer ville sortnet siden |
  | Ⓑ | skravert | |
  | Ⓒ | krysskravert | grovere rute enn Ⓑ, ellers er de to bare to gråtoner |
  | Ⓓ | heldekt | sjeldnest, og oftest et vinkelbeslag, som er heldekt fra før |

  Koden er redundant med vilje: formen skiller 5×40 fra 6×120 med god margin,
  men den skiller dårligere jo nærmere hverandre to skruer ligger — 5×60 mot
  6×80 er ett diametertrinn og 20 mm; bokstaven krever at leseren finner og
  leser et lite tegn; sammen holder de hverandre oppe, og ingen av dem trenger
  farge.

  **Men bare der formen faktisk svikter.** Fyllet er ikke gratis: det legger et
  mønster i hver eneste skrue på siden, og på en side der silhuettene skiller
  seg fra hverandre helt av seg selv gjør det bare siden travlere. Koden ble
  kjøpt for ett problem, og betales bare der problemet finnes. Vilkåret er
  regnet ut, ikke vurdert — to festemidler på samme side er **tvetydige av
  form** når

  > lengdeforskjellen er under **25 %** av den lengste, **og** diameterne er i
  > samme klasse (like) eller skiller seg med høyst **1 mm**.

  Finnes ett slikt par på siden, kodes **hele** sidens sett; finnes det ingen,
  står alle festemidlene i ren kontur, med bokstaver og antall som før. Hele
  settet, ikke bare paret: kodede og ukodede skruer om hverandre på ett ark er
  en tredje opplysning ingen har lært leseren.

  Tallene står ett sted, i `gen_glyphs.ambiguous_pairs()`, og svaret følger
  steget ut i `byggesteg.json` som `fill_code` — utledet av leddataene, ikke
  skrudd på for hånd (se §5). Med dagens ledd slår regelen til på **ingen**
  steg: `fill_code` står `false` på alle tolv, og ikke ett ark i manualen
  tegnes kodet. Nærmest kommer 5×60 mot 6×80 — de møtes på steg 5 og steg 6,
  de er ett diametertrinn fra hverandre, og 60 av 80 er nøyaktig **25 %**.
  Vilkåret sier «under 25 %», så paret faller utenfor på likhetstegnet. Resten
  er ikke i nærheten: 6×80 mot 6×120 er 33 %, og det paret som ligger tettest i
  lengde av alle — 6×120 mot veggfestets 8×100, 17 % — er to diametertrinn fra
  hverandre og deler dessuten ingen side.

  At regelen står uten å fyre er ikke et argument for å ta den bort. Den er
  skrevet for den dagen et ledd bytter lengde, og da skal svaret komme av seg
  selv i stedet for av at noen husker det. En regel som først skrives når den
  trengs, er en regel som ble skrevet én gang for lite.

  **Ett mønster per silhuett (R8).** Gjengen og fyllkoden er to teksturer av
  samme størrelsesorden inne i en kropp som er ti–tolv millimeter bred, og
  legges de oppå hverandre leses ingen av dem — skraveringen og gjengetennene
  går sammen til et tauverk, og Ⓑ og Ⓒ blir like. Prøven ble tegnet begge
  veier før valget: med begge er B og C to teksturerte tau, med én hver er B
  rene parallelle streker og C rene ruter.

  Derfor tar koden kroppen fra gjengen — **men bare der koden faktisk ER et
  mønster**. `open` er fraværet av ett, og den deles ut til den bokstaven siden
  har flest av, så den vanligste skruen på en kodet side beholder gjengen sin
  og ser ut som det samme objektet den er på alle andre sider. Ingenting
  konkurrerer med den der, så ingenting er kjøpt ved å
  ta den bort. Regelen er `render_lineart.thread_cues()`, og
  `fyllkontrast.png` tegnes med den, ellers beviser prøven en tegning manualen
  ikke lager.

  **Retningen er asserta, ikke fyllet.** `render_lineart.assert_fill_code_rule()`
  måler det som ble tegnet: en side med et tvetydig par som likevel kom ut uten
  fyll stopper bygget — der har leseren ingenting igjen å skille de to på. Den
  motsatte feilen, fyll på en side som ikke trengte det, er en rapportlinje og
  ikke en stopp: den koster blekk, ikke anvisning.

  **Settet er bevist, ikke valgt.** `python tools/render_lineart.py
  --fill-contrast` skriver `docs/preview/fyllkontrast.png`: hver kode i den
  størrelsen den minste bokstavsiden faktisk gir en skrue, i tabellglyfens
  størrelse, og i halv størrelse som stresstest. Prøven blir stående selv om
  ingen side i dag bruker koden: den er dokumentasjonen på hvorfor settet ser
  ut som det gjør, og den skal leses igjen den dagen et ledd bytter skrue.
  Prøven avgjorde to ting som
  ikke lot seg resonnere fram — **hodet alene kan ikke bære koden** (et
  forsenket hode er en 5 mm flens, sju piksler på siden, og der er alle
  mønstrene like, så hele silhuetten fylles), og **krysskraveringen må ha
  grovere rute enn skraveringen**. Skal settet endres, endres prøven først.
  Beslagene står utenfor: en vinkel er allerede en heldekt plate, og et mønster
  oppå den ville lest som en tredje slags flate.
* **En stegside med bare én type festemiddel får ingen bokstaver.** Ikonet i
  tabellen er allerede hele svaret — og da er det heller ingen fyllkode, for en
  kode med bare én verdi koder ingenting.
* **Antallet står ikke i bildet.** Hver skrue steget driver tegnes som sin egen
  kropp, så «2×» ved siden av én av dem sier ingenting bildet ikke sier.
  Antallene står i stegets tabell under bildet, og bare der, der tall leses i
  stedet for å telles. De sto en gang begge steder — også i en hvit rute i
  hjørnet av tegningen — og det var én kilde for mye: byggmesteren leste
  tabellen, og ruta dekket strektegning for å si det samme en gang til
  (erfaringsrunde 1). Kontrollen svekkes ikke av det: `check_coverage` teller
  KROPPENE siden har satt av, ikke tallene den har trykt.
* **Ett merke per tegnet kropp (R4), og bare én kropp der to silhuetter faller
  sammen (R2).** Spørsmålet er ikke hvor langt fra hverandre to festemidler er
  — det er om de to SILHUETTENE siden tegner havner på samme papir. To som gjør
  det kan bare tegnes én gang, og det ene merket står da for begge (antallet
  ligger i stegets tabell). To som ikke rører hverandre er to ting leseren kan telle,
  selv 30 mm fra hverandre, og da er de to merker. Blir det trangt, er svaret
  ikke å slå dem sammen, men det ene trekket et eksplodert festemiddel uansett
  har: lenger ut langs sin egen akse. Begge deler er asserter som måler blekket
  (`assert_bodies_apart`).
* **Kontakt eller leder (R6).** Et merke skal enten RØRE en av kroppene det
  navngir — sitte på hodet som et flagg på en stang — eller ha en tynn strek
  inn til den.
  Det finnes ingen tredje plass. Et merke som svever ved siden av en klynge er
  ikke en anvisning, det er en gåte, og på steg 5 sto det tre av dem og gjettet
  samtidig. Regelen er priset inn i `layout.place()` — kontakt er verdt mer enn
  hvilken som helst mengde hvitt papir — og `assert_badges_anchored()` måler
  den etterpå av blekket: rører merket sin egen kropp, ender lederen på den, og
  starter den i merkets egen rand.
* **Ett merke per type per klynge (R7).** Åtte like bokstaver nedover en
  stigevange er ikke åtte opplysninger, det er én, gjentatt til den blir tapet
  — og tapetet er det som trenger bort merket som faktisk sier noe nytt.

  Første versjon av regelen slo sammen et LØP: samme bokstav, samme ledd,
  kroppene i en ubrutt kjede, ingenting fremmed imellom. Den var for forsiktig
  til å hjelpe der det trengtes. Stubbefothjørnet på steg 5 kom ut med elleve
  bokstaver over to ledd, fordi to ledd er to ledd og fordi Ⓓ-beslaget sto midt
  i hvert eneste løp og brøt det. Elleve bokstaver for FIRE slags festemidler,
  i et hjørne leseren ser på som ett stykke arbeid.

  Enheten er derfor ikke løpet, men **stedet**. En klynge er alt som ligger
  innenfor `CLUSTER_R_BADGES` = 16 merkeradier fra en kjerne — uansett ledd,
  uansett type — og inne i én klynge bærer hver TYPE nøyaktig ett merke, det
  første i sidens egen tegnerekkefølge. Merket står for hele familien sin.
  Beslaglegenden under bildet er hele nøkkelen: hver type på siden har sin rad
  der, med bokstav, glyf, antall og handelsnavn, så ingenting av det leseren
  blir fortalt er borte — bare hvor mange ganger.

  Klyngen er en KULE og ikke en kjede, med vilje. Kjeding er transitiv, og på
  en side som spilefeltet ville én kjede slukt hele sengen og latt én bokstav i
  et hjørne stå for tjueåtte skruer en meter unna. En kjerne og en radius kan
  ikke gjøre det: et merke er aldri lenger fra kroppen det står for enn radien
  regelen er skrevet med.

  To asserter holder den ærlig, og begge måler blekket. **Dekning**
  (`assert_badges_cover`): hvert eneste tegnede festemiddel med en bokstav må
  ha den bokstavens merke blant merkene som står for NETTOPP DET — ikke et
  merke et sted på siden, ett hvis egen familie det er i. **Eierskap** (R5, i
  `assert_badges_anchored`): merket må ligge nærmere ETT AV medlemmene i sin
  egen familie enn noen fremmed kropp. Det er den gamle regelen med «min»
  utvidet fra én kropp til familien — som er nøyaktig det merket nå navngir.

  Resultatet, side for side: 5 → 4 merker på steg 1, 7 → 3 på steg 3, 11 → 7 på
  steg 5, 26 → 7 på steg 6, 6 → 6 på steg 9. 55 bokstaver ble 27.

  **Tillegget: en familie må SE UT som én, og den må være innen rekkevidde.**
  Sammenslåingen er kjøpt med et argument om BILDET — leseren ser en rekke av
  det samme og trenger å få det sagt én gang — og argumentet svikter i det
  bildet slutter å gjenta seg selv. Derfor to kutt til gjennom hver type, og de
  spør hver sin ting.

  *Homogenitet.* Spredningen i TEGNET lengde inne i familien,
  (lengste − korteste) / lengste, høyst `HOMOGENEITY_SPREAD` = 25 %. Det er den
  samme fjerdedelen fyllkodens tvetydighetsprøve bruker, og av samme grunn:
  under en fjerdedel er to lengder én lengde for øyet, over den er de to ting.
  Er typen ikke homogen, slås den ikke opp i sine enkeltdeler, den KUTTES i
  gapene: åtte like stigeskruer og én forkortet raring er ni kropper, to
  utseender og to merker. `assert_badges_homogeneous()` måler det på blekket —
  lengdene leses ut av `Page.record`, av de silhuettene som faktisk ble tegnet.

  *Rekkevidde.* Klyngen er en kule om en KJERNE, så to av medlemmene kan ligge
  to radier fra hverandre selv om ingen av dem ligger mer enn én radie fra
  kjernen — og da er regelens eget løfte («et merke er aldri lenger fra kroppen
  det står for enn radien») brutt. Samme grådige kule, kjørt inne i typen,
  holder løftet: den første kroppen i tegnerekkefølgen tar inn alt innenfor
  rekkevidde av seg selv, og resten sår neste merke. Asserten står i
  `assert_badges_anchored()` sammen med de andre målingene av merket.

  Med dagens sider slår **homogenitetskuttet ikke til noe sted**: J12-paret som
  saken begynte i måler 36,5 og 35,6 mm på papiret — 2,5 % fra hverandre, altså
  én ting sett to veier — og deler Ⓑ som før. Rekkeviddekuttet slår til ett
  sted: de to stubbefotbeslagene på steg 5 ligger 437 mm fra hverandre i én og
  samme klynge, og uten kuttet ville det andre hjørnets vinkel stått uten
  bokstav med sin egen Ⓓ en halv side unna.
* **KROPPER slås aldri sammen på tvers av ledd.** Regelen ble skrevet på steg
  3, der endebjelkens to 6×90 og bæreklossens ene møttes i det samme hjørnet
  og «3×» ville sendt byggeren til feil hull. Klossen er borte nå, men
  regelen står: to ledd i samme hjørne er to kropper. Regelen er ett flagg i
  `render_lineart.py` (`MERGE_ACROSS_JOINTS`), så den er en linje å snu og
  ikke en antakelse å lete etter — men den står av, og tegningene er tegnet
  med den av.

  Merk forskjellen fra R7: den regelen slår sammen BOKSTAVER og går gjerne på
  tvers av ledd, fordi en bokstav bare peker på en rad i en tabell. Denne
  regelen slår sammen KROPPER og et antall, og et antall i feil hull er en feil
  anvisning. Hver skrue tegnes fortsatt som sin egen kropp der den er sin egen
  kropp.
* **Et merke ligger nærmere sin egen familie enn noe annet (R5).** Et badge
  ved siden av feil skrue er ikke en trang tegning, det er en feil anvisning.
  Regelen er en assert som måler blekket: merkene leses ut av `Page.record`
  der de LANDET, og hvert av dem må ha en av kroppene det står for som
  nærmeste kropp — målt mot kroppenes egne kapsler, ikke mot punkter i
  nærheten av dem.
* **Ingen lederlinjer ut i tegningen (R3).** Bokstaven knytter allerede merket
  til raden i legenden under bildet, og den gjør det for alle merkene — ikke
  for de fire som tilfeldigvis lå nærmest. Da hjørneruta fantes, trakk den opp
  til fire lange grå streker tvers over strektegningen for å si det samme. Lupen er noe annet og blir stående: den
  bærer virkelig strektegning, og den korte lederen sier hvilket sted som er
  forstørret. R6-lederen er en tredje ting igjen: den er kort, den går fra ett
  merke til den ene kroppen merket navngir, og den finnes bare der merket ikke
  fikk plass oppå den.
* **Ingenting forsvinner.** Et merke som blir trengt bort gir antallet sitt til
  merket som trengte det bort, og `check_coverage` sammenligner totalen med
  stegets egen tabell. Og et merke som ble slått sammen slik at en DEL mistet
  sin eneste visning, får merket sitt tilbake (`restore_orphans`).
* **Over `EXPLODE_MAX` merker på én side** bytter siden til fantomstil.
  Tjueåtte skruer hengende i lufta over en seng er en hekk, ikke en anvisning.
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

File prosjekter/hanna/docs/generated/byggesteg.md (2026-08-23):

<!-- GENERERT AV generate_loftbed.py / tools/gen_doc_tables.py.
     IKKE REDIGER FOR HÅND - kjør `mise run build`. -->

# Steg for steg

Rekkefølgen er ikke fri. Sengen står inntil bakveggen og inntil begge sidevegger, og den bygges på plass. Alt som skal skrus eller boltes fra en flate som ender mot vegg, må gjøres før den flaten kommer inntil veggen. Derfor bygges den bakfra og utover.

Bildeversjonen av de samme stegene, med samme nummer, ligger i [MONTERING.md](../MONTERING.md). Mål slår du opp i [nøkkelmål](nokkelmal.md) og [kappliste](kappliste.md); leddene står i J-oversikten i [ASSEMBLY.md](../ASSEMBLY.md#4-j--leddene), med antall og forboring i [beslaglista](beslagliste.md).

**Hvert steg har en «festeplassering»-tabell**, og den er svaret på hvor langt inn og hvor langt opp på materialet et feste skal stå. Hullet er oppgitt i DELENS egne mål — så mange mm inn fra en navngitt ende, så mange mm inn fra en navngitt kant, og senteravstand mellom hullene i samme rad. Ta tabellene med til steg 0: det er der du merker opp og borer, mens delene ennå ligger løse på bukken — med to unntak, og begge står i punktene under.

* **Romdelene bores ikke på bukken.** De er kappet med overmål i den enden som møter vegg, og alle målene i raden er tatt fra nettopp den enden. De finkappes etter målt nisjebredde først, og bores så. Siste punkt i steg 0 sier hvilke.
* **Veggfestene har ingen X-mål i det hele tatt.** Stenderne bestemmer, og de finnes bare i rommet. Raden gir høyden, diameteren og regelen — og hullene bores på stedet.
* **Ytterenden** er den enden av delen som peker mot nærmeste endevegg, **innerenden** den som peker inn mot sengas midte. Derfor gjelder ett mål begge sider av senga — og modellen måler at de to halvdelene faktisk projiserer til samme tall før det skrives.
* **Stående deler måles ovenfra.** Foten kappes i vater etter at rammen står, så den enden finnes ikke ennå når du borer.
* **«midt på» er senterlinjen.** Riss den opp med senterlinjal eller med to diagonaler — ikke mål fra den ene siden.
* Målene er senter av hullet. Retningen skruen drives, og hvorfor akkurat den veien, står i [skrueretninger](skrueretninger.md).

## Før steg 0 — mål rommet

Nisja er hverken i vinkel eller i vater, og senga skal stå i begge deler. **Senga er referansen, ikke rommet — bygg i vater og lodd, og ta skjevheten i delene som møter vegg og gulv.**

**Slik gjør du:**

1. Vent til vegger og gulv er ferdige. **Mens veggen er åpen: legg spikerslag i sonene under.** Etterpå kommer du ikke til.
1. **Riv fotlist og alt annet listverk langs bakveggen i hele nisjas bredde — alle 1990 mm — før rammen reises.** 4 deler står både PÅ gulvet og I veggplanet Y -48: de to bakre hjørnestolpene og de to bakre benkeføttene, og en list under dem skyver hele bakkanten ut fra veggen.
1. Slå et vannrett høyderiss rundt hele nisja med linjelaser, 1000 mm over ferdig gulv. Alt måles fra risset, aldri fra gulvet — spikerslagsonene under står i begge notasjoner, og det er riss-kolonnen du setter dem etter.
1. Sett laseren som loddlinje midt i nisja. Mål ut til hver endevegg i rutenett: 5 høyder × 3 dybder på hver vegg. Legg sammen paret i hvert punkt. **Minste sum er nisjas minste bredde.**
1. **Mål nisjedybden på BEGGE endevegger** — fra bakveggen og ut til nisjas åpning, i de samme 5 høydene. Minste dybde må være minst **1500 mm**, og det er bakrammen som setter kravet, ikke senga: senga er 836 mm dyp, men bakrammen bygges liggende på gulvet inne i nisja og tippes opp derfra (steg 1 og 2). Liggende tar den sin egen høyde, 1500 mm, ut fra bakveggen. Er nisja grunnere enn det, får rammen ikke ligge — og da lar den seg ikke reise heller, for 1990 mm bredde går ikke å svinge inn i en 1990 mm åpning.
1. Er minste bredde et annet tall enn 1990: sett den inn som `WALL_SPAN` i `generate_loftbed.py` og kjør `mise run build`. Kapplista regner seg om.
1. Gulv: mål ned fra risset i sengas fire hjørner og på midten. Merk det høyeste punktet på gulvet. Senga bygges ned fra det.
1. Kapp verksteddelene nå. Romdelene tilpasses på stedet: stolper og føtter kappes 20 mm for lange og trimmes i bunn til rammen står i vater — strek opp med avstandskloss, meddrag. Sidevangene kappes 10 mm for lange i hver veggende og finkappes etter målt bredde. Ytterste endespile strekes opp etter veggen med fast avstand, så fugen blir jevn.
1. **Romdelenes hull bores først når romdelen er finkappet.** Hvert hull i dem er målt fra den enden som ennå har 10 mm overmål på seg, så rekkefølgen er kapp først, drill etterpå. Kapplistas rombolk sier hvilke deler, og siste punkt i steg 0 sier hvilke ledd.
1. **De fire hjørnestolpene står helt inntil endeveggen — null klaring.** Derfor strekes veggsiden på hver av dem, hver gang: sett stolpen på plass, hold den i lodd, og strek opp veggsiden med avstandskloss der veggen buler. Høvle av til stolpen står i lodd inntil veggen. Ingen monn i bredden — det er tre som skal bort, ikke legges til. Buler veggen og du lar det stå, skyver bulen hele rammen ut av lodd.
1. Kapp kanter som møter vegg eller gulv med lite bakfall. Da er det bare den synlige kanten som bestemmer fugen.

**Spikerslag i veggen:**

| Sone | Fra ferdig gulv | Fra høyderisset (1000) | Vegg | Del som ligger an her | Feste i veggen |
|---:|---|---|---|---|---|
| 1 | **0–1402** | **-1000..+402 krysser risset** | Hjørnene, mot endeveggene | Hjørnestolpe, bak (veggside) (2 stk.) | — (bare anlegg) |
| 2 | **229–297** | **-771..-703 under risset** | Bakveggen | Benkevange, bak (gjennomgående) | — (bare anlegg) |
| 3 | **614–682** | **-386..-318 under risset** | Bakveggen | Bordbærelekt, bak | J12-V, 3 stk. |
| 4 | **1402–1500** | **+402..+500 over risset** | Bakveggen | Sidevange, øvre | J14, 6 stk. |

To notasjoner, samme sone. **Målt fra ferdig gulv** er modellens egen Z. **Målt fra høyderisset** er den samme høyden minus 1000 — minus er *under* laserlinja, pluss er *over* den. Gulvet er skjevt og risset er ikke: står du ved den åpne veggen med målebåndet på laserlinja, er det den andre kolonnen du setter sonene etter.

**Spikerslaget skal ligge i alle 4 sonene, også der det ikke kommer en skrue.** Kolonnen *Del som ligger an her* sier hva sengen presser mot veggen i den høyden — det er derfor sonen finnes. Kolonnen *Feste i veggen* sier hva som faktisk skrus fast der, og «— (bare anlegg)» betyr at sengen bare hviler mot veggen i den sonen. En gipsplate uten tre bak gir etter under anlegg også.

Gulv-kolonnen er fra **ferdig gulv**. Legges gulvet etterpå, må påforingshøyden legges til — i begge kolonner, for risset slås fra ferdig gulv det også.

Hva som kappes nå og hva som kappes på stedet: [kapplista](kappliste.md).

**Sjekk før du går videre:**

* Høyderisset skal gå hele veien rundt nisja og møte seg selv. Gjør det ikke det, står laseren feil.
* Er forskjellen mellom minste og største bredde større enn 10 mm, mål om. Kapp uansett etter den minste.
* Nisjedybden skal være minst 1500 mm i hvert eneste målepunkt på begge endevegger — ikke i snitt. Det grunneste punktet er det rammen tar borti når den ligger. Kommer du under, må rammen bygges på et annet gulv, og da må den bæres inn ferdig reist gjennom en åpning som er nøyaktig like bred som den selv. Det går ikke.
* Sjekk at spikerslagene ligger i sonene før veggen lukkes — målt ned eller opp fra høyderisset, ikke opp fra gulvet.
* Bakveggen skal være bar helt ned til gulvet i alle 1990 mm, ikke bare der de 4 delene i veggplanet lander. Hold en rett list mot veggen nederst: den skal ligge an hele veien.
* Hver hjørnestolpe skal stå i lodd begge veier. Vipper den fordi veggen buler, høvles bulen av — lys i fugen der veggen viker er greit og skal stå.

## Steg 0 — Kapping, forboring og forsenking

Gjør alt sagarbeid og all boring på bukk, før noe reises. Etterpå kommer du ikke til med drillen på de flatene som vender mot vegg.

**Festemidler:** 8× Filtknott / møbeltapp ⌀40

**Ledd:** J15 — se J-oversikten i [ASSEMBLY.md](../ASSEMBLY.md#4-j--leddene) og [beslagliste](beslagliste.md)

**Slik gjør du:**

1. Kapp etter kapplista. **Verksteddelene kappes ferdig; romdelene kappes med overmål** — kapplista sier hvilke og hvor mye, og de finkappes i rommet. Alle kutt er 90°, ingen gjæring — med to navngitte unntak, og begge står i kapplista: de to kilelektene under platens forkant, og de to vinkelklossene.
1. Skråkapp de to kilelektene. De er 48×68 × 77 mm og skal sages ned i ett rett snitt fra full høyde i den ene enden til 27 mm i den andre (28,0°). Håndsag eller båndsag; overkanten — den som skal limes mot plata — skal stå urørt og plan.
1. Lag de to vinkelklossene, borjiggene til skråskruene — én til J8-B og én til J10. Hver kloss er 2 biter 48×68 × 200 mm av restene, skrudd FLATE MOT FLATE. Bor ⌀18 VINKELRETT gjennom begge mens klossen ennå er firkantet — det er hullet som styrer boret siden, ikke en rampe. Kapp så sålen av under hullet på kappsag med bladet vippet 25° (J8-B) hhv. 30° (J10).
1. **Vippen og flaten er komplementvinkler.** 25° vipp gir en såle som står 65° på den borede flaten — og dermed 25° på hullaksen, som er det leddet er regnet på. Kontroller med tommestokken før klossen får røre sengen: hullets munning i sålen skal måle 42,6 × 18 mm på 25°-klossen og 36 × 18 mm på 30°-klossen. Er ellipsen for kort, ble vippen satt på feil vinkel. Klossene bygges ikke inn i sengen — de er verktøy.
1. Merk hver del med blyant på en flate som blir skjult.
1. **Bryt alle kanter et barn kan nå, nå — mens delene er løse.** Kravet er brutt kant, ikke en bestemt metode: 45° fas eller avrunding, du velger. Fres med V-spor eller avrundingsfres om du har fres; ellers gjør en blokkhøvel eller en pussekloss med 120-korn nøyaktig samme nytte. Viktigst: plateenhetens underside — begge styrelektenes nedre kanter og begge kilene — for det er der et kne møter treet når noen sitter ved bordet. Deretter platens fire egne kanter, og så stolper, rekkverksbord, trinn og stigevangenes kanter. Modellen tegner alle deler skarpe; kantbrytningen er en instruks og flytter ingen mål.
1. Bor alle gjennomgående hull i **verksteddelene** — stolper, endebjelker og de delene kapplista sier er ferdig kappet. Diameter etter forboringskolonnen i beslaglista. Bor gjennom begge deler samtidig, med delene tvunget sammen.
1. Forsenk hodene på alle festemidler som ender i en veggvendt flate. Beslaglista sier hvilke ledd det gjelder.
1. Forbor alle treskruer etter beslaglista. I bordene og i all endeved er forboring et krav, ikke et råd.
1. **Bor setene til de åtte skråskruene nå** — mens delene er løse og ligger flatt på benken. Fire i den bakre benkevangens forside (J8-B) og fire i stubbeføttenes innersider (J10). Reist seng kommer du ikke til med hverken kloss eller tvinger. Alt om setene og klossene er tegnet opp på [setedetalj.svg](../schematics/setedetalj.svg).
1. Slik bores et sete: klem vinkelklossen mot flaten med TO tvinger, hullet rett over merket, og legg en offerkloss mot endeveden. Drillen i **gir 1 og slag AV** — et forstnerbor i slagmodus brenner og vandrer. Trekk boret helt ut 2–3 ganger per lomme og børst sponet ut; et fullt forstnerbor skjærer ikke, det gnisser. Dybden er merket du satte på boret da du lagde klossen: 20 mm langs aksen på J8-B, 18 mm på J10.
1. På den bakre benkevangen står to lommer ved siden av hverandre i hver ende, 24 mm fra senter til senter. **Bor den som ligger nærmest kanten først** — da har klossen hel flate å stå på. Når den andre skal bores, hviler klossen delvis over den ferdige lomma; legg en tynn list under den enden så den ikke vipper.
1. Forbor for skruen med det samme, mens delen ligger som den ligger: **lommebunnen er forborets egen jigg.** Bunnen står vinkelrett på skrueaksen, så et brad-point-bor satt i senter av den flate bunnen (⌀6 på J8-B, ⌀3,5 på J10) retter seg selv inn i riktig vinkel. Ikke prøv å sikte den på frihånd.
1. Slå filtknotter under alle fire hjørnestolper og alle fire stubbeføtter.
1. **IKKE PÅ BUKKEN — 10 romdeler skal bores senere.** Delene i 4 kapplinjer under «[Kapp når rommet er ferdig — romdeler](kappliste.md#kapp-når-rommet-er-ferdig--romdeler)» har 10 mm overmål i hver ende som møter vegg, og hullene deres er målt **fra ytterenden** — nettopp den enden. **En ende som ikke er kappet, er ikke et utgangspunkt.** Rekkefølgen er: mål nisja, finkapp veggendene etter målt bredde, og bor først da. Det gjelder J2, J2-B, J3, J7, J20, J17. Legg delene på bukk i rommet når de er finkappet; alt annet i dette steget gjøres ferdig i verkstedet.

**Sjekk før du går videre:**

* Romdelene skal IKKE kappes ferdig nå, og hullene i dem skal ikke bores nå. Kapplista sier hvilke — de kappes med overmål, finkappes i rommet, og bores der.
* Legg de to lengste delene — sidevangene — inn i rommet nå og sjekk at de går fritt forbi begge vegger. De er kappet kortere enn veggavstanden nettopp for dette.
* Legg delene i fire hauger på gulvet, én per steg. Du kommer til å lete mindre.
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

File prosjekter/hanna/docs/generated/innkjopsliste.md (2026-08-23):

<!-- GENERERT AV generate_loftbed.py / tools/gen_doc_tables.py.
     IKKE REDIGER FOR HÅND - kjør `mise run build`. -->

# Innkjøpsliste — trevirke

Høvlet konstruksjonsvirke C24 der ikke annet er nevnt. Kappingen under er regnet med 4 mm sagsnitt mellom hvert kutt, og hvert bord er valgt som den korteste salgslengden som rommer det som skal kappes av det — blant de lengdene dimensjonen faktisk selges i. Se merknadene nederst.

Romdelene kappes for lange og finkappes i rommet — se [kapplista](kappliste.md). Overmålet er regnet inn i kappeplanen under, og står som **+ tall** etter lengden: det er tre som går av bordet. Det koster likevel ikke ett bord mer — det går av resten, og det er en assert.
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

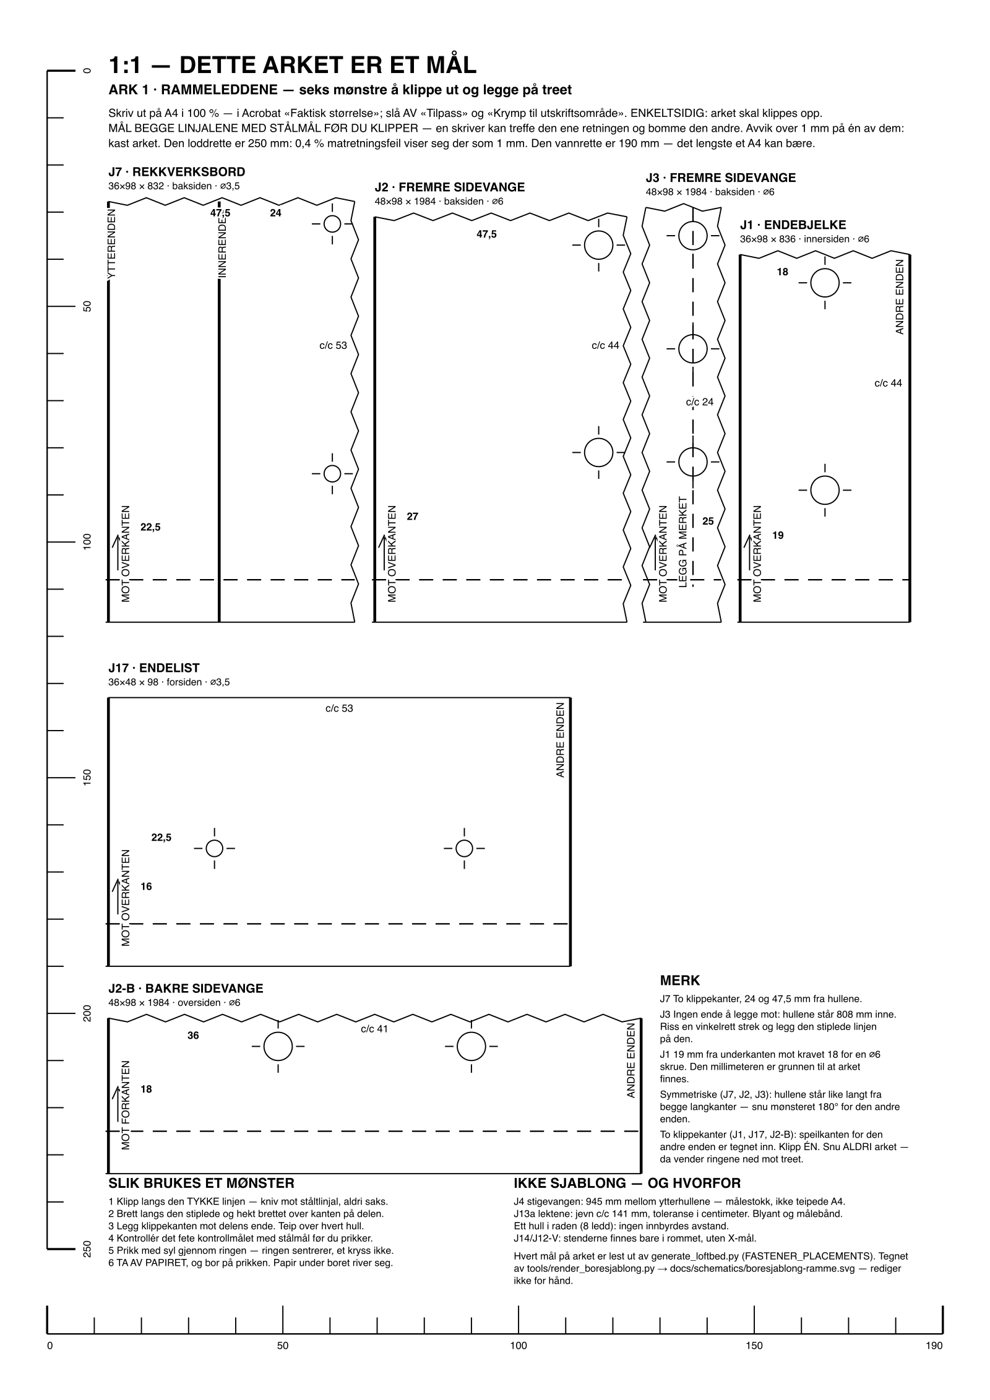
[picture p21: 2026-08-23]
prosjekter/hanna/docs/schematics/boresjablong-ramme.png

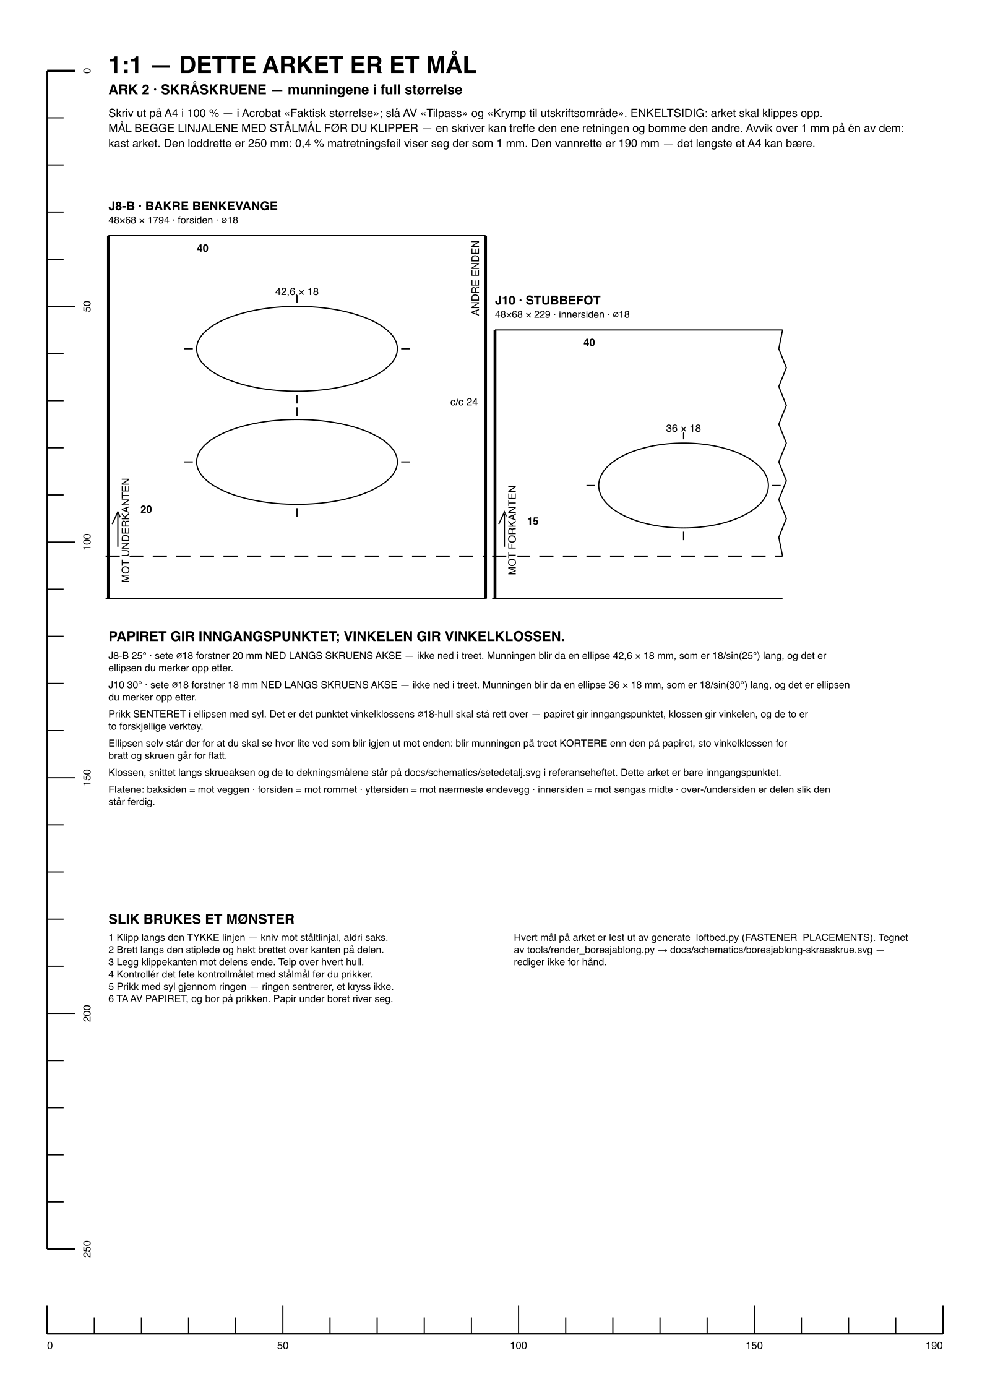
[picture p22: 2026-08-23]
prosjekter/hanna/docs/schematics/boresjablong-skraaskrue.png

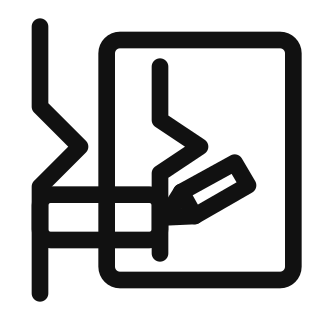
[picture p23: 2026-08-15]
prosjekter/hanna/docs/img/ikon/meddrag-ja.png

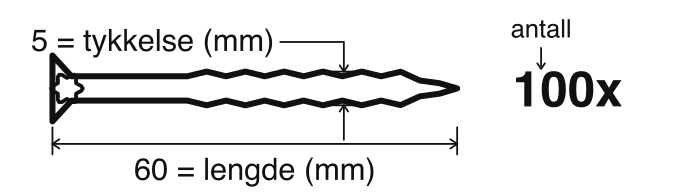
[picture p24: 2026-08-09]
prosjekter/hanna/docs/img/beslag/notasjon.png

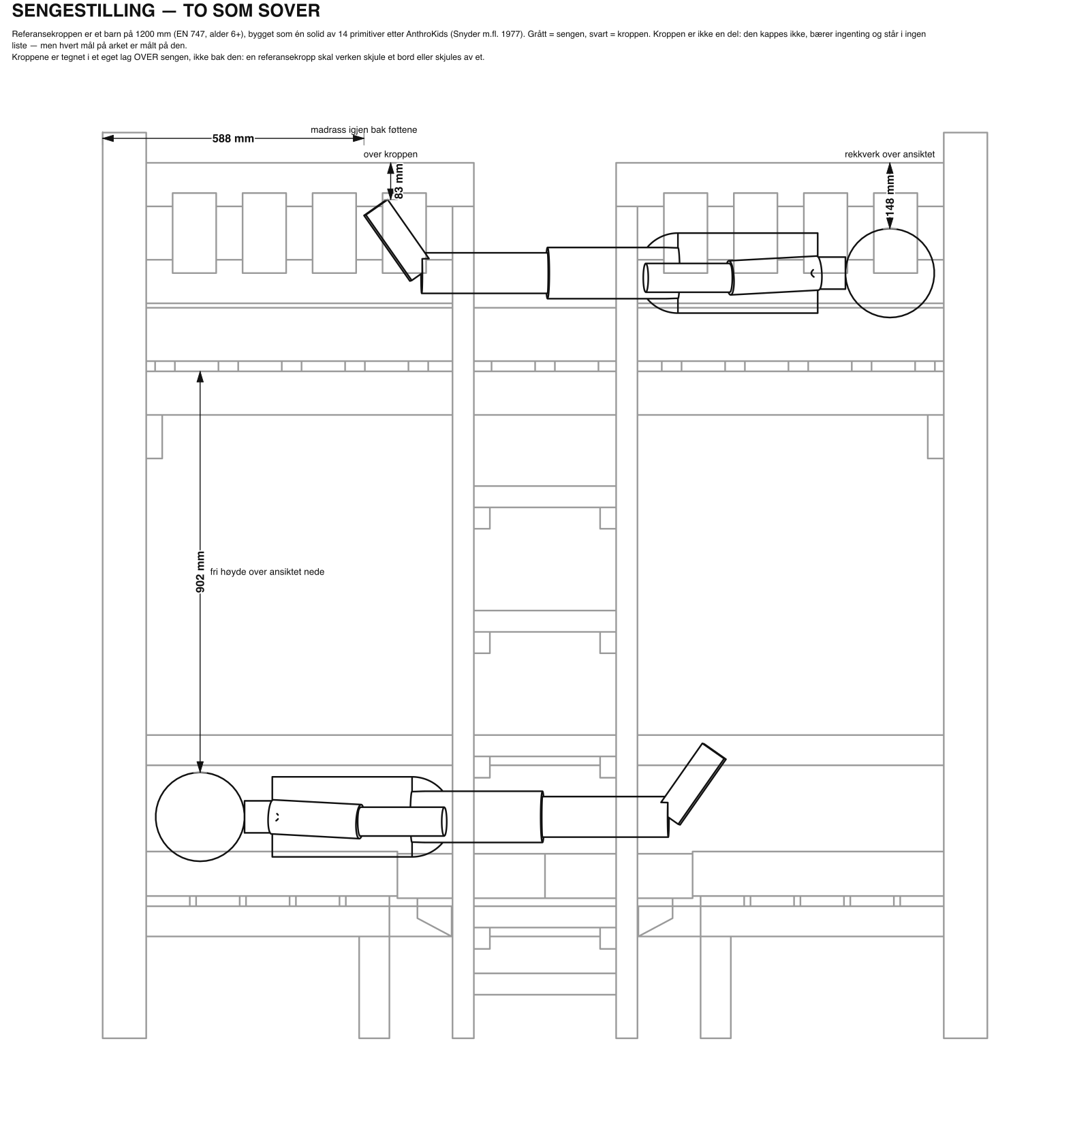
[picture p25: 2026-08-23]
prosjekter/hanna/docs/img/bruk-sengestilling.png

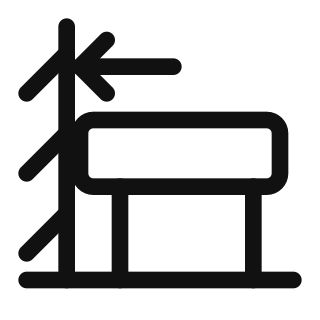
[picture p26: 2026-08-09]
prosjekter/hanna/docs/img/ikon/veggfeste-ja.png

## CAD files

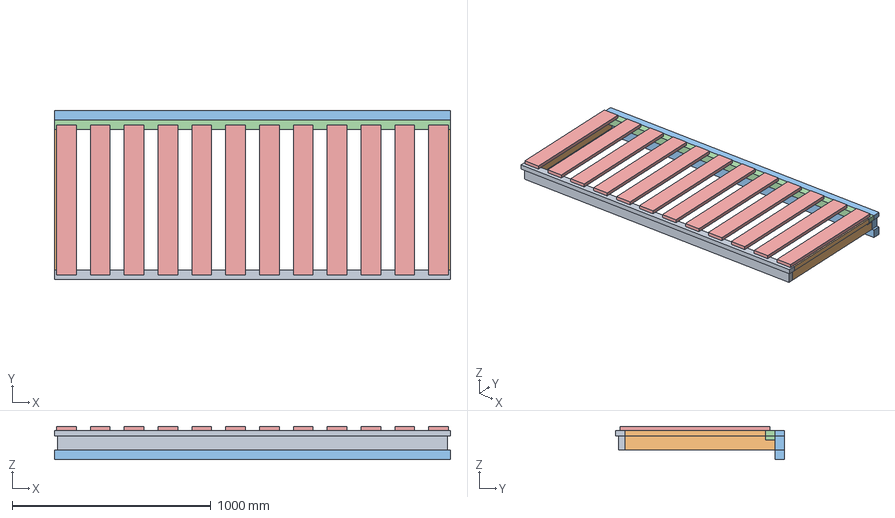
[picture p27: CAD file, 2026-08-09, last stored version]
bed_frame.step
1990.0 x 850.0 x 168.0 mm
Back Wall Ledger
Left Side Ledger
Right Side Ledger
Front Load-Bearing Beam
Slat Cleat
Slat_1
Slat_2
Slat_3
Slat_4
Slat_5
Slat_6
Slat_7
Slat_8
Slat_9
Slat_10
Slat_11
Slat_12

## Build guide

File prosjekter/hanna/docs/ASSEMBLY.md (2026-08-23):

# HANNA — loftseng, byggeveiledning

HANNA er en loftseng med sofa, bord og ekstraseng under. Den er bygget på mål
for en nisje mellom to vegger og står **inntil bakveggen og inntil begge
sideveggene**. Den bygges på plass.

> **Denne sengen er ikke reversibel.** Den lange baksiden skal stå mot vegg og
> skal skrus fast i veggen. Det er ikke rekkverk på baksiden — der er veggen
> sperren. Snur du sengen, mangler den et rekkverk.

---

## Sånn henger papirene sammen

Alle mål er regnet ut fra modellen `generate_loftbed.py` og skrevet ut av
`mise run build`. Ingen mål er skrevet inn for hånd noe sted. Endrer du
modellen, endrer tabellene seg med den.

| Fil | Hva du finner der |
|---|---|
| [generated/kappliste.md](generated/kappliste.md) | Hver del: dimensjon, lengde, antall, hvor den sitter — og om den kappes ferdig nå eller med overmål og tilpasses i rommet |
| [generated/innkjopsliste.md](generated/innkjopsliste.md) | Hva du skal kjøpe, og hvilke deler som kappes av hvert bord |
| [generated/nokkelmal.md](generated/nokkelmal.md) | Ytre mål, alle høyder, alle dybdeplan, stige- og rekkverksmål, skruerader, madrassmål, sikkerhetsmål |
| [generated/beslagliste.md](generated/beslagliste.md) | Alle beslag og skruer, hvor de går, hva som forbores, hvilken side du driver fra |
| [generated/byggesteg.md](generated/byggesteg.md) | Steg for steg i tekst |
| [MONTERING.md](MONTERING.md) | Steg for steg i bilder, samme nummer |
| [schematics/](schematics/) | Tegninger |

**Denne fila gjentar ingen av de målene.** Står et mål i en tabell der, står
det ikke her. Her står det hvorfor, og hvordan. Der et tall likevel dukker opp i
teksten, er det fordi tallet *selv* er begrunnelsen — og da står det alltid med
en henvisning til fila som eier det. Regnedelen i vedlegg A henter spennene sine
fra kapplista og nøkkelmålene.

---

## 1. Verktøy

| Verktøy | Til hva |
|---|---|
| Batteridrill, 18 V eller mer | Rammen er skrudd, ikke boltet — men det er mange 6 mm skruer i heltre, og de vil ha moment |
| Trebor ⌀6 og ⌀4 | Rammeskruene: gjennomgangshull i den ene delen, styrehull i den andre. Se forboringskolonnen i [beslaglista](generated/beslagliste.md) |
| Trebor i flere små diametre til forboring | Se forboringskolonnen i beslaglista. Forbor **alltid** i bordbærelekta, i bordene og i all endeved |
| Forsenker (kjeglesenker) | Alle skruehoder i flater man tar på: benkespiler, køyespiler, trinn |
| Forstnerbor ⌀18 og ⌀12 | ⌀18: setet under hvert skråskruehode (J8-B og J10) — boret går ned i hullet i vinkelklossen, som er det som holder vinkelen; se J8-B og [setedetalj.svg](schematics/setedetalj.svg). ⌀12: kontraborene i lektene og kilene under platen (J13a/J13b) |
| Fres med V-spor eller avrundingsfres — eller høvel, blokkhøvel, pussekloss | Kantbrytningen, avsnitt 3. Ingenting her krever fres |
| Bits Torx T20 / T25 / T30 | Etter skruestørrelse |
| Sirkelsag eller håndsag + anlegg | Alle kutt er 90°, med ett unntak: de to kilelektene sages på skrå i ett langsgående snitt (J13b). Ingen gjæring i hele sengen |
| Vinkelhake, minst 300 mm | Rett vinkel i bakrammen og i sengeflaten — mål diagonalene |
| Vater, minst 600 mm | Endebjelker og vanger |
| Linjelaser, selvnivellerende kryss | Høyderisset rundt nisja og loddlinja midt i den. All oppmåling av rommet skjer fra risset — se avsnitt 3 |
| Tommestokk og målebånd | |
| To skrutvinger, minst 300 mm | Holder deler mens du borer gjennom begge samtidig |
| Blyant og syl | Merking av borsentre |
| Én person — to ved reisningen | Steg 2 (bakrammen tippes opp) og steg 4 (den fremre sidevangen løftes opp på begge endebjelker samtidig). Resten er skrevet for én mann med tvinger og hjelpelister |

---

## 2. Trevirke og beslag

Kjøp: [innkjøpsliste](generated/innkjopsliste.md).
Kapping: [kappliste](generated/kappliste.md).
Beslag og skruer: [beslagliste](generated/beslagliste.md).

Alt trevirke er høvlet konstruksjonsvirke C24. Alle beslag og skruer er
elforsinket eller varmforsinket.

**Det går ikke én bolt inn i en stolpe i denne sengen.** Stolpene er tynne på
tvers av rommet, og på den tykkelsen får en M8 ikke den kantavstanden en bolt
krever — den ville sprenge stolpen på langs. Hvert eneste ledd inn i en stolpe
er derfor **forborede treskruer i 6 mm** — det samme mønsteret som stigevangene
bruker. For en 6 mm skrue er kravet til kantavstand nøyaktig det en
stolpetykkelse gir på midtlinjen.

Det er ikke en nødløsning. **Tre bærer på tre der tre kan bære på tre.** Hver
eneste lange del hviler på noe: sidevangene på endebjelkene, den bakre
sidevangen rett på stolpetoppene, benkevangene på stubbeføttene. Ingen av *de*
skruene er opplegg.

Tre hjørner har ikke noe å hvile på, og der går den loddrette reaksjonen
gjennom stål. Det står her, rett ut, fordi det er der antallet skruer betyr
noe:

* **J1**, endebjelken mot stolpen: to 6×80 i skjær ≈ 4,0 kN mot ≤ 1 kN
  hjørnereaksjon — utnyttelse **0,25**.
* **J8**, den fremre benkevangebiten mot stolpen: to 6×80 ≈ 4,0 kN mot
  0,5 kN — **0,13**. Etter X18 er de to skrå, akkurat som J8-Bs, fordi enden
  er buttet og ikke lappet — og skråstillingen koster ingenting her heller.
* **J8-B**, den bakre benkevangen mot stolpen: to skrå 6×80 ≈ 4,0 kN mot
  0,5 kN — **0,13**. Skruene står skrått i planet, men lasten står loddrett
  på dem uansett, så skråstillingen koster ingenting.

**Her sto det åtte bæreklosser før, og de er tatt bort.** Argumentet for dem
var at delen skulle *bære på tre* i stedet for å henge i skruer. Følg det ett
skritt til, og det spiser seg selv: klossen står ikke på noe heller. Den
henger på stolpen i **én** 6 mm skrue — 2,0 kN mot inntil 1 kN, utnyttelse
0,50, den høyeste skrueraden i hele sengen. Klossen tok ikke lasten ut av
stålet; den halverte stålet leddet ellers hadde hatt.

Sprekkfaren klossen ble kjøpt mot er også målt nå. Skruene i bjelkeenden står
18 mm (3 × skruediameteren) fra bjelkens ende langs fiberretningen og 19 mm
(3,2 ×) fra kanten i den retningen lasten virker, i 36 × 98 mm C24. Det er et
helt vanlig omlegg, med bedre kantavstand enn regelen krever — ikke en sprø
endeskjøt.

**Det klossen egentlig var, var en jigg:** en hylle å legge delen på mens du
skrudde den fast. Den jobben gjør nå hullene. Alle gjennomgangshull bores i
steg 0, gjennom begge deler samtidig med delene tvunget sammen, og et
hullmønster har nøyaktig én stilling der det står over seg selv. Delen kan
ikke settes i feil høyde.

Alt dette står i lasttabellen i vedlegg A, rad for rad. Bolten er fortsatt
borte, og det er fortsatt riktig.

**Og én ting til, som ikke er statikk:** ingen skruehoder står på sengens
front. Alt fra vangenes ytterflate og fram til stolpeplanet er den eneste
flaten noen ser på, og J2, J3 og J8 skrus derfor **innenfra og ut** — gjennom
den 48 mm tykke vangen og inn i den 36 mm tykke stolpen eller stigevangen, i
stedet for omvendt. Begge veier holder målene like godt (36 + 48 er det samme
som 48 + 36, og spissdekningen er 4 mm uansett vei), så det er utseendet som
avgjør, og modellen har en assert som sier det: ingen festemiddelhoder på en
romvendt flate. Rekkverksbordene har vært skrudd slik hele tiden.

**Og du kommer til.** Bak hvert eneste av de hodene står det over 700 mm åpen
luft — inn i den tomme sengerammen for J2 og J3, inn i det åpne benkerommet
for J8 — på det tidspunktet i rekkefølgen leddet skrus, og faktisk også i den
ferdige sengen. Alle tre skrus før spilene går på. En drill med bits er en
kvart meter.

**Én konsekvens til, og den er god:** ingenting i rammen festes lenger fra en
flate som ender mot vegg. Da finnes det heller ingen skruehoder som må senkes
ned under en monteringsflate — ingen forsenkte boltehoder, ingen store
forsenkingshull, og ingen deler som må boltes ferdig før de får møte veggen.

**Det er ikke ett vinkelbeslag i denne sengen lenger.** Tegningen hadde seks —
fire under stubbeføttene og to under bordbærelektas ender — og byggherren
bygget uten alle seks (X18). Det som gjør jobben i stedet er skruer, og det er
skruer huset allerede eide: en 6×120 rett ned gjennom benkevangen i fotens
endeved og en 5×60 skråskrue opp i vangen fra fotens side (J10), og to 6×80
skråskruer ut av flatbunnede seter i bordbærelektas forside (J12) — nøyaktig
det leddet den bakre benkevangen har hatt siden K4. Beslagets vannrette flik
var hylla lekta hvilte på mens den ble skrudd; hullparet er den hylla nå, for
et hullbilde passer i én eneste stilling. Alt stål i sengen er dermed skruer,
og platemekanismen er fortsatt ren tre — lektene gjør hele jobben, se J13.

**Det står ingen lås i beslaglista, og det er ikke en glipp.** Låsen i
sengestilling var det siste åpne valget i platemekanismen. Valget er tatt: det
blir ingen lås. Begrunnelsen står i vedlegg B, avvik 4, og treverket den ville
tatt tak i står der det sto — se J13.

## 3. Byggerekkefølgen — og hvorfor den er som den er

Sengen står i en nisje. Tre av flatene er vegg. Det bestemmer alt.

**Hele baksiden av sengen er ett flatt lag.** Bakre sidevange, de to bakre
stolpene, bakre benkevange, bakre bordbærelekt, endene av begge endebjelker og
bakkanten på hver eneste spile ligger i ett og samme plan — og det planet er
monteringsflaten mot veggen. Ingenting stikker bak det.

Det gir to konsekvenser som styrer rekkefølgen:

* **Baksiden er en ramme, så bygg den som en ramme.** De bakre delene henger
  sammen i ett plan. Legg dem ut på gulvet, skru dem sammen der, og reis
  bakrammen som ett stykke. Da får du gjort alt som skal gjøres fra flater som
  senere ender mot vegg.
* **Veggfestet er den bakre sidevangen selv.** Vangen ligger flatt mot veggen i
  hele sin lengde, så sengen skrus fast rett gjennom den og inn i stenderne. Det
  trengs ingen brakett og ingen kloss. De samme skruene støtter dessuten vangen
  på midten, så det lange spennet den ser ut til å ha på papiret er ikke det
  spennet den faktisk får.

Og det som *ikke* går an, hvis du bygger i feil rekkefølge:

* **De bakre delene er fanget mellom stolpene.** Den bakre benkevangen og den
  bakre bordbærelekta er kappet til å fylle nøyaktig fra stolpe til stolpe. Står
  begge stolpene først, får du dem aldri inn — de er akkurat for lange til å
  vippes på plass, og det er meningen: det er slik de får endefeste i begge
  ender. De må legges inn mens rammen ligger flat.
* **Fronten stenger.** Alt som skal inn bakfra må være inne før den fremre
  sidevangen går på.

Derfor:

1. **Bakrammen bygges liggende, midt på gulvet** — to korte stolper og de tre
   vannrette bakre delene, som ikke kan settes inn senere.
2. **Bakrammen reises og skrus fast i veggen.** Nå står baksiden, i lodd og i
   vater, og resten bygges framover fra den.
3. **Endene bygges ut:** fremre stolpe, så endebjelke. Én ende av gangen.
   Det står ingen kloss under bjelkeenden — de forborede hullene er jiggen.
4. **Fronten lukkes:** fremre sidevange, så de to fremre benkevangene, alle
   fire stubbeføtter, de to benkespileleddene og alle fire endelister — hele
   benkens bæreverk i samme kotehøyde. Etter X18 er de fremre benkevangene
   buttet mellom stolpe og stubbefot i stolpenes eget plan, og de festes med
   lommeskruer; leddet og de fremre endelistene er det som gir spileendene
   flaten de mistet da vangen flyttet seg fram.
5. **Resten kommer forfra og ovenfra:** stige, benkespiler, køyespiler,
   rekkverk, plate, madrass.

Den samme rekkefølgen, med sjekkpunkter for hvert steg:
**[byggesteg.md](generated/byggesteg.md)**. Med bilder:
**[MONTERING.md](MONTERING.md)**. Oversiktstegning:
[schematics/byggerekkefolge.svg](schematics/byggerekkefolge.svg).

**Og før steg 1: bryt kantene.** Det gjøres i steg 0, mens delene ennå er løse
på bukken. Kravet står under.

### Rommet først — før noe kappes

Nisja er ikke et rektangel. Vegger heller, gulv faller, og hjørner er sjelden
90°. Senga skal stå i vater og lodd likevel. Regelen er derfor:

**Senga er referansen, ikke rommet — bygg i vater og lodd, og ta skjevheten i
delene som møter vegg og gulv.**

Det deler kapplista i to, og delingen er en regel i modellen, ikke en
håndskrevet liste: en del som kommer inntil en endevegg, eller som står på
gulvet, får sluttmålet sitt av rommet. De delene står for seg selv i
[kapplista](generated/kappliste.md), med overmålet sitt i egen kolonne. Resten
kappes ferdig på bukken.

To ting må være på plass før kappingen:

* **Spikerslag i veggen.** Senga ligger flatt mot veggen i noen få
  høydebånd, ikke overalt. Sonene er regnet ut av modellen og står i
  [byggesteg](generated/byggesteg.md#før-steg-0--mål-rommet) — i **to
  notasjoner**: over ferdig gulv, og som fortegnstall fra høyderisset (minus
  er under laserlinja, pluss er over). Gulvet er skjevt og risset er ikke, så
  det er den andre kolonnen du setter sonene etter. Legg dem mens
  veggen er åpen — etterpå kommer du ikke til.
* **Et vannrett høyderiss rundt hele nisja.** Alt måles fra risset, aldri fra
  gulvet. Framgangsmåten — loddlinje midt i nisja, rutenett mot hver
  endevegg, minste sum er minste bredde — står samme sted.

Blir minste bredde et annet tall enn det modellen står på, er det ett tall som
skal endres: `WALL_SPAN` i `generate_loftbed.py`. Kjør `mise run build`, og
kapplista, innkjøpslista og nøkkelmålene følger etter.

**De fire hjørnestolpene har null klaring mot endeveggen.** Modellen setter dem
i selve veggplanet, så en bul i veggen har ingen luft å forsvinne i: enten går
den av treet, eller så skyver den hele rammen ut av lodd. Derfor er dette fast
framgangsmåte for hver av de fire, ikke et unntak ved store avvik: sett
stolpen på plass, hold den i lodd, strek opp veggsiden med avstandskloss —
meddrag — og høvle av til stolpen står i lodd inntil veggen. Det er materiale
som fjernes; det legges ingenting på i bredden, og den nominelle dimensjonen i
kapplista står. Stolpene bærer begge behandlingene i
[kapplista](generated/kappliste.md): overmål i bunn og oppstreking av siden.

Kanter som møter vegg eller gulv kappes med lite bakfall. Da er det bare den
synlige kanten som bestemmer fugen.

### Kantbrytning — alle kanter et barn kan nå

**Alle kanter et barn kan nå skal brytes.** Kravet er *brutt kant*, ikke én
bestemt metode: 45° fas eller avrunding (R6,35 eller R9,5), byggerens valg
kant for kant. Skarpkantet høvlet C24 er skarpt nok til å skjære, og det blir
ikke rundere av at noen maler det.

Tre steder er verdt å nevne ved navn:

* **Plateenhetens underside** — styrelektenes nedre kanter og kilelektenes kanter.
  Dette er kanten ingen ser: den sitter under bordplaten, i knehøyde for den
  som sitter ved bordet. Etter X9 er den knehøyden ikke lenger et bilde: platen
  er en pult med 262 mm under seg, og knærne står faktisk der inne. 68 mm
  skarpkantet lekt mot et kne er det eneste stedet i denne sengen der en kant
  treffer noen som ikke ser den komme.
* **Platens egne kanter, alle fire.** Den håndteres hver gang stillingen
  skiftes, og et kappet finérdekke gir flis.
* **Alt man allerede tar på:** stolper, rekkverksbord, trinn og
  stigevangenes kanter.

Verktøy: fres med V-spor eller avrundingsfres for den som har fres. Har du det
ikke, gjør en håndhøvel, en blokkhøvel eller en pussekloss nøyaktig samme
jobb. Det er noen millimeter tre som skal bort, ikke en profil som skal
lages — ingenting her krever fres.

Det er lettest mens delene er løse, altså i steg 0. En kant som bare er
tilgjengelig fra én side etter at delen står i rammen, tar dobbelt så lang tid
og blir halvparten så pen.

**Modellen tegner fortsatt hver del firkantet.** Kantbrytningen er en instruks,
ikke geometri, og den flytter ingen mål: ingen lengde, ingen klaring og ingen
skruerad endrer seg av at en kant er brutt.

### Tre ting du skal kontrollere hele veien

* **Vater.** Den bakre sidevangen først — den er referansen for alt annet. Så
  hver del etter hvert som den går inn. En vange som ikke er i vater tar du ikke
  igjen senere.
* **Vinkel og diagonal.** Mål diagonalene i bakrammen før den reises, og i
  sengeflaten når begge sidevanger står.
* **Veggklaringen.** De gjennomgående delene er med vilje kappet kortere enn
  veggavstanden, slik at de kan svinges inn. Klaringen er liten. Sjekk at ingen
  del blir stående i spenn mot en vegg, og at ingen spile eller skruehode
  stikker ut i veggplanet.

### Forboring — kort regel

* **Bor gjennomgående hull gjennom begge deler samtidig**, med delene tvunget
  sammen. Bores de hver for seg, treffer de ikke.
* **Forbor hver eneste treskrue.** Ingen unntak i bordbærelekta, i
  bordene og i endeved.
* **Ingenting i rammen er boltet.** Hele rammen er skrudd, med forborede
  6 mm treskruer. Se J1, J2, J3 og J8.
* Diameterne står i forboringskolonnen i
  [beslaglista](generated/beslagliste.md).

---

## 4. J — leddene

Antall, skruetype, forboring og hvilken side du driver fra står i
[beslaglista](generated/beslagliste.md). Skrueradenes høyder står i
[nøkkelmål](generated/nokkelmal.md). Her står hva leddet er og hva som er
poenget med det.

### J1 — Endebjelke → hjørnestolpe

Endebjelken støter mot stolpens innside og skrus gjennom bjelken og inn i
stolpen. Skruene går på tvers av fiberretningen i begge deler, ikke inn i
endeved.

**De to skruene er hele festet.** Det står ingen kloss under bjelkeenden — den
sto der til denne runden, og den er tatt bort, fordi en kloss som selv henger i
én skrue gir leddet halvparten så mye stål som bjelkens egne to. Se avsnitt 2
og lasttabellen: 4,0 kN mot en hjørnereaksjon på høyst 1 kN, utnyttelse 0,25.

Skruene står 18 mm fra bjelkens ende og 27 mm fra over- og underkant. Begge er
over minstekravet for en 6 mm skrue, og den som betyr mest her — kantavstanden
i lastretningen — har halvannen gang så mye.

**Hullene er jiggen.** Gjennomgangshullene i bjelken og styrehullene i stolpen
bores i steg 0, gjennom begge deler samtidig. Da har bjelken nøyaktig én høyde
der hullene står over hverandre, og du kan ikke montere den skjevt. Bygger du
alene: klem en list på stolpens innside i høyde med bjelkens underkant, legg
bjelken på den, skru, og ta listen av igjen.

Skruene drives inne fra sengen. Du kommer til dem når som helst, både under
byggingen og når du skal ettertrekke.

### J2 — Fremre sidevange → fremre hjørnestolpe

Vangen ligger flatt mot stolpen. **Skruene drives innenfra og ut:** du står
inne i sengerammen — den er tom, spilene kommer flere steg senere — og skrur
gjennom vangens innside, gjennom vangen og inn i stolpen.

Det er en utseendebeslutning, og den er tatt bevisst. Stolpens forside er en
av de flatene rommet faktisk ser, og der skal det ikke stå skruehoder. Begge
retninger holder målene like godt: 48 mm vange pluss 36 mm stolpe er det
samme stykket tre som 36 pluss 48, og spissen har 4 mm tre bak seg uansett vei
— så det er ikke statikken som velger. Se avsnitt 2.

Vangen bærer ikke i skruene — den ligger på begge endebjelker.

Merk skruelengden: skruen skal **ikke** komme ut på stolpens forside. Bruk
lengden som står i beslaglista, ikke den lengste du har i esken.

### J2-B — Bakre sidevange → bakre hjørnestolpe

Dette leddet er annerledes, og det er meningen. Den bakre stolpen står **i
vangens eget plan** og er kappet slik at den slutter akkurat under vangen.
Vangen **hviler rett på stolpens endeved**. Hjørnereaksjonen går vange → stolpe
→ gulv som ren trelagring, uten et eneste festemiddel i lastens vei.

Festet er derfor bare et bånd som holder de to sammen mot vridning og løft. To
kraftige skruer settes rett ned gjennom vangen i stolpens endeved, mens
bakrammen ennå ligger flatt på gulvet. Forsenk hodene godt — køyespilene skal
ligge flatt over dem.

Et rett beslag over skjøten ville vært det opplagte, og det går ikke: vangen er
dypere enn stolpen, så den står et lite stykke proud av stolpens romside, og en
rett plate ville bare ligget an mot den ene av dem. Skruer ned i endeveden er
svakere i uttrekk enn et beslag, men her holder de bare igjen — lasten står på
tre, og veggfestet sitter i den samme vangen noen centimeter unna.

**Ikke sett noe på veggsiden.** Den flaten skal være helt plan.

### J3 — Stigevange → fremre sidevange

Tre kraftige treskruer gjennom sidevangen og inn i stigevangen. Leddet er
skrudd, ikke boltet — samme mønster som resten av rammen bruker, se J1, J2
og J8. Tre og ikke fire: omlegget er 48 × 98 mm, og fire 6 mm skruer i én rad
ville krevd 108 mm der det er 98. Fire i to par ville krevd 60 mm på tvers der
det er 48.

**Retningen er innenfra og ut**, som J2 og av samme grunn: stigevangens
forside står i sengens front, og der skal det ikke stå skruehoder. Klem stigen
fast mot sidevangen først — du står på den andre siden når du skrur.

Stigevangen står med den tynne siden mot rommet, så skruene treffer den på
midtlinjen med akkurat den kantavstanden en 6 mm skrue skal ha.

Forbor gjennomgående i sidevangen, og forbor i stigevangen også. Skruene sitter
i én loddrett rad, én over og én under vangens midtlinje med den tredje midt
imellom, slik at leddet tar moment.

### J4 — Rungetrinn → stigekloss og stigevange

Trinnet ligger på klossen. Det er **ett** festemiddel i dette leddet, og det er
den kraftige skruen fra utsiden av stigevangen inn i trinnenden. Gjennom
trinnets overside går det ingenting.

Skruen i trinnenden bærer **ingen** vertikal last — den holder bare trinnet på
plass sideveis. Vekten din går rett ned i klossen og videre inn i vangen. Det er
riktig utformet, og det er grunnen til at trinnet ikke kan glippe selv om skruen
i endeveden skulle løsne.

**Her sto det en 5×60 ned gjennom trinnet og inn i klossen, og X10 strøk den —
fordi den ikke kunne eksistere.** Den hadde ingen lovlig plass å stå på: vangens
36 mm dybde låser hvor gjennomgangsskruen i trinnenden kan stå i dybden,
trinnets 48 mm låser hvor den kan stå i høyden, og en skrue som slippes ned fra
trinnets overside må krysse hele trinnet for å nå klossen — altså rett gjennom
6×120-ens egen kanal. Snus den, og drives opp nedenfra, klarerer den 6×120-en
med 12 mm og lander i stedet på J5, som sitter midt i klossens egen høyde og
heller ikke kan flytte seg. Klossen kan ikke ta en loddrett skrue så lenge
trinnet har en vannrett.

**Så jobben er lagt på treet i stedet, og det er en bedre begrunnelse enn den
strøkne skruen var.** Klossen er fanget mellom tre ting: vangeflaten den er
skrudd til, trinnet som ligger på 1296 mm² av oversiden hennes, og at det
trinnet selv er naglet til vangen 48 mm lenger opp av 6×120-en. Skal klossen
rotere om sin ene skrue (J5), må den løfte et trinn som er skrudd fast. Det er
lås av tre, ikke av stål — og det er grunnen til at **hver eneste kloss i denne
stigen har et trinn oppå seg**. X9 hang to klosser på vangene som ikke hadde
det, og måtte kjøpe en skrue nummer to til hver av dem for å erstatte trinnet;
X16 strøk klossene, og med dem den ene delen i sengen som trengte stål fordi
den manglet tre.

Trinnene stikker **bakover**, ikke framover: forkanten ligger i flukt med
stigevangens forkant, og det som blir liggende bak vangeplanet er hylla den løse
platen hviler på. **Den setningen gjelder begge stillinger igjen.** Fra X9 til
X15 gjaldt den bare trinn 1, fordi bordstillingen da hvilte på to påskrudde
bordklosser og ikke på et trinn i det hele tatt; etter X16 lander platens
forkant på **trinn 1** i sengestilling og på **støttetrinnet** i bordstilling —
samme profil, samme hylle, samme ledd, samme 320 mm trinn. På den stigen som
faktisk står, er støttetrinnet **trinn 2** og ikke trinn 3: se X18 nedenfor.

**Klossen følger ikke trinnet bakover.** Den er 36 mm dyp — nøyaktig så dyp som
stigevangen — og står i vangens eget dybdebånd, ikke i trinnets. Klossen har
aldri rørt mer av vangen enn de 36 millimeterne, så de 37 som er kappet vekk
(K1) bar ingenting; de sto derimot rett i veien for den løse platen når den
skal bæres fra det ene setet til det andre. Se J13. Det betyr også at trinnets
bakre 32 mm står **fritt** ved endene: trinnet er 68 mm dypt og vangeplanet tar
de fremste 36, så det er en 48 mm tykk kloss tre som stikker 32 mm ut, ikke et
spenn.

**X18 — STIGEN SOM STÅR HAR FIRE TRINN, OG DET SKAL LESES FØR RESTEN AV DETTE
AVSNITTET.** Byggherren kappet fire: **297, 682, 962 og 1242**. De to nederste
er med vilje platens to stillinger — «trinnene er laget for den opprinnelige
høyden av benk og bord» — og de to øverste er den samme utledningen X2 skrev.
Trinnet på 489 ble tegnet og aldri kappet, og uten det er steget fra trinn 1 opp
på støttetrinnet **385 mm**. Grensen i denne fila er 281 og er ikke rørt; det
bygde steget er 104 mm for langt. **Men veien barna faktisk går, er ikke den:**
de setter foten på **benkekanten** underveis — 297 → benkesetet 420 → 682 — og
da er største virkelige steg **262 mm**, innenfor grensen. Avviket er derfor
**akseptert**, ikke «bør rettes», og hele dommen — begge stillinger målt, EN
747-vurderingen og det femte trinnet som **opsjon** — står i **vedlegg B,
avvik 5**. Alt som følger i dette avsnittet er utledningen slik den var tegnet,
og den er beholdt fordi det er den opsjonen peker tilbake på.

**Stigen er to løp, og X16 flyttet skillet mellom dem opp i et trinn.**
Trinnoverkantene ble tegnet på 297, 489, 682, 962 og 1242, og stigningskjeden fra
gulv til spilebunn er 297 + 192 + 193 + 280 + 280 + 281. Fem trinn som før; det
er ikke antallet som er endret, det er fordelingen. Grunnen står i J13 og i
8.2, og den er snudd på hodet siden X9: **682 er ikke lenger en høyde et trinn
har forbud mot å stå på — det er høyden et trinn skal stå på.** Bordplatens
underside er 682, støttetrinnet er lagt nøyaktig der, og de to løpene **møtes** på
det trinnet. X9 leste den samme høyden som et bånd som måtte holdes tomt og
skjøv trinnene til 297 / 572 / 848 / 1073 / 1298 for å få det til; til og med
v15 sto de på 297 / 542 / 787 / 1032 / 1277, jevnt fordelt.

**Antallet trinn var fortsatt FEM da det ble tegnet, og det skal stå her og
ikke i en fotnote.** Bestillingen var «ta bort et trinn og juster avstanden», og
et trinn ble ikke borte på tegningen — det ble borte i verkstedet, se X18 over. Trinn 1 er naglet til benkevangen på 297, spilebunnen ligger på 1523, og
297 → 682 lar seg ikke gå i ett steg. Det som forsvant, er de **to
bordklossene**. Ved platens forkant sto det tre trebiter i to omfar — et trinn
oppe og et klossepar under — og der står det nå én. Det var de klossene
byggherren så fra gulvet, og det er dem runden tok; trinnet overtok jobben
deres.

Det er verdt å si nøyaktig hva som ble gitt opp og hva som ikke ble det.
**Stigningsgrensen ble hevet med én millimeter, og den ble hevet i åpent
lende.** Det øvre løpet er 841 mm i tre steg, og 841 = 3 × 280 + 1, så største
klatretrinn er 281 mm der fila før sa 280. De fem klatretrinnene ligger på 192,
193, 280, 280 og 281 — det er **det** tallet EN 131s bånd 250–300 gjelder for i
denne fila, og 281 ligger godt inne i båndet; 280 var husets egen avrunding av
det, ikke normens tall. Det fantes nøyaktig ett alternativ: legge støttetrinnet
på 683 i stedet for 682. Da går det øvre løpet opp i tre like steg og grensen
står — men bordplaten går til 701, bordbærelekta til 615–683 og
**spikerslagsone 3 én millimeter oppover en vegg byggherren spikrer denne
uka**. Veggen er ikke forhandlingsbar, og en fot finner ikke én millimeter på
et 280 mm steg. Det ble sagt nei til dette i åpent lende, med tallet skrevet
ned ved siden av.

Å ta et kortere steg enn normen legger opp til er ikke en fare, det er bare
tettere trinn; det er den *lange* stigningen grensen vokter. Det som ble gitt
opp er *jevnheten*, som X1/X2 selv skrev ned som en utseendebeslutning — og den
er ikke slakket, den er **delt**: inne i hvert av de to løpene er stigen jevn
til 1 mm, og den grensen (2) er urørt. Forskjellen **mellom** løpene er derimot
89 mm mot en egen grense på 90, der X9 sto på 51 mot 60. Spriket er ingen
overraskelse, det er regnestykket: det nedre løpet har 385 mm å klatre i stedet
for 551, i de samme to stegene. Nede er det to grunne steg opp til pulten, oppe
er det en ordentlig stige — og det er nettopp det denne sengen er.

Det som skiller de to løpene er ikke lenger et forbudt bånd, det er et påbudt
punkt. Løftesjakten står igjen som betingelse **over** støttetrinnet — ingen
*annen* trinnoverkant får ligge i båndet 614..848 — men trinnet platen hviler
på er selve gulvet i det løftet og er unntatt fra sitt eget forbud. Ut over det
er stigen den samme utledningen X2 skrev, bare gjort to ganger: færrest trinn,
så jevnest, i hvert løp for seg. Flytter platen seg igjen, følger støttetrinnet
den og hele stigen regnes om; ingen setter et trinn for hånd.

**Og prisen ble betalt et annet sted, av trinn 2 — på tegningen.** Det nedre
løpet falt med støttetrinnet, så trinn 2 gikk fra 572 til 489, og underkanten
sto 21 mm over den nedre soveflaten der den før sto 104. Det var ikke takhøyde
lenger, det var en **spalte** — og 21 mm ligger inne i EN 747-båndet 12–25 mm,
der et lem passerer fritt og ingenting kiler seg.

**X18 gjorde den prisen om intet, for trinnet finnes ikke.** Det laveste som
står over den nedre soveflaten er bordbærelekta på 194 mm, og transportsjakten
over benken — den platen bæres gjennom når den bytter stilling — gikk fra
121 til **294 mm**. Plateenheten er 86 mm høy, så den passerer med 208 mm i
stedet for 35. Det er den ene tingen i hele X18 som ble bedre uten at noen
betalte for den. Se 5 og 7.

Første steget, de 297 fra gulvet opp på benkevangen, er fortsatt en avsats du
trår opp på og ikke et klatretrinn — og trinn 1 står fortsatt på 297 og bærer
fortsatt sengemodus-platen. Både X9 og X16 rørte stigen **over** trinn 1 og
ingenting annet.

**Hullene i vangen, målt fra vangetoppen — les dette før du borer.** Stigevangen
kappes med overmål og finkappes i **bunnen**, så toppen er den enden som ligger
fast, og det er den alle hull måles fra. Hullsenteret ligger midt i trinnets
høyde, altså 24 mm under trinnets overkant.

| Trinn | Overkant over gulv | J4 ⌀6 fra vangetoppen |
|---:|---:|---:|
| 1 | 297 mm | **1598 mm** |
| 2 (støttetrinnet) | 682 mm | **1213 mm** |
| 3 | 962 mm | **933 mm** |
| 4 | 1242 mm | **653 mm** |

**Begge kolonnene flyttet seg i X18, og av to uavhengige grunner.** Trinnet på
489 ble aldri kappet, så raden er borte; og stigevangen er kappet ved 1871 og
ikke ved 2037, så *alle* de gjenværende målene fra vangetoppen er 166 mm
kortere enn på det forrige arket. Gammel → ny, rad for rad:

| Overkant | X16-ark (vangetopp 2037) | X18-ark (vangetopp 1871) |
|---:|---:|---:|
| 297 mm (før) | 1764 mm | **1598 mm** |
| 489 mm (før) | 1572 mm | *trinnet finnes ikke* |
| 682 mm (før) | 1379 mm | **1213 mm** |
| 962 mm (før) | 1099 mm | **933 mm** |
| 1242 mm (før) | 819 mm | **653 mm** |

Stigeklossens hull (J5, ⌀3 i vangen) trenger ikke sin egen kolonne: klossen står
rett under trinnet sitt og er like høy, så J5-hullet ligger **48 mm lenger ned
fra vangetoppen** enn J4-hullet i samme rad — klosshøyden, hver gang.

**Bare trinn 1 står der det sto.** Etter X9-arket lå de fire andre J4-hullene på
[var 1489, 1213, 988 og 763 mm fra vangetoppen], og de to bordklossene hadde
hvert sitt hullpar [var 1377 og 1401]. Har du boret etter det arket, står fire
hull tomme og ett av bordklosshullene 2 mm fra det nye støttetrinnets — se det
strøkne J5-B-avsnittet under for hvordan det plugges.

### J5 — Stigekloss → stigevange

Én skrue per kloss, inn i vangens innside. Klossen dekker bare 36 × 48 mm av
stigevangen, og to 5 mm skruer trenger 50 mm av de 48. Klosshøyden er
trinnhøyden. Mål to ganger.

**K1 endret ingenting i dette leddet.** Klossen ble kappet 73 → 36 mm, men de
36 × 48 millimeterne mot vangen er de samme — det var alt klossen noen gang
rørte, siden vangen bare er 36 mm dyp. Det ene som ble bedre er hvor skruen
lander: før satt den på Y 751,5, altså en halv millimeter **utenfor** vangens
bakplan, fordi den ble sentrert i en 73 mm lang kloss. Nå sitter den på Y 770,
midt i vangen.

Klossen er ikke overlatt til den ene skruen — men det som holder den er
**tre**, ikke en skrue til. Trinnet ligger på 1296 mm² av klossens overside, og
trinnenden er skrudd til stigevangen med en 6×120 gjennom vangen, 48 mm over
klossens egen skrue — begge sitter midt i sin egen deltykkelse, og delene er
48 mm høye hver. De to festene deler samme hjørne, og skal klossen rotere om
skruen sin, må den løfte et trinn som er naglet fast. X10 strøk den loddrette
5×60-en ned gjennom trinnet som sto her før — se J4 for hvorfor den ikke kunne
stå noe sted.

### J5-B — Bordkloss → stigevange *(STRØKET i X16)*

**Dette leddet finnes ikke lenger. Bygger du etter et ark fra før X16, er det
her arket er feil.** X9 la bordplaten på 700 ved å erklære 682 for en høyde
ingen trinn fikk stå i — platen skal løftes gjennom det båndet — og måtte så gi
forkanten et opplegg likevel. Det ble to bordklosser: 48×68 på høykant, én på
hver stigevanges innerflate, med to 6×80 hver. To trebiter som gjorde et trinns
jobb, i en stige som allerede kan lage en avsats i akkurat den høyden. **X16 snudde betingelsen:** 682 er høyden et trinn *skal* stå på,
støttetrinnet ligger der, og klossene er strøket sammen med sine fire skruer.

*Hva som forsvant med dem, kort: to deler av 48×68 [var 91 mm lange], fire
Treskruer 6×80, ett ledd i beslaglista, én rad i skrueretningene og
to rader i lastbanen — deriblant den ene skrueraden i hele sengen som hadde
lasten stående foran sin egen skruelinje [var 0,55 utnyttet]. Bæreflaten under
platens forkant gikk fra klossenes 5088 mm² til trinnets 9600 mm², og hylla er
igjen den samme hylla som i sengestilling.*

**Har du alt boret etter det gamle arket?** Klossenes to ⌀6 sto i stigevangens
utside [var 1377 og 1401 mm fra vangetoppen]. Det nye J4-hullet for
støttetrinnet står **1213 mm** fra den X18-kappede vangetoppen; på det arket
klossene ble boret etter sto det 1379 mm fra en vangetopp på 2037, altså 2 mm
fra det øverste av dem. Bor du det nye hullet uten videre, vandrer boret ned i det gamle og du får
et ovalt hull rundt en gjennomgående 6×120. Plugg det gamle hullet med limt
rundstokk og la limet herde før du borer det nye. Hele hulltabellen står i J4.

### J6 — Køyespile → sidevange

Spilene ligger **oppå** begge vanger, ikke i et spor og ikke på en lekt. Én skrue
ned i hver vange per spile. Forsenk hodet under flaten — det ligger madrass over.

Alle 14 køyespilene er nøyaktig like lange — 800 mm, samme stykke som
benkespilen. Den første ligger på X 20 og den siste på X 1970; delingen står i
[nøkkelmål](generated/nokkelmal.md).

### J7 og J21 — Rekkverksbord og avstivere

Rekkverksbordene ligger på **innsiden** av stolpene og stigevangene, mot sengen.
Skruene drives fra sengesiden. Bordene stopper i flukt med stigevangenes
innside, slik at klatreåpningen fortsetter rett opp forbi rekkverket. Man
klatrer **gjennom**, ikke over.

**X18 flyttet begge bånd, og de er målt fra SPILENE.** Byggherrens to mål er
130 mm fra spiletoppen opp til det nederste bordets underkant, og 120 mm fra
det bordets overkant opp til det øverste. Begge stemmer samtidig: nedre bord
ligger på **1653–1751** og øvre på **1871–1969**, med 68 mm bar stolpe over.
Det som følger av det:

* **åpningen under det nederste bordet er 10 mm.** Bordet ligger like over
  madrassen og dekker forkanten dens — det er en *lukket* åpning, ikke et
  klemvindu, og vedlegg B, avvik 6, er lukket med den. (Den første runden av
  X18 leste de 130 fra madrasstoppen i stedet for fra spilene og fikk 130 mm
  åpning ut av det. Det var ikke byggherrens tommestokk, det var
  koordinatorens datum.)
* **båndet mellom bordene er 120 mm, og 120 er over grensen 75 alene.** Det er
  avstiverraden som gjør det lovlig: fire avstivere per felt deler de 689
  millimeterne i luker på **59,4 mm**. Raden er ikke pynt, og den er ikke bare
  et opphengspunkt for det øverste bordet — den er selve klemdommen for det
  båndet.
* åpningen over det øverste bordet er **68 mm** mot grensen 75. Det er den
  samme åpningen vedlegg B, avvik 0, ble skrevet om da den var 58, og
  argumentet der dekker den fortsatt: ingen annen del i sengen står i det
  høydebåndet, så åpningen er ikke engang delvis omsluttet.
* barrieren står **326 mm** over madrassen mot EN 747s krav på 160.

**Og det er bare seks omlegg igjen, ikke åtte.** Stigevangene er kappet ved
1871, altså i flukt med det **øverste** bordets underkant, så det øverste
bordet har ingen vange å skrus i ved den indre enden — vangen slutter nøyaktig
der bordet begynner. Det bæres av avstiverraden, og det er vedlegg B, avvik 7.

**J21 — avstiverne.** Fire per felt av bunnspilevirket, 23×98 × 180 mm, lagt på
tvers over de to bordene i sporet mellom bordet og stolpeplanet, med 30 mm
omlegg på hvert bord. De 30 millimeterne er ikke valgt: en 5 mm skrue skal stå
3d fra avstiverens egen kappende og 3d fra bordets kant, altså 6d = 30 mm, og
180 = 120 + 30 + 30. Antallet er heller ikke valgt: tre avstivere i et 689 mm
felt gir 98,75 mm luker og faller på grensen, fire gir **59,4 mm** og holder.
Antallet settes av feltet og grensen, ikke av båndhøyden, så det er de samme
fire som før — det er bare lengden som fulgte båndet.
To 5×40 i hvert omlegg, drevet fra rommet.

**Dette er det ene stedet i sengen der stål synes på forsiden**, og det er
skrevet ned som det: 32 hoder på fronten. Den andre veien går ikke — en 5 mm
skrue som skulle krysse 36 mm bord ville komme ut av baksiden på en 23 mm
avstiver. Regelen i modellen er ikke slettet, den har fått ett navngitt unntak,
så begynner et *annet* ledd å synes på fronten, stopper bygget.

Det er ikke rekkverk på baksiden. Se sikkerhetsavsnittet.

### J8 og J8-B — Benkevange → hjørnestolpe

To ulike ledd, ett foran og ett bak.

**J8, foran — og X18 gjorde det til det samme leddet som J8-B.** Slik det var
tegnet lå vangebiten flatt mot stolpens innside med 95 mm omlegg, og de to
6×80 gikk rett gjennom det omlegget. Som bygget står vangen **buttet** mot
stolpens X-innside, i stolpenes eget plan, med forkanten i flukt med
stolpeforsiden — og et buttet ledd har ikke noe omlegg å skru gjennom.

Det er ikke et valg byggherren tok for utseendets skyld, og modellen fant det
ut på den harde måten: en vange som blir stående i sitt eget plan (Y 704..752)
og stoppes ved stolpens innside deler **en kant** med stolpen og ingenting
annet. Det finnes ingen flate der en skrue av noe slag kan krysse. Det eneste
planet der byggherrens setning i det hele tatt *er* et ledd, er stolpenes eget:
36 × 68 mm buttflate, som er stolpens egen dybde ganger vangens egen høyde.

Festet er derfor **lommeskruer**, og det er leddet dette huset allerede eide:
samme 65°, samme 20 mm sete, samme ⌀18 forstner og **samme vinkelkloss som
J8-B**. Ett 1:1-mønster tjener nå J8, J8-B og J12. Skruene drives fra vangens
innside — inne fra benkerommet, mens benken ennå er åpen — så stolpens forside
står uten skruehoder som før.

De to skruene er hele endefestet: 4,0 kN i skjær mot en endereaksjon på
0,5 kN. Det sto en bærekloss under denne enden til v12; se avsnitt 2 for
hvorfor den er borte.

**Og de 36 millimeterne vangen flyttet seg fram, koster noe.** Benkespilene er
800 mm og slutter på Y 752, så en vange på 740..788 gir dem 12 mm å ligge på
der de før hadde 48 — og 12 mm tar ikke kantavstanden til den 5 mm skruen som
holder en spileende nede. Det er **benkespileleddet** som lukker det, og det er
den ene halvdelen av byggherrens «ekstra støtter»: en 36×48 × 547 mm list
skrudd på vangens innside med overkanten i flukt med vangens, fire 5×60 per
benk satt i mellomrommene mellom spilene så ingen spileskrue kommer ned på en
av dem (J19). Da ligger spileenden på ledd og vange i ett plan, 48 mm bredt,
akkurat som før.

**J8-B, bak:** den bakre benkevangen går fra stolpe til stolpe og støter mot
stolpens sideflate med enden. Her går skruene **skrått** fra vangens forside inn
i stolpen. Forbor hele veien — en skråskrue nær en ende er den letteste måten å
sprekke en vange på.

**Hver skråskrue får et sete, og setet bores først.** Et 90° forsenk som møter
flaten i 25–30° kan ikke ligge i plan, og har aldri kunnet det. Det som ligger i
plan er et **flatbunnet sete boret langs skruens egen akse**: ⌀18 forstner.
Bunnen står vinkelrett på skruen, og dermed vinkelrett på hodet, så hodet legger
seg flatt og ender **helt under treet**. Alt om setene er tegnet opp på
[schematics/setedetalj.svg](schematics/setedetalj.svg) — snitt langs aksen,
munningen ovenfra, borjiggen og bruken av den.

**Dybden er 20 mm på J8-B og 18 mm på J10, og forskjellen har en grunn.** Et
forsenket hode i en flat bunn har to steder å lande. Det ene er bunnen. Det
andre er **kanten av forborhullet**: konusen går fra ⌀11,8 ned til ⌀6, og står
den på den kanten i stedet, ligger hodet 2,9 mm høyere enn tegningen sier. På en
skrue som står 25° på flaten spiser de 2,9 mm 1,23 mm av tredekket. Med 18 mm
sete ble regnestykket på J8-B:

| | hodet på bunnen | konusen på forborkanten |
|---|---:|---:|
| J8-B, 18 mm (før) | 2,26 mm | **1,03 mm** |
| J8-B, 20 mm (nå) | 3,11 mm | 1,88 mm |
| J10, 18 mm | 4,89 mm | 3,76 mm |

Kravet er 1,0 mm. En margin som forutsetter at skruen finner bunnen av sin egen
lomme er ingen margin, så J8-B er boret 2 mm dypere. J10 er ikke i nærheten og
står uendret. Alle tallene er målt på kroppene i modellen, og begge tilfellene
— hodet på bunnen og konusen på kanten — er egne asserter nå.

De 2 mm koster to ting og ingen av dem gjør vondt. Lommebunnen flytter seg
1,8 mm nærmere endeveden — men munningens egen nærmeste kant flytter seg ikke,
så det er bare hvem av dem som er nærmest som bytter plass. **X18 la 6 mm på
begge:** setet starter 40 mm fra enden i stedet for 34, fordi alle tre
skråskrueleddene i sengen nå bruker det samme runde tallet. Lommebunnen står
18,1 mm fra endeveden og munningens nærmeste kant 18,7. Og 20 mm av skruen går med i
lomma i stedet for 18, så J8-Bs 6×80 begraver 60 mm gjenger og J10s 5×60
begraver 42. Begge er kjørt gjennom de vanlige spiss-inne- og
spissdekningsasertene på nytt.

**Og treet MELLOM de to lommene er målt nå.** De to skråskruene i hver ende står
24 mm fra hverandre, som er rekkeregelen for en 6 mm skrue, men rekkeregelen
måler skruen og ikke hullet den ligger i: to ⌀18-lommer på 24 mm senteravstand
har 6 mm tre imellom. Det er nok her, og gulvet er skrevet ned til én
skruediameter slik at en senere endring ikke spiser det ubemerket.

**Vinkelklossen — borjiggen. To klosser, én per vinkel.** Et skrått hull startet
på frihånd vandrer, og det vandrer verst akkurat her: nær en ende, i en flate som
boret møter på skrå. Jiggen er derfor ikke en rampe boret hviler *på*, men et
hull det går *ned i*. Hver kloss er to biter av sengens egen 48×68, 200 mm
lange, skrudd flate mot flate. **⌀18 bores vinkelrett gjennom begge mens klossen
ennå er firkantet** — det er hele trikset — og først deretter kappes sålen av
under hullet på kappsag med bladet vippet **25° (J8-B)** hhv. **30° (J10)**.

Merk deg at vippen og flaten er komplementvinkler: 25° vipp gir en såle som står
**65°** på den borede flaten, og dermed 25° på hullaksen. Det er den vinkelen
leddet er regnet på. Kontrollmålet er munningen hullet etterlater i den ferdige
sålen — en ellipse på **42,6 × 18 mm** på 25°-klossen og **36 × 18 mm** på
30°-klossen. Mål den med tommestokken før klossen får røre sengen; er den for
kort, ble vippen satt på feil vinkel.

I bruk: klemt mot flaten med to tvinger, hullet over merket, offerkloss mot
endeveden, drill i gir 1 med slaget av. Både forstnerboret og forboret etterpå
går ned i det samme hullet. Klossene lages i steg 0 og er verkstedhjelpemidler,
ikke deler av sengen — de skal ikke bygges inn noe sted, og de går av restene
på 48×68-bordet.

I begge tilfeller er de to skruene hele endefestet. Det står ingen kloss under
noen av dem — de to skruene i hver ende tar reaksjonen i skjær med utnyttelse
0,13, og hullene fra steg 0 holder vangen i riktig høyde mens du skrur. Legg
gjerne en list eller en tvinge under enden hvis du er alene.

Vangen vipper ikke av at klossen er borte: den er festet i to punkter i hver
ende, over 68 mm høyde, og den andre enden står på en stubbefot.

### J10 — Benkevange → stubbefot

Foten står under vangen med hele endeflaten mot gulvet og hele toppflaten mot
vangen.

**X18: beslaget er ute, og det er to skruer i stedet — «ovenfra og fra
siden», som byggherren gjorde det.** Slik det var tegnet satt et vinkelbeslag i
hjørnet mellom fotens ytterside og vangens underside, med to skruer i hver
flik. Fire av de seks beslagene i sengen sto her. Som bygget står det i stedet:

* **Én 6×120 rett ovenfra**, ned gjennom vangens overkant og 52 mm inn i
  fotens endeved. Hodet forsenkes i vangens overkant, der benkespilene siden
  legger seg over det, så det synes ikke og det er ikke i veien.
* **Én 5×60 skråskrue fra siden**, nedenfra opp gjennom foten og inn i vangen,
  fra den fotsiden som vender inn mot benkeåpningen.

Én skråskrue og ikke to: foten er 48 mm dyp — like dyp som vangen den bærer —
og to 5 mm skråskruer ved siden av hverandre trenger 50. De to skruene måtte
skilles inne i vangen: den loddrette står 6 mm ut fra fotens senterlinje og
skråskruens sete 9 mm den andre veien, så aksene passerer 15 mm fra hverandre
der regelen krever 10,5.

*Hva det koster, sagt rett ut:* beslaget bandt foten til vangen i **strekk** i
to retninger. Endeved holder dårligere i uttrekk enn en flik gjør, og de to
skruene her er derfor ikke det samme leddet. Det de faktisk skal gjøre, er å
holde foten på plass — lasten står i **trykk** rett gjennom foten til gulvet,
og den går ikke gjennom noe feste i det hele tatt. Se vedlegg A.

Skråskruen får **samme slags sete som J8-B**: ⌀18 forstner, 18 mm langs skruens
egen akse, boret med 30°-vinkelklossen. Hodet ligger flatt i en flat bunn og
står 4,89 mm under treet — 3,76 mm selv om konusen skulle stå på kanten av
forborhullet. Setet spiser 18 mm av lengden, så 5×60-skruen begraver 42 mm.
J10 er ikke i nærheten av grensen og er derfor ikke boret dypere slik J8-B er.
Se J8-B for hele detaljen og
[schematics/setedetalj.svg](schematics/setedetalj.svg) for tegningen; de står
bare ett sted.

De **fremre** føttene står akkurat der vangebiten slutter. Vangebiten skal ikke
stikke ut forbi foten i det hele tatt — den ender på den.

### J11 og J11-F — Benkespile → benkevange og benkespileledd

Én skrue i hver ende, ned i treet under. Forsenk. Dette er en sitteflate.

**Bak (J11) går skruen i den bakre benkevangen som før. Foran (J11-F) går den i
LEDDET, ikke i vangen** — X18 flyttet vangen 36 mm fram, og det er 12 mm av den
igjen under spileenden. Se J8. Leddets overkant ligger i flukt med vangens, så
spilen ligger i ett plan uansett hvilken av de to den er skrudd i; det er bare
skruen som har flyttet seg innover.

### J11-E, J16 og J17 — endespilen og endelisten

De tre leddene helt ute ved veggen. De finnes fordi soveflaten nede skal være
like lang som overkøyen, og fordi den bakre hjørnestolpen står i veien for en
vanlig benkespile der.

**J17 — endelist → bakre hjørnestolpe.** Listen er 36×48 × 98 mm og skrus
**flatt på stolpens forside**, med overkanten i flukt med benkevangens overkant
(297 mm over gulvet). To 5×60 ved siden av hverandre langs listen. Regn på
skruelengden før du bytter den ut: 36 mm går gjennom listen og 24 mm inn i en
stolpe som er 36 mm tykk, så det står 12 mm igjen til baksiden — og baksiden av
den stolpen **er veggflaten**. En 6×80 går tvers igjennom. Dette er det eneste
leddet i sengen som går inn i den bakre stolpens forside; flaten er 98 × 1402 mm
og helt ubrukt ellers.

**J16 — endespile → bakre endelist** og **J11-E — endespile → FREMRE
endelist.** Én 5×60 ned i hver ende, akkurat som J11. Endespilen er 764 mm og
ikke 800: den starter på stolpens forside. Legg den helt inntil naboen —
spalten der skal være null, ikke «omtrent null».

**X18 ga endespilen en fremre endelist også, og den er speilbildet av J17.**
Den bygde benkevangen begynner først ved den fremre stolpens innside, så den
rekker ikke lenger ut under endespilen i det hele tatt — spilens forende hadde
ingenting igjen å ligge på. Den fremre endelisten er samme del som den bakre,
36×48 × 98 mm, skrudd **flatt på den fremre hjørnestolpens bakside** med
overkanten i flukt med benkevangens overkant, to 5×60 (J20). Skruene står 8 mm
under flatens midte, av samme grunn som J17 står 8 mm under sin: J8s to
lommeskruer kommer gjennom den samme stolpen 24 mm fra hverandre, og raden skal
stå midt mellom dem og ikke oppå den ene.

Begge lister henger i sine to skruer, uten kloss under, akkurat som J1, J8 og
J8-B. Lasttallet står i vedlegg A.

### J12 — Bordbærelekt → bakre hjørnestolpe

Lekta går fra stolpe til stolpe og støter mot stolpenes sideflater med endene,
akkurat som den bakre benkevangen. Men den bærer et bord, ikke bare seg selv,
og den skal kunne belastes rett ned uten å hvile på skruer i uttrekk. Slik det
var tegnet fikk hver ende et lite vinkelbeslag å hvile på, med den vannrette
fliken under lektas ende.

**X18: begge beslagene er ute, og leddet er blitt J8-B én etasje opp.** Lekta
har samme profil som den bakre benkevangen, den støter mot den samme flaten på
den samme stolpen, og den nås fra den samme siden — så den får det samme
festet: **to 6×80 skråskruer ut av flatbunnede ⌀18-seter i lektas forside**,
boret med den samme 25°-vinkelklossen, 24 mm fra hverandre i høyden. Ingen ny
vinkel, ingen ny jigg, ingen ny skrue.

*Det beslaget faktisk gjorde, og hva som gjør det nå:* den vannrette fliken var
**hylla lekta hvilte på mens den ble skrudd**. Hullparet er den hylla nå — et
forboret hullbilde passer i én eneste stilling, så lekta kan ikke skli ned mens
du står med drillen. Og lasten: de to skråskruene tar endereaksjonen i skjær,
akkurat som J8-Bs to gjør en meter lenger ned, med den samme utnyttelsen.

Lekta står **på høykant**. Legger du den flatt, ender overkanten 20 mm for
lavt, og platen når ikke det bakre opplegget sitt i bordstilling. Forbor.

Lekta må inn mens bakrammen ligger flat, av samme grunn som benkevangen: den er
kappet til å fylle nøyaktig mellom stolpene.

Lekta er det bakre opplegget for platen i bordstilling, og overkanten skal ligge
i nøyaktig samme høyde som **støttetrinnet** på stigen — trinn 2 på den bygde
stigen (trinn 3 på det gamle arket), overkant 682.
Da ligger platen rett på begge to, uten beslag og uten kile. *(X9 hadde to
bordklosser her i stedet for et trinn; X16 strøk dem — se J4.)*

**X9 flyttet den 140 mm opp, og ingenting annet ved den.** Samme del, samme
lengde, samme ledd — den skrus bare høyere: underkanten
gikk fra 474 til **614** og overkanten fra 542 til **682**, som er bordplatens
nye underside. Det er den lette halvdelen av pulten; den vanskelige sto ved
stigen, og X16 løste den ved å legge et trinn i den høyden i stedet for å henge
klosser under den. **Spikerslagsonen følger med:** sone 3 i veggen ligger nå
på 614–682 over ferdig gulv, altså −386..−318 fra høyderisset. Legger du
spikerslaget etter et gammelt ark, treffer skruene 140 mm for lavt. Sonene står
i [byggesteg](generated/byggesteg.md#før-steg-0--mål-rommet).

**X11 ga lekta et veggfeste også — J12-V, tre skruer inn i stenderne.** Sone 3
lå i veggen for lektas skyld, men fikk aldri en skrue: hele det bakre
opplegget for bordplaten hang i de to endefestene, med 1794 mm
fritt imellom. Nå går tre ⌀8 rett gjennom lekta og inn i veggen, midt i lektas
høyde, og spennvidden blir tre korte i stedet for én lang. Se J12-V nedenfor
for hvorfor det ikke rører noe av det som står over: endene bærer fortsatt seg
selv — nå i lommeskruene sine i stedet for i beslag — skruen ligger vannrett og
tar last i skjær, ikke i uttrekk, og hodene forsenkes i lektas **forside**, så
veggplanet er like flatt som før.

### J13 — Den løse platen

Platen er ikke et løst bord. Den er en liten enhet som **senkes rett ned** i den
stillingen den skal stå i, og løftes rett opp igjen. Alt annet i dette avsnittet
følger av den ene setningen: platen har null vandring i dybderetningen —
bakkanten *er* veggplanet og forkanten står 2 mm fra stigevangene — så den
eneste bevegelsen den har, er loddrett. Det gjelder platen **i setet**. Selve
byttet mellom de to setene er en annen sak, og den står nederst i avsnittet.

Vekten hviler på **tre**, ikke på stål: bakkanten på den bakre benkevangen
(sengestilling) eller på bordbærelekta (bordstilling), forkanten på **trinn 1**
i sengestilling og på **støttetrinnet** i bordstilling. Det er samme profil, samme
hylle og samme ledd i begge stillinger, og etter X16 er de to opplegglinjene
like store til millimeteren: 37 152 mm² totalt begge veier. *(Fra X9 til X15 sto
det to påskrudde bordklosser under forkanten i bordstilling, fordi pulthøyden da
var erklært forbudt for et trinn. Se det strøkne J5-B.)*

**Og regelen om bæreflate står, selv om grunnen til å skrive den om er borte.**
Modellens minstekrav på 5000 mm² gjaldt «per navngitt opplegg» så lenge hver
bærelinje var én del; X9 gjorde forkanten til to klosser, og da ble kravet
skrevet om til å gjelde **per bærelinje** — forkant og bakkant, hver for seg,
uansett hvor mange biter linja består av. X16 gjorde linja til én bit igjen, men
regelen blir stående i den generelle formen: den er riktigere, og den koster
ingenting. Verdien er den samme 5000, ingenting er unntatt, og trinnet gir
320 × 30 = **9600 mm²** der de to klossene ga 5088.

**Og styringen er også tre.** Det står ikke ett vinkelbeslag i denne
mekanismen — den jobben gjør de to lange lektene — og det står ingen lås i den
(vedlegg B, avvik 4). Ikke én ståldel.

**J13a — avstivningslekter, som også er styrelekter.** To 48×68-lekter på
høykant under platen, fra det bakre opplegget og helt fram til platens egen
forkant (750 mm). To ting på én gang:

* **de gjør platen stiv.** Uten dem holder ikke den 18 mm plata når noen setter
  seg på den; med dem er platen to T-bjelker. Se lasttabellen i vedlegg A.
* **de er hele sidestyringen.** De ligger 77 mm inn fra hver sidekant, som er
  nøyaktig **2 mm utenfor trinnenden**. De siste 30 mm av hver lekt står i den
  frie sjakten ved siden av trinnet — 48 mm høy og 32 mm dyp, den biten av
  trinnet som stikker bak stigevangen — så det er 48 × 30 mm tre mot endeved
  som stopper platen sidelengs, ikke en 2 mm stålflik.

**Og i bordstilling er det en trinnende som styrer, i nøyaktig det samme
planet.** Det er hele poenget med X16: samme profil, samme plan, samme passing.
Styrelekta møter 48 × 30 mm endeved mot trinn 1 nede og mot støttetrinnet oppe, med de
samme 2 millimeterne begge steder. *(Fra X9 til X15 sto det to bordklosser her i
stedet — samme ytterflater på X 835 og 1155, men 68 mm høye og med 53 mm omlegg
i dybden. Da var sjakten romsligere oppe enn nede; nå er de like.)*

Trinn 1 og støttetrinnet ender på nøyaktig samme sted i lengderetningen, så det
samme lektparet finner opplegget sitt i **begge** stillinger. De stopper platen
begge veier (den ene mot venstre, den andre mot høyre), og de stopper den i
å vri seg, fordi en vridning drar begge to samme vei — den ene kiler seg
uansett hvilken vei den vris. De 2 millimeterne er ikke slark: det er passingen
som gjør at platen kan senkes ned i det hele tatt.

**J13b — kilelektene under forkanten.** Trinnet er 320 mm langt og platen 574
bred, så 77 mm av forkanten utenfor hver styrelekt har ingenting under seg. To
korte kilelekter i flukt med forkanten bærer det hjørnet innover til
styrelekta.

**Hvorfor de finnes, og det er uendret:** dette er hjørnet et barn kneler på når
det klatrer opp fra benken, og det blir **ikke** bedre av at lektene flyttes
nærmere. En punktlast på et fritt platehjørne gir σ = 6P/t² = 18,5 MPa i 18 mm
plate uansett hvor nær nærmeste lekt står. Bare tre under hjørnet hjelper. Se
vedlegg A.

**Men de er kiler nå, ikke klosser.** Hver vinge er full 68 mm dyp ved **roten**,
der den støter mot styrelekta, og skråkappet i ett rett sagsnitt ned til **27 mm**
ved **spissen**, ute på platens egen ytterkant. Det lave ytterhjørnet — hele det
du så nedenfra — er borte, og det som står igjen følger momentet: en utkraging
har momentet sitt ved roten og ingenting ved spissen.

**Og kilen har TO skruer, ikke tre.** Det er K2 som gjorde det nødvendig, og
det er verdt å skjønne hvorfor, for det er ikke skruen som er problemet — det er
hullet den sitter i. Passer-på-flaten-regelen (`(n−1)·4d + 2·3d`) måler
**skaftet**: tre 5 mm skruer trenger 20 mm mellom seg og får plass på 77 mm. Men
hver av dem sitter i bunnen av et **⌀12 kontrabor**, og tre 12 mm hull med 20 mm
senteravstand står igjen med 8 mm tre imellom. På vingen slik den var før K2
(var 116 mm lang) kom det aldri opp, fordi raden hadde 35,5 mm å spre seg på; på 77 mm faller den ned
på 4d-minimum og hullene møtes nesten. To skruer åpner den til 32 mm — 20 mm
tre — og lastsiden merker det ikke: oppskruene er tvinger for en limfuge, og
hele gruppa lå under 0,05. Modellen asserter det nå: **et kontrabor har sin egen
senteravstand, 24 mm, uavhengig av hva skaftet trenger.**

**27 er ikke et tall noen likte.** Det er oppskruens eget sete. Hver J13-skrue
har hodet 27 mm under platens underside — det er nøyaktig det «⌀12 kontrabor
41 mm opp i en 68 mm lekt» betyr — så vingen må være minst så dyp overalt der en
skrue går gjennom den. På akkurat 27 er kontraboret gått i null, og hodet ligger
i flukt med kilens egen underside. Boreregelen er derfor **den samme for alle
fire delene** og leses slik: *bor ⌀12 opp til det står 27 mm igjen.* I styrelekta
er det de 41 millimeterne; i kilen er det 29 og 12 mm ved de to hullene,
dypest ved roten.

**Tallene.** Kilen er 175 560 mm³ mot 251 328 for den hele klossen — 30 % mindre
tre, og hele det lave ytterhjørnet vekk. Det verste bøyesnittet er **ikke**
roten: når h(x) smalner mot spissen, topper σ seg 51 mm fra spissen, der
h = 54 mm — nøyaktig to ganger spisshøyden. Der er den 2,17 MPa mot
f<sub>m,d</sub> = 16,6 for C24, altså utnyttelse **0,13**; roten selv ligger på
2,08 MPa og 0,13. Skjæret sitter i den
andre enden: i 27 mm-spissen er τ = 1,73 MPa mot f<sub>v,d</sub> = 2,77 (med
sprekkfaktoren k<sub>cr</sub> = 0,67), altså **0,62**. Det er det høyeste tallet på delen, og det er det tallet som sier at
spissen ikke skal bli tynnere. *K2 gjorde kilen kortere (116 → 77 mm) da platen
ble smalere, og bøyningen falt med den; skjæret i spissen er uendret, og det er
fortsatt det som styrer.*

*Den elegante løsningen tapte på et tall:* **18 mm kryssfinér-doblere** limt
under hvert forkanthjørne — ingenting som henger ned, usynlig, og
innsettingsveien merker dem ikke engang. Med **fullt samvirke** over limfugen er
det en 36 mm laminat: 6·1000/36² = 4,63 MPa, utnyttelse 0,67. Den går. **Uten
samvirke** deler de to 18 mm platene lasten hver for seg: 6·500/18² = 9,26 MPa,
utnyttelse **1,33**. Den stryker. Limfugen selv er ikke problemet — den ligger i
nøytralaksen, der langsgående skjær er størst, og der er τ = 1,5·1000/(77·36) =
0,54 MPa. Det er under D3-limet med god margin, men bare så vidt under finérens
egen rullskjær (~0,6–0,8 MPa design) — kortere dobler, samme last, høyere skjær;
K2 gjorde den avviste løsningen dårligere, ikke bedre. Det som avgjør er at **ingenting kan sikre den limfugen**. Hver eneste
andre limte fuge i denne platen har skruer som klemmer; her finnes det ingen
skrue som passer. 18 mm dobler under 18 mm plate er 36 mm materiale, og den
korteste skruen i denne sengen er en 5×40 — 4 mm av den ville kommet ut gjennom
platens overside, den ene flaten som aldri skal brytes — og et kontrabor får ikke
plass i 18 mm og fortsatt la det stå kjøtt igjen. Doblerne ville altså vært lim
alene, med 1,33 som nedre grense. En detalj hvis fallback er 1,33 går ikke under
et barns kne.

*Slankere lekter, 48×48, ble veid og lagt bort:* utnyttelsen blir 0,37, som er
helt greit. Men 48×48 er en profil sengen brukte to revisjoner (W3 og U5) på å
bli kvitt, og hvert eneste kutt i denne sengen er 90° på kappsag. Et kløyvkutt
for to 77 mm biter er ikke verdt en foreldreløs profil.

**Ingen skruer i bordplata.** Platen er bordplate halve livet, og seksten
skruehoder — eller seksten propper — midt i den er seksten merker. Lektene **limes**
(D3) og skrus **nedenfra**: ⌀12 kontrabor 41 mm opp i lektas underside, så en
5×40 gjennom de siste 27 mm av lekta og 13 mm inn i den 18 mm plata, med 5 mm
plate igjen over spissen. Kontraboret er ikke pynt — det er den eneste måten å
sikte gjengelengden på: rett gjennom 68 mm lekt ville en 5×80 tatt 12 mm og en
5×90 alle atten. De 41 millimeterne er den samme regelen som gjelder i
kilene, bare i tykkere tre: bor opp til det står 27 mm igjen. Se J13b.

I bruk står fugen uansett i trykk: platen *hviler* på lektas overkant, så
2 kN-lasten går aldri gjennom et festemiddel. Skruene har én lastsituasjon —
at enheten løftes etter et hjørne — og der er 62 N egenvekt (6,3 kg,
regnet av kroppene) mot 16 skruer.

*De to alternativene, og hvorfor de tapte:* skråskruer gjennom lektas side
treffer bare 18/cos30 = 21 mm plate før spissen bryter ut i overflaten. Hodet
kunne fått et flatbunnet sete, slik J8-B og J10 nå får, men et sete gjør
ingenting med de 21 millimeterne. Proppede topskruer er det
klassiske svaret og nesten usynlig i massiv furu — men denne plata er
**kryssfiner**, og en propp i et finérdekke er en skive endeved i en ubrutt
flate.

*Og her har K2 tatt fra oss et argument uten å gi oss et nytt.* Fram til v12 var
platen 652 mm bred — bredere enn de 600 mm limtre furu stopper på i hylla — og
kryssfiner var rett og slett det eneste som fantes i den bredden. 574 går inn i
en 600 mm limtreplate. Materialet står likevel: lasttabellen, uttrekket for
oppskruene og propp-argumentet over er alle regnet på kryssfiner, og et
materialvalg tas ikke om i en komfortrunde. Men det er et **valg** nå, ikke en
tvang, og det er ført opp som åpent punkt i innkjøpslista i stedet for å bli
stilltiende stående på en begrunnelse som er utløpt.

**Det som IKKE er låst: platen kan løftes rett opp.** Det er meningen — det er
slik den skifter stilling. **Valget er tatt, og det er ingen lås.** Begrunnelsen
står i vedlegg B, avvik 4, og den skal leses før noen bygger dette.

Treverket en lås ville tatt tak i, står der det sto: **tre mot tre** —
kilelektas endeved mot enden av den fremre benkevangen, tvers over de 63 mm i
sideklaringen. De to flatene ligger side om side i sengestilling og i samme
høydebånd; i bordstilling står kilelekta **385 mm** høyere — X9 tok løftet
mellom de to setene fra 245 til 385 — så en lås ville ikke hatt noe å ta i.
Den kan altså ikke stå på i feil stilling, og det følger av
geometrien og ikke av en instruks. Alle tre alternativene i
`docs/preview/laasvalg.png` virker over nettopp de 63 millimeterne og passer det
treet uendret, så dette er et **ettermonteringspunkt**: skulle låsen komme, er
det en skrue som dukker opp, ikke en trebit som endres. Det arket er historikk,
ikke en bestilling — det lages for hånd med `mise run mekanisme` og er ikke med
i byggeporten.

**Innsettingsveien er målt, ikke antatt.** Modellen sveiper hele enheten — plate,
to styrelekter, to kiler og seksten skruer — rett opp fra begge seter og krever at
ingenting treffer noe: **126 mm** fri vei i sengestilling og **214 mm** i
bordstilling. Det skal **68 mm** til for å løfte styrelektenes underkant fri av
låsedelens overkant, så det er **1,85 ganger** så mye vei nede og **3,15 ganger**
oppe. Taket er **trinn 2** i sengestilling og **trinn 4** i bordstilling —
begge deler er tre som *må* være der.

**X16 snudde hvilken av de to som er den trange.** Under X9 lå bordstillingen
nøyaktig på grensen (100) og sengestillingen romslig; nå er det motsatt.
Grunnen er den samme i begge ender: taket over bordsetet er ikke lenger trinnet
som *bar* platen, men trinnet **over** det — trinn 4 på 962, underkant 914 — så
løftet i bordstilling ble mer enn dobbelt så høyt. Og i sengestilling kom trinn 2
ned fra 572 til 489 med resten av det nedre løpet, så taket der falt tilsvarende.
Begge ligger godt over kravet.

*De 68 er ikke de 48 lekta lapper.* Fram til X10 sto det 48 her, og det er
lengden på **omfaret** — hvor mye av trinnenden styrelekta
ligger utenpå i høyden. Løftet som skal til for å komme fri av den er noe annet:
låsedelens overkant *er* platens egen underside, så lekta må opp hele sin egen
høyde, 68 mm. To forskjellige mål på samme sted, og modellen holder dem fra
hverandre nå. Med det gamle tallet spurte innsettingsprøven etter 2 × 48 = 96 mm
mot en bordstilling som da lå på 100 — riktig svar på feil spørsmål, og
[X10: 4 mm] fra å stryke på et tall som aldri var tallet.

**De 100 er kravet, og etter X16 er begge stillinger godt over det.** Modellen
har hele tiden krevd 100 mm rett løft i begge seter. Under X9 lå bordstillingen
**nøyaktig** på grensen — platetoppen på 700 og trinnet over støttetrinnet med underkant på 800 — fordi
det trinnet var lokket over platen og bare var løftet akkurat så mye at 700 gikk
opp. X16 la et trinn under platen i stedet, og da ble lokket trinn 4: taket over
en plate i bordstilling gikk fra 700 til **814**, og løftet fra 100 til 214.
Kravet er ikke slakket i noen ende; det er delen under platen som er byttet ut.
(Fram til X9 var tallene 159 og 179, med bordbærelekta som tak i
sengestilling; fram til K1 var det en stigekloss i begge tilfeller, med 109 og
124 mm — de klossene var 37 mm for lange og hang inn i veien uten å gjøre noen
nytte. Se K1, X9 og X16 i modellen.)

**Men stillingsbyttet er ikke ett langt loddrett løft — og det er verdt å lese
før du prøver.** De to fri veiene over gjelder *setet*: hvordan platen kommer
ned i det og opp av det. Selve byttet mellom de to setene må utenom stigen, for
over sengesetet er det stigen som er taket. Veien er målt på solidene, ramme for
ramme (`mise run film-mekanisme`), og filmen under **er** den prøven — ikke en
tegning av den:

0. **Ta av alle fire putene først.** Dette er ikke ryddighet: enheten bæres
   sidelengs i sjakten mellom benkespilenes overkant (320) og trinn 2s
   underside (441), og den sjakten er 121 mm høy for en enhet på 86. En 100 mm
   pute som ligger på benken har overflaten sin på **420** — 21 mm under
   sjaktens eget tak — så med putene på er det ikke plass til enheten i det hele
   tatt. Ombyggingen er fysisk sperret. *(X16 tok trinn 2 ned fra 572 til 489, så
   dette er blitt trangere: sjakten var 204 mm.)*
1. **Løft rett opp**, ca. 15 cm, til enheten står midt i overføringssjakten.
2. **Skyv platen sidelengs** inn over benken, til den er klar av stigen —
   **vannrett hele veien**. Sjakten mellom benkespilenes overkant (320) og
   trinn 2s underside (441) er 121 mm høy og enheten er 86: det står **35 mm**
   klaring i alt, delt likt over og under den under hele bæringen, mot et krav
   på 15. Dette er den trangeste av de to bæringene nå. (Før X9 var sjakten 154 mm, med taket
   i bordbærelekta på 474; lekta gikk opp med bordplaten, og det som er igjen
   som tak er trinn 2.)
3. **Trekk den litt fram**, så bakkanten står av bordbærelekta.
4. **Løft den opp** forbi bordbærelekta og opp i kryssebåndet — ute over benken
   er banen fri.
5. **Skyv den inn igjen** til bakkanten står over setelinjen.
6. **Skyv den sidelengs tilbake** over stigen, nå i båndet mellom
   støttetrinnets overkant (682) og trinn 4s underside (914).
7. **Senk den ned** i bordsetet.

Veien tilbake er den samme baklengs.

**Etappe 3 og 5 ser ut som fikling, og er det ikke.** Bordbærelekta går tvers
gjennom hele sengen på Y −48…0, altså akkurat der platens bakkant ligger, så
bakkanten *må* av linja dens før den kan gå opp — uansett hvor i lengden du
står. Alt det andre er ett løft, én bæring bort, én bæring tilbake og én
nedsenking.

**Etappe 6 er den X9 måtte betale for, og X16 fikk pengene igjen.** Enheten må
gå **over** sitt eget fremre opplegg på veien tilbake — det gjelder uansett hva
opplegget er laget av. Båndet er 682 (støttetrinnets overkant) til **914**
(trinn 4s underkant) = **232 mm**, enheten er 86, og det står **146 mm**
klaring igjen mot et krav på 15. *X9 hadde 32 mm her, over bordklossene, fordi
lokket den gang var det samme trinnet som sto rett over dem.* Det er dette
båndet X8 regnet til å være 29 mm for lite, med trinn 3 der det da sto.

*Slik var det ikke før.* Fram til K1 var sjakten 91 mm høy for en 91 mm høy
enhet — null klaring — og den eneste veien gjennom var å **vippe** den ene
langsiden tre grader opp og holde vippen gjennom hele bæringen, over en benk,
over hodehøyde. Det var ni grep og et to-personers løft. De 37 millimeterne som
ble kappet av hver stigekloss er hele forskjellen.

Den trangeste passeringen på hele veien er **2 mm** — nøyaktig den passingen
platen er tegnet med, mot stigevangen. Og platen kommer aldri *ut* av sengen:
den er bredere enn åpningene ved siden av stigen, så den blir i underetasjen
hele veien. Skal den helt ut, må den ut på høykant gjennom fronten.

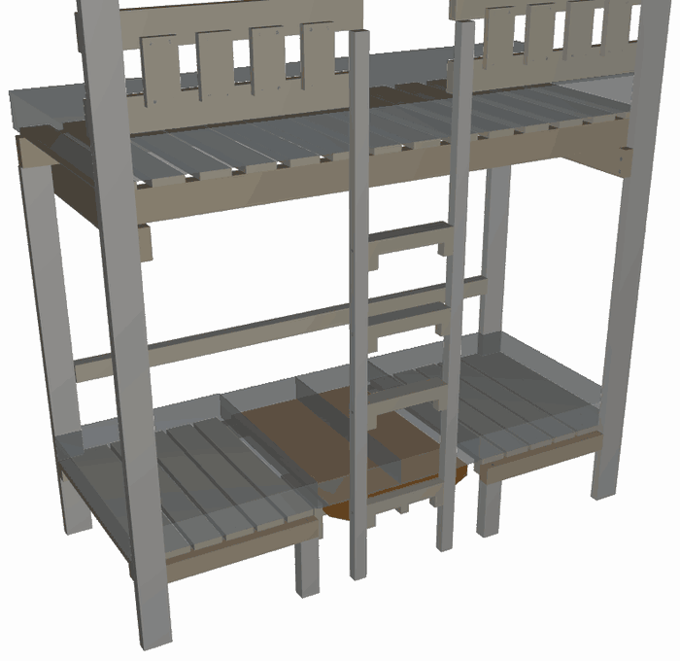
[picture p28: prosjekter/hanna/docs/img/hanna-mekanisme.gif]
Platen fra sengesete til bordsete


*Stillingsbyttet, sju etapper, flatt. Ingen ramme i filmen har tre inne i tre —
det er en assert, ikke en påstand: `tools/render_animasjon.py` legger hver
stilling gjennom en separerende-akse-prøve mot hver eneste faste del i sengen og
nekter å lage filmen hvis noe kolliderer.*

### J14 — Veggfeste (obligatorisk)

**Sengen skal skrus fast i veggen. Dette er ikke valgfritt**, av tre grunner:
veggen er rekkverket på baksiden, stigefoten regner med at rammen ikke gynger,
og skruene bærer sin del av den bakre sidevangen.

Festet er så enkelt som det kan bli: **den bakre sidevangen ligger flatt mot
veggen i hele sin lengde**, så du skrur rett gjennom vangen og inn i veggen.
Ingen brakett, ingen kloss, ingen kile.

Finn stenderne og merk av senterlinjene på vangen før du skrur. Ta et feste i
hver stender du treffer, og minst i begge ender og på midten. Er veggen mur
eller betong, bruk plugg eller betongskrue.

**Treff noe som holder.** En plateplugg i gips er ikke et veggfeste for en seng
noen sover i.

### J12-V — Veggfeste gjennom bordbærelekta

Det andre veggfestet, og det er den samme skruen og den samme jobben en meter
lenger ned: **tre stykker gjennom bordbærelekta og inn i stenderne**, midt i
lektas høyde, 648 mm over ferdig gulv. Lekta ligger flatt mot veggen i hele
sin lengde akkurat som sidevangen gjør, så det trengs verken brakett eller
kloss her heller.

Fire innvendinger var verdt å svare på før leddet ble lagt, og ingen av dem
holdt:

* *«Lekta skal kunne belastes rett ned uten å hvile på skruer i uttrekk»* —
  det står fortsatt, og etter X18 er det lommeskruene i endene som svarer for
  det: de ligger på skrå og tar endereaksjonen i **skjær**, ikke i uttrekk.
  Denne skruen ligger **vannrett**, så en last rett ned tar den i skjær også.
* *«Veggplanet skal være helt flatt»* — regelen gjelder alt som stikker ut
  **bak** Y −48. En skrue som drives fra rommet, med hodet forsenket i lektas
  forside, legger ingenting til baksiden. Det er samme geometri som J14 alt
  har, og etter X18 står det ikke lenger noe beslag på den flaten heller.
* *«Lekta må inn mens bakrammen ligger flat»* — den gjør fortsatt det, i steg
  1. **Disse hullene kan ikke bores i verkstedet**: stenderne finnes bare i
  rommet. De bores i steg 2, etter at rammen er reist inntil veggen, samtidig
  med J14.
* *«Senga er referansen, ikke rommet»* — bakrammen er ett stivt lag, og J14
  har allerede dratt hele det laget inntil veggen før disse skruene finnes.
  De bestemmer ikke hvor lekta står; de tar bare last ut av midten av et
  spenn på 1894 mm som ikke hadde noe der.

Forsenk hodene under lektas forside. Det er den flaten ryggputa lener seg mot.

### J15 — Filtknotter

Under alle fire hjørnestolper og alle fire stubbeføtter. Slå dem i før du reiser
noe.

**Ikke under fotbrettet.** Den står på to sammenhengende striper, 36 × 272 mm
hver, og ikke på fire punkter — en ⌀40 tapp under en 36 mm stripe ville gjort
en stødig krakk til en vippe. Den veier 3,1 kg (3,3 med levert virke) og løftes med én hånd;
den dras ikke.

### J18 — Fotbrettbord → gavl (X14)

Åtte 6×80, én per landing: fire bord ganger to gavler. Skruen går rett ned
gjennom 48 mm dekkbord og står 32 mm inn i en 98 mm gavl, midt i gavlens 36 mm
— som er nøyaktig 2 × 3d over skruen, og grunnen til at gavlen er et 36-bord og
ikke et 23. Én skrue per landing er hele regelen: to landinger låser bordet mot
å dreie, og fire bord låser de to gavlene mot å rase. Ingenting i denne krakken
kan bevege seg uten å ta en skrue i skjær.

Forsenk hodene **under** flaten. Dette er den ene flaten i hele sengen som bare
føtter står på.

Krakken skrus ikke til sengen, og det er ikke en forglemmelse: F1 har målt at
det ikke finnes fast tre i denne bukta å skru den til, og en fast fotstøtte her
ville stått i det åpne gulvet mellom benkene. Se 8.2b.

---

## 5. Madrass og puter

Mål på madrass og puter: [nøkkelmål](generated/nokkelmal.md#madrass-og-puter).

### Overkøyen

**Sengen er dimensjonert rundt en standard madrass på 80 × 200 cm.** Det er
ikke et spesialmål, og madrassen skal ikke bestilles etter sengen — det er
sengen som er bygd etter madrassen. Rommet er noen millimeter smalere enn
200 cm, så madrassen presses de siste millimeterne inn mellom veggene. Det er
meningen: da ligger den i ro.

**Tykkelsen er 120 mm, og vinduet er 105–130.** Dette er ikke en smakssak, og
det er den ene grensen i sengen som er lett å bryte uten å vite det. Spalten
mellom madrassens overside og undersiden av det nederste rekkverksbordet skal
enten være **lukket** — under 25 mm — eller ligge i EN 747-båndet **60–75 mm**.
På den bygde sengen ligger bordet lavt, så det er den lukkede grenen som
gjelder:

* **For tynn** madrass åpner spalten seg opp i klemvinduet 25–60 mm — det gapet
  et lem kiler seg fast i i stedet for å gå igjennom.
* **For tykk** madrass står over bordets underkant, og bordet dekker ikke
  lenger madrasskanten — det ligger begravet i den.

**En vanlig 150 mm madrass er ulovlig i denne sengen.** Kjøp 12 cm; da ligger
bordet 10 mm over madrassen og dekker forkanten. Hele resonnementet og den
andre, tynne grenen står i avsnitt 7.3 og vedlegg B.

Tallene regnes ut av modellen av de to faste høydene — spilebunnen og
rekkverket — og står i [nøkkelmålene](generated/nokkelmal.md#madrass-og-puter).
**Maksmålet skal merkes permanent på sengen** (steg 11); EN 747 krever det, og
den som bytter madrass om ti år skal kunne lese grensen av sengen selv.

### Underetasjen — fire puter

Underetasjen er sofa, bord og ekstraseng i én, og **putene ER madrassen
nede**. Det er hele ideen bak nivået: det du sitter på om dagen er det du
sover på om natten, og de fire putene er derfor ikke fire løse gjenstander —
de er én seng, delt i fire.

**Soveflaten nede er 1990 × 800 mm — samme lengde som overkøyen.** Det ble den
i denne runden. Benkespilefeltet stoppet 98 mm fra veggen i hver ende, fordi en
vanlig benkespile går fra veggplanet og fram og ville skåret tvers gjennom den
bakre hjørnestolpen. Nå ligger det en kortere **endespile** der, 764 mm, som
starter på stolpens forside og hviler på en **endelist** skrudd flatt på den
samme stolpen. Listen settes i steg 5 sammen med resten av benkens bæreverk,
spilen i steg 7. Se J16/J17. Uten den er ikke dette en seng i full
lengde, og putekanten har ingenting under seg.

**Stolpen står i flaten.** Det er den ene tingen som ikke lot seg fjerne: de to
bakre hjørnestolpene tar et hjørne på 98 × 36 mm inne i soveflaten, helt ute ved
veggen i hver ende. Derfor skjæres et **hakk på 98 × 36 mm** i veggkanten på
hver av de to benkeputene. Brødkniv, ett minutt.

### Målene — dette er det du bestiller skum etter

| | Mål | Ant. |
|---|---|---:|
| **Benkepute** | **663 × 800 × 100 mm**, med hakk 98 × 36 mm i veggkanten | 2 |
| **Ryggpute** | **332 × 800 × 100 mm**, rent rektangel | 2 |

**Regnestykket er asserten.** Benkeputen er 1/3 av lengden og ryggputen 1/6, og
lagt etter hverandre dekker de fire nøyaktig hele flaten:

> 663 + 332 + 332 + 663 = **1990 mm**

1990 deler seg ikke på seks. Tredelen er derfor rundet ned og sjettedelen opp —
0,33 mm hver vei — og summen er eksakt. Det er summen som må stemme; ingen
kapper en tredels millimeter skum. Modellen sjekker dekningen som areal, ikke
som påstand: de fire puteflatene skal legge seg over soveflaten uten overlapp og
uten hull, ellers stopper `mise run build`.

**Alle fire er 100 mm tykke.** Lik tykkelse er ikke en forenkling, det er
kravet: fire like tykke puter er én flat seng, fire ulike er en seng med trinn i.
Valget av nettopp 100 mm står på fire tall:

* **Én skumplate dekker alt.** 80 × 200 cm er 800 × 2000 mm — 800 er nøyaktig
  flatens dybde og 2000 er 10 mm mer enn lengden. Fire tverrkapp, og du er
  ferdig. Det gjelder like godt for en billig skummadrass 80 × 200 som for en
  plate fra en skumforretning.
* **Sittehøyden** blir 320 + 100 = **420 mm**. Det er en voksen stolhøyde.
* **Bordplaten** ligger 280 mm over seteputen, undersiden 262 mm — et sittende
  kne står 135 mm over setet, så knærne går inn under platen med 127 mm luft.
  Går du til 120 mm skum blir de 260 og 242, og knærne går fortsatt inn. Dette
  var det strengeste av de fire tallene til og med v15, da platen lå 140 og 122
  over setet og bare et strakt lår kom under: 120 mm skum ville gjort de
  122 til 102 og stengt den. **X9 løste den bindingen** ved å flytte platen i
  stedet for puten, og skumtykkelsen står nå på de tre andre grunnene alene.
* **Hodehøyden** over soveflaten nede er 1080 mm opp til køyespilene (982 under
  sidevangene). Det er god sitte-opp-høyde for et barn.

120 mm skum finnes i samme handel og ville også virket — det er mykere å sitte
på, og det tar 20 mm av knerommet under pulten uten å stenge det. Da må **alle
fire** være 120.

### Midtsonen ligger 5 mm lavere, og putene er like tykke likevel

Platen i midten ligger 5 mm under benkeflaten (315 mot 320). Den gamle regelen
var at midtputen skulle være de 5 millimeterne tykkere. Den regelen er ute, av
to grunner: alle fire skal være like tykke, og **ingen puteskjøt ligger lenger
på en sonegrense** — skjøtene faller på 663 og 1327, mens sonene skifter på 645
og 1345. De 5 millimeterne tas av skummet, som er akkurat det V6 kappet
forsenkningen fra 18 til 5 for.

**Midtsonen er 700 mm bred, men platen er 574.** Etter K2 står det en **63 mm
åpen stripe** langs hver side av platen, hele 798 mm fra veggen og fram til
stigen. Den bygges nå ut av putene som ligger over den — benkeputen henger 18 mm
utenfor benkeenden og ryggputen tar resten. Skum bygger 63 mm ut uten videre:
sengens egen spilebunn over ligger på 44,5 mm mellom spilene, og benkene på
14,25. Stripene er der med hensikt: 63 mm ligger i EN 747-båndet 60–75 mm, der
hele lemmet går fritt, og de er prisen for at platen skal kunne senkes ned i
bordstillingen uten å treffe blindt. Se tabellen over lovlige platebredder i
[nøkkelmål](generated/nokkelmal.md#platebredden-er-kvantisert--lovlige-vinduer).

### Under benken er det et rom, og nå er det målt

Stubbeføttene bærer benkevangene på fire punkter i stedet for på en sokkel, og
det de lar bli igjen er et **kasserom under hver benk**: **229 mm høyt × 479
mm bredt × 800 mm dypt** — gulv til benkevangens underkant, bakre
hjørnestolpes innerside til stubbefotens ytterside, og vegg til fremre
benkevanges forside. Dybden er benkespilens egen lengde, for kassa skyves inn
**under** vangen og ikke forbi den. To slike rom, ett under hver benk; mellom
dem er gulvet åpent foran stigen, og der skal det ikke stå noe (D13). Både
rommet og innkjøringen foran det er målt tomme på solidene.

Høyden er et **minstemål**: rammen bygges i vater fra høyderisset over gulvets
høyeste punkt, så 229 mm er høyden akkurat der og mer overalt ellers. Tallene
står i [nøkkelmål](generated/nokkelmal.md#kasserommet-under-benkene).

### Hvor de ligger — og hvor de står

**Sengestilling:** alle fire flatt, etter hverandre. Benkepute, ryggpute,
ryggpute, benkepute, fra vegg til vegg.

**Sofastilling:** de to benkeputene ligger **nøyaktig der de lå** — de flyttes
aldri. De to ryggputene reises på høykant ytterst på hver benk, oppå seteputen,
med den 800 mm lange kanten inn i dybden: 100 mm tykke, 800 mm dype, 332 mm
høye, topp 752 mm over gulvet. Ombygging er altså **to puter, ikke fire**.

Ryggputen står der den står fordi det er det eneste stedet den får plass.
Ryggen mot bakveggen — det opplagte — går ikke: puten er 800 mm i sin andre
retning, og bak benken er det bare 645 mm vegg før gangbukta begynner, og fra
X 708 står bordplaten i veien. Stilt på høykant blir den 800 mm høy og rekker
til Z 1220 — det er ikke en sofarygg. Det ene stedet 800 mm står oppreist her, er
**på tvers av benken**, altså i enden — og da er svaret på hva denne sofaen er
også gitt: to seter som vender inn mot en pult, med ryggen i hver sin ende.
Benken er 800 mm dyp, ryggen er 800 mm bred, og det er plass til to i bredden.

To ting holder den: **bordbærelekta**, som går langs hele bakveggen på Z
**614–682** og som ryggputen lener seg mot over 100 × 68 mm, og hjørnestolpens
innerflate sideveis. X9 flyttet lekta 140 mm opp med bordplaten, og kontakten
flyttet seg oppover ryggen med den: den tok før i korsryggen, 54–122 mm over
setet, og tar nå midt på ryggen, 194–262. Det er de samme 68 millimeterne med
anlegg og de samme 100 × 68 mm kontaktflate — bare høyere oppe på ryggen.

Puten står derfor 48 mm fram fra veggplanet, og forkanten
lander 12 mm utenfor sengens forkant. Det er en løs skumpute i én stilling, ikke
sengens dybde — sengen er 836 mm dyp som før.

### Putene av FØR du bygger om

Plateenheten bæres **sidelengs inn over benken** i sjakten mellom benkespilenes
overkant (320) og trinn 2s underside (441) — **121 mm** — og enheten er 86 mm
høy, så det er 35 mm klaring å fordele over og under den. En 100 mm pute som
ligger på benken har overflaten på **420**, altså bare 21 mm under sjaktens eget
tak: da er det ikke plass til enheten i det hele tatt. Ombyggingen er fysisk
sperret med putene på, og modellen regner det ut selv. Første steg i begge
retninger: **ta av alle fire putene.**

*Sjakten var 154 mm til og med v15, med taket i bordbærelektas underside på
474. X9 tok lekta med opp i pulthøyde, og da ble trinn 2 taket — 204 mm. X16
tok hele det nedre løpet ned, trinn 2 med det, og sjakten er blitt den
trangeste passeringen i hele ombyggingen. 35 mm mot et krav på 15 er fortsatt
god margin, men den tåler ikke en pute.*

### Å skaffe skummet

| | Hva | Ca. pris | Merknad |
|---|---|---|---|
| **a** | Skummadrass 80 × 200 × 10 fra en møbelkjede, deles i fire | ≈ 450 kr | Klart billigst, og målet passer på millimeteren. Fastheten er i tynneste laget som sitteunderlag — legg en fastere topper på de to benkeputene |
| **b** | Industrisøm, skumplate 10 cm kvalitet 35P, 80 × 200, kappes til | ≈ 2 200 kr | Fastest og mest «møbelaktig». Du kapper selv, eller får det kappet |
| **c** | Kaldskum 39K, eller mål-tilpasset fra maaho.com | ≈ 4 300 kr | Dyrest, men du får riktig mål og riktig fasthet levert, uten å kappe |

**Alle tre trenger trekk.** Skum uten trekk smuldrer og blir skittent. Regn med
trekk som en egen post uansett hvilken vei du går — fem trekk, ett til
madrassen og fire til putene.

**Skjøt putene til hverandre** med borrelås eller trykknapper i trekkene. Ellers
sklir de fra hverandre den første natta noen sover der.

---

## 6. Notater til butikkturen

* **Hovedbordet må bestilles.** Ring før du drar. Det aller meste av sengen er
  det samme bordet, og butikken har sjelden nok av det på lager. Får du bare
  nærmeste nabo-dimensjon, er det mulig — men da er det én konstant i
  `generate_loftbed.py` som endres, og hele modellen må kjøres på nytt og
  kapplista regnes om. Ikke improviser på sagbenken.
* **Spilene er 23×98, ikke 36×98.** En spile ligger flatt, så tykkelsen er
  bæreretningen — og etter at spilekriteriet ble regnet på det en spile faktisk
  bærer (vedlegg A), er 23 mm nok med god margin. De 26 spilene er godt over en
  tredel av alle trebitene i sengen — 14 køyespiler og 10 benkespiler à 800 mm
  pluss de to endespilene à 764 — så valget tar 20,7 løpemeter ned fra det dyre bordet
  til det billige, sparer rundt 11 kg og gjør spilebunnen 13 mm lavere. **Og
  X18 la åtte biter til på det samme bordet:** rekkverkets avstivere er 180 mm
  av det samme virket, kappet av restene. 23×98
  justert er en hyllevare. Rekkverk, stolper og vanger står igjen på 36×98 og
  48×98 — de er belastet på høykant, og der er tykkelsen verdt å betale for.
* **Hovedbordet finnes bare i 4,8 m.** 36×98 C24 selges som fast lengde bare
  på 4800 mm; 4200 og 3600 finnes ikke i denne dimensjonen. Kappeplanen i
  innkjøpslista er lagt på 4,8 m-bord alene.
* **Kjøp alt konstruksjonsvirke som C24.** Det gjelder også lektdimensjonene
  36×48 og 48×68, som mange steder står i hylla bare som «klasse 1 lekt/rekke
  — ikke-bærende». Spør i skranken: stigevangene og stigeklossene (36×48),
  rungetrinnene og stubbeføttene (48×68) er alle bærende, og
  lasttabellen i vedlegg A regner C24.
* **36×48 er to bord etter X18.** Det var ett, og det holdt akkurat — to
  stigevanger, ti stigeklosser og to endelister med 68 mm til overs. X18 gjorde
  tre ting med den bunken: stigen mistet ett trinn og dermed to klosser,
  stigevangene ble 166 mm kortere hver, men benken fikk **to benkespileledd på
  547 mm og to fremre endelister** — og de to leddene alene er mer enn resten
  av bordet. Kapp de to vangene og de to leddene først; klossene og listene tar
  hva som helst av det som blir igjen.
  *(X9 la de to bordklossene på denne dimensjonen og skjøv fire stigeklosser
  over på et bord nummer to; X10 flyttet klossene til 48×68, og X16 strøk dem
  helt. Svinnet har vært innom 49 % på veien.)*
  Se [innkjøpslista](generated/innkjopsliste.md).
* **Platen kappes av 18 mm kryssfiner.** Etter K2 er den 574 mm bred og ville
  gått inn i en 600 mm limtreplate — men lasttabellen, uttrekket for
  oppskruene og propp-argumentet i J13 er alle regnet på kryssfiner, så
  materialet står. Det er et valg nå, ikke en tvang; se innkjøpslista.
* **Vil du kunne bygge om til frittstående seng senere?** Da trenger du to
  rekkverksbord til på baksiden og to bakre stolper i full høyde. Kjøp dem gjerne
  nå, og — viktigst — **forbor de bakre stolpene for rekkverket mens de ligger på
  bukken**. Resten av sengen er uendret; det er bare de fire delene.
* Kjøp litt ekstra av alle skruestørrelsene. De koster ingenting, og en tur
  tilbake koster en kveld.

---

## 7. Sikkerhet

Kravene er fra **EN 747-1:2024 og EN 747-2:2024** (køyesenger og loftsenger). Tallene sengen faktisk
har, og kravet ved siden av, står i
[nøkkelmål](generated/nokkelmal.md#sikkerhetsmål-en-747). Alle er innenfor.

**7.1 Baksiden har ikke rekkverk — veggen er sperren.** Det er derfor sengen må
skrus fast i veggen (J14), og det er derfor den ikke kan snus. Madrassen er
**klemt fast** mellom veggen og de fremre stolpene: den fyller hele dybden, den
kan ikke skyve seg, og det står ingen spalte igjen langs noen av de to lange
kantene. Klemspalte-spørsmålet på den siden er dermed ikke i spill i det hele
tatt.

**7.2 Rekkverket foran har en klatreåpning.** Man klatrer gjennom, ikke over
toppbordet. Åpningen er like bred som stigen og ligger rett over den.

**7.3 Madrasstykkelsen skal være 105–130 mm, og 120 er anbefalt.** Dette er den
viktigste tallgrensen i hele sengen, og den er ikke et tak — den er et **bånd**.
Åpningen mellom madrassens overflate og undersiden av det nederste
rekkverksbordet skal enten være **lukket**, altså under 25 mm, der ingenting
kan komme inn — eller ligge i **60–75 mm**, der hele lemmet går fritt
igjennom. Alt imellom, **25–60 mm**, er nettopp det gapet et lem kiler seg fast
i i stedet for å gå igjennom.

Madrassen er det eneste som styrer den åpningen. På den **bygde** sengen står
nederste bords underkant 130 mm over spilene, og da ser tabellen slik ut:

| Madrass | Åpning | Dom |
|---:|---:|---|
| 100 mm og under | 30 mm og mer | ✗ **FORBUDT** — klemvinduet |
| 105 mm | 25 mm | lovlig, **nøyaktig på grensen** — ingen margin |
| **120 mm** | **10 mm** | ✓ **anbefalt** — bordet ligger like over madrassen og dekker forkanten |
| 130 mm | 0 mm | lovlig, madrassen rekker akkurat opp i bordet |
| 140 mm og over | — | ✗ **FORBUDT** — madrassen står inne i selve rekkverksbordet, som da ikke dekker kanten lenger, det ligger begravet i den |

**Kjøp 12 cm.** En helt vanlig 15 cm madrass er *ulovlig* i denne sengen. Det er
ikke opplagt, og det er grunnen til at maksmålet skal merkes permanent på
sengen (steg 11) — linja 1653 mm over gulvet, som er nederste bords underkant
og altså en strek du kan se.

**7.3b HVORFOR TABELLEN SER ANNERLEDES UT ENN PÅ TEGNINGEN.** Tegningen hadde
nederste bord 185 mm over spilene, altså 65 mm over en 120 mm madrass, og da
var vinduet 110–125 mm og åpningen lå i 60–75-båndet: *luft* under bordet.
Byggherren satte bordet lavere, og da bytter regelen gren — åpningen er
**lukket** i stedet for klar. Begge er lovlige svar på det samme kravet, og den
bygde er den strammere av dem: 10 mm der tegningen hadde 65.

*(En tidligere runde leste byggherrens 130 mm fra madrasstoppen i stedet for
fra spilene, fikk 130 mm åpning ut av det og skrev det opp som sengens ene
ulovlige mål — vedlegg B, avvik 6, med krav om en mye tykkere madrass [var 175–190 mm]. Det var
en feillesning av datumet, ikke av tommestokken. Avviket er lukket.)*

**7.4 Ikke sett hele vekten på én bar spile.** Å gå på bar spilebunn er greit —
en fotsåle rekker alltid over minst to spiler, og det er den lasten spilen er
regnet for. Det som ikke er greit, er å hoppe, eller å sette hele vekten på én
spile midt i spennet, uten madrass over. Legg madrassen på før noen går opp; da
er spørsmålet uansett ute av bildet.

**7.5 Den løse platen skal alltid ligge i.** Den står som en stiver mellom
veggen og stigevangene: med platen i kan ikke stigefoten gå bakover. Skal du ha
den ut, ta stigen med i vurderingen — og ikke la noen klatre mens platen er
ute. **Byttet mellom de to stillingene er sju håndgrep, ikke ett loddrett
løft** — men det er sju *flate* håndgrep etter K1: enheten bæres vannrett, med
104 mm luft over og under, og skal ikke vippes. (Sjakten var 121 mm på
tegningen og er 294 på den bygde sengen: trinnet som gjorde den trang, ble
aldri kappet. Se X18.) Rekkefølgen og hvorfor den er
slik står i J13, med film.

**7.6 Ikke sett deg på platens kant, og ikke bruk den som trinn.** Den er
sikret mot å vippe, men den er ikke en avsats.

**7.7 Ettertrekk.** Ettertrekk rammeskruene etter fire uker og deretter en
gang i året. Sengen vibrerer hver gang noen snur seg.

**7.8 Aldersgrense.** Loftsenger og overkøyer anbefales ikke til barn under
**6 år**.

**7.9 Sjekk sengen når du flytter noe.** Blir sengen dratt ut fra veggen, mister
den både rekkverket sitt og stivheten sin.

**7.10 Alle kanter et barn kan nå skal være brutt.** Også de du ikke ser —
undersiden av plateenheten står i knehøyde for den som sitter ved pulten, og
etter X9 er knærne faktisk der inne og ikke oppe på benken. Kravet, stedene og
verktøyet står i avsnitt 3.

---
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

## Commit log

2026-08-09 feat: loft bed generator v8 — flush-top platform, 320 ladder, resting panel with battens
    Freestanding loft bed for a 1990 mm wall-to-wall alcove, generated with
    build123d and validated by asserts on every run.
    - Flush top: the slat cleats are gone, 34x98 slats lie on top of both side
    rails, and the depth stack comes in 106 mm on the front side only, so the
    800 mm mattress lands exactly on the slat ends at both edges (0 mm of bare
    slat, 0 mm of play).
    - Slim ladder: 320 mm clear between 36x48 uprights, four 48x73 treads on
    cleat blocks, and a 320 mm climb-through gap in both front guard bands -
    you climb through the guard rail, not over it.
    - Open front floor: the front bench rai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
    [bed_frame.step, parts.tsv]
2026-08-09 feat: wall-side back - remove back guards, trim back posts, slim stub legs
    The bed's back long side stands against the room wall and the frame is
    bolted to it, so the wall is the barrier on that side. Three consequences,
    all of them geometry:
    * the two 34x98 x 1984 back guard boards (Y -130..-96) are deleted. The
    D6 entrapment arithmetic becomes a front-side statement over the same
    two bands; the back side is checked instead against the mattress-to-wall
    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
    [parts.tsv]
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2026-08-09 feat: back posts tucked under rail — depth 848, mattress at wall
    [parts.tsv]
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2026-08-10 spec og tegning: J9-F til 6x60, C24 uten forbehold, stubbefot 48x73, halvsnitt
    J9-F bytter 6x70 mot 6x60. Skruen gar gjennom 36 mm bareklass og 24 mm
    inn i den 36 mm tykke fremre stolpen, altsa 12 mm tre bak spissen mot
    2 mm for. Fysikkregelen utledes pa nytt av modellen: den strammeste
    spissdekningen i sengen er na 6x80-monsteret inn i en vange (J2, J3,
    J8) med 4 mm, og FASTENER_MIN_TIP_COVER settes av den. 6x70 forsvinner
    helt ut av beslaglista - 15 poster i stedet for 16 - og 6x60 kommer inn
    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
    [parts.tsv]
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2026-08-10 fyllkoden slås på av formen, ikke av vane
    Koden lå på hver stegside med bokstaver, uansett om skruene på siden lignet
    hverandre eller ikke. Den ble kjøpt for ett problem — to festemidler som
    silhuetten ikke skiller — og betales nå bare der problemet finnes.
    Vilkåret regnes ut av leddataene: to skruer på samme side er tvetydige av form
    når lengdeforskjellen er under 25 % av den lengste og diameterne er i samme
    klasse eller skiller seg med høyst 1 mm. Slår det til, kodes hele sidens sett;
    ellers står alle festemidlene i ren kontur. Tallene står ett sted
    (gen_glyphs.ambiguous_pairs), og svaret følger steget ut i byggesteg.json som
    fill_code — utledet på samme måte som ha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
2026-08-11 platen blir en nedsenkbar enhet: fire vinkelbeslag, 24 mm sideklaring, tverrlekter under forkanten
    Krokplata og U-braketten er ute. Ingen av dem kunne senkes ned i sengen:
    begge grep om baksiden av en del, og platen har null vandring i Y.
    Det som erstatter dem:
    - to vinkelbeslag 20x20x40 bak, som ligger PA opplegget i sideklaringen
    ved siden av platen - aldri under den - i begge stillinger;
    - to vinkelbeslag 40x40x20 foran, skrudd opp under platen like utenfor
    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
    [parts.tsv]
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2026-08-11 ASSEMBLY: J13 skrevet om, og det V2 gir fra seg star svart pa hvitt
    J13-avsnittet folger den nye mekanismen: hva som baerer (tre), hva som
    styrer (fire vinkelbeslag), hvorfor det bakre beslaget star i klaringen og
    ikke bak platen, og hva de 2 millimeterne ved trinnenden er.
    Avvik 2 far et apent punkt: U-braketten bandt platen til stigen i strekk,
    og den bindingen er borte. Platen er na en enveis stiver - stigefoten kan
    ikke ga bakover, men framover holdes den bare av J3. Skal det bli et krav,
    er svaret et band fra stigefoten til rammen, ikke et beslag pa platen.
    mise run mekanisme lager de tre bevisarkene.
2026-08-11 V3: lektene blir styringen, og de fire vinkelbeslagene forsvinner
    De to 48x73-lektene flyttes ut fra innsiden av stigeklosslinja til
    UTSIDEN av trinnendene (X 785..833 / 1157..1205, 2 mm klar av 835 og
    1155) og fram til platens egen forkant, Y 0..750. De siste 35 mm av
    hver lekt star i den 48 x 37 mm frie sjakten ved siden av trinnenden -
    den samme sjakten stoppfliken pa J13d sto i - sa X+, X- og vridning om
    Z tas av 48 x 35 mm tre mot endeved i stedet for 2 mm forsinket plate.
    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
    [parts.tsv]
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2026-08-11 V5: fronten uten skruehoder, og de åtte bæreklossene ut
    To beslutninger som er samme beslutning to ganger — ikke tro på en detalj
    fordi den alltid har stått der, gå og mål den.
    INGEN SKRUEHODER PÅ EN ROMVENDT FLATE. Tre av sengens fire sider er vegg;
    den fjerde er fronten, Y 752..788, og den er den eneste flaten noen ser på.
    Rekkverksbordene har vært skrudd innenfra siden D14. J2, J3 og J8 var det
    ikke, og hodene deres sto på stolpenes og stigevangenes forside. Alle tre
    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
    [parts.tsv]
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2026-08-11 K1+K2: stigeklossen kappes til vangens dybde, platen ned i neste lovlige bredde
    To endringer, ingen av dem i en lastvei.
    K1 - stigeklossen 36x48 x 73 -> 36, satt i vangens eget Y-bånd 752..788.
    Etter U2 snudde stigevangen har bare 36 av klossens 73 mm rørt vangen; de
    bakerste 37 hang fritt bak vangens bakplan og rørte ingenting - bortsett fra
    platens overføringssjakt. Platen går til Y 750, klossen sto til Y 715, og de
    35 mm var hele takhøyden i moduskiftet: de dro taket ned med klossens fulle
    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
    [parts.tsv]
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2026-08-11 flytt HANNA inn i prosjekter/hanna
    Repoet blir en verkstedbu med plass til flere prosjekter, og loftsengen er det
    første. Alt som hører sengen til - modellen, tools/, docs/, parts.tsv, v1/ og
    requirements.txt - flyttes inn under prosjekter/hanna/ i én operasjon, slik at
    alle interne stier er de samme relative stiene de var.
    Det er derfor dette er en ren flytting og ikke en omskriving: hvert verktøy
    regner ut sin egen ROT som forelderen til tools/, og hver generert lenke i
    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
    [parts.tsv]
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2026-08-12 modell og dokumenter: spilene til 23×98, lektene til 48×68, endebjelkene til 36×98
    Tre beslutninger i én runde, alle drevet av hva delene faktisk bærer og hva
    butikken faktisk fører.
    Spilene (24 stk.) går 36×98 → 23×98. En spile ligger flatt, så tykkelsen er
    bæreretningen, og motstandsmomentet faller til 41 %. Det bærer bare fordi
    lasttilfellet er regnet om i vedlegg A: en spile bærer aldri en hel person
    alene. Kriteriet er nå bar spilebunn med én fot, som med delingen 142,46 mm
    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
    [parts.tsv]
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2026-08-12 sikkerhet: madrassvinduet er et baand, ikke et tak - 140-155 mm, kjoep 150
    Dette er en rettelse, ikke en forbedring. EN 747-1 krever at aapningen mellom
    madrassens overside og undersiden av det nederste rekkverksbordet enten er
    <= 5 mm eller ligger i baandet 60-75 mm. Modellen har behandlet kravet som et
    rent tak paa 75, og oppga derfor vinduet 140-326 mm. Alt fra 156 til 205
    legger aapningen mellom 59 og 10 mm - midt i det gapet et lem kiler seg fast
    i. En helt vanlig 160 mm madrass var altsaa ulovlig i en seng manualen sa ja
    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
    [parts.tsv]
2026-08-12 piktogram: blyanten bak øret — merk og forbor før du skrur
    «Før du begynner» hadde en rad som sa steg 0-regelen med ord og et bokikon:
    «Les steg 0 først. All saging og all boring skjer før noe reises.» Budskapet
    var riktig, bildet sa ingenting, og raden hadde ingen IKKE SLIK ved siden av
    seg. Nå står regelen i bildet.
    SLIK: figuren med blyanten bak øret, delene liggende ryddig og merket foran
    seg. IKKE SLIK (krysset): den samme figuren med skrutrekkeren klar i hånda og
    delene i en haug. Blyanten er tegnet som en spisset kropp med bruddstreken der
    spissingen begynner — en bar strek ved hodet leste som en arm, og det er prøvd
    på 12 og 17 mm før formen ble valgt. Skrutrekke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
2026-08-15 rommet får sine egne tegninger
    Spikerslag-veggopprisset: sonene skravert på bakveggen, målsatt fra
    ferdig gulv, høyderisset inntegnet — asserten krever at hvert felt
    matcher WALL_ZONES. Målefigur på side 3: oppriss + plan, uten ord.
    Kappeplanen pakker nå overmålet — hettene forbruker bordlengde, og
    brukt-tallet er det sagen faktisk tar. Meddrag-piktogram: avstands-
    kloss, ikke tommestokk. Assert-tellingen i README er talt, ikke
    anslått, med metoden i parentesen. 135 til 144 artefakter, 82 sider.
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
